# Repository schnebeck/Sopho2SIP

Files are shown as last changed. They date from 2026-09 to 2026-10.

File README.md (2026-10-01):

# ErgoLine D340 – Protokoll der PC-Schnittstelle

Offene Dokumentation des seriellen Protokolls, mit dem ein PC ein Philips-Systemtelefon **ErgoLine D340**
(Anlage **Sopho iS3000**, Telekom-Variante Octophon 340) steuert: Anrufe erkennen – mit Anrufernummer –,
annehmen, wählen und auslösen. Ziel: Jede und jeder soll damit einen eigenen TAPI- oder SIP-Daemon bauen können.

**➜ Spezifikation lesen: [schnebeck.github.io/Sopho2SIP/protokoll.html](https://schnebeck.github.io/Sopho2SIP/protokoll.html)**
(im Repository: [`docs/protokoll.html`](docs/protokoll.html))

Die Spezifikation enthält Rahmenformat, alle Meldungen und Aufträge, Zeitverhalten, Ablauf- und Zustandsdiagramme,
die Zuordnung zu SIP und einen Leitfaden für den Daemon. Jede Angabe ist gekennzeichnet als
**bestätigt** (am Gerät gemessen), **Treiber** (aus dem Philips-Treiber abgeleitet) oder **vermutet**.

## Kurzfassung

| | |
|---|---|
| Anschluss | 9-polige Buchse hinten am Telefon, 1:1-Kabel, Pin 2/3/5 |
| Freischaltung | am Telefon: Merkmale → Optionen → „TAPI: Sprache über Telefon“ = Ein |
| Leitung | 1200 Baud, 8O1 |
| Rahmen | `Klasse · Länge · Nutzdaten` – ohne Prüfsumme, ohne Start-/Endzeichen |
| Klassen | `01` Auftrag PC · `02` Meldung Telefon · `03` REJ · `04` ACK · `05` ERR |
| Meldungen | `30` RINGING (mit Anrufernummer) · `31` CONNECTED · `32` DISCONNECTED · `36` DIALTONE · `39` RELEASED · `3e` PROCEEDING · … |
| Aufträge | Anmelden `01 02 01 00` · Wählen `01 L 19 00 98 70 …` · Annehmen `01 02 14 00` · Auflegen `01 02 13 00` |

## Stand

- Empfangsrichtung vollständig mitgeschnitten und entschlüsselt (Anruf mit Nummer, Wahl, Verbindung, Auslösung).
- Senderichtung aus dem originalen Philips-Treiber abgeleitet; der erste Test am Gerät steht aus
  ([`docs/testplan.md`](docs/testplan.md)).
- Offene Fragen stehen am Ende der Spezifikation.

## Weitere Dokumente

| Datei | Inhalt |
|---|---|
| [`docs/protocol.md`](docs/protocol.md) | Arbeitsnotizen zum Protokoll mit Log-Verweisen |
| [`docs/audio_verkabelung.html`](https://schnebeck.github.io/Sopho2SIP/audio_verkabelung.html) | Schaltplan: Audio-Buchse über 600-Ω-Übertrager an die USB-Soundkarte (vorläufig) |
| [`docs/hardware.md`](docs/hardware.md) | Pinbelegung, Messwerte, Menüpunkte, Wartungsmodus des Telefons |
| [`docs/sackgassen.md`](docs/sackgassen.md) | Irrwege, z. B. der inkompatible Octophon-Treiber mit AT-Befehlen |
| [`docs/testplan.md`](docs/testplan.md) | nächste Tests am Gerät |
| [`logs/INDEX.md`](logs/INDEX.md) | Mitschnitte, die die Angaben belegen (Rufnummern durch Platzhalter ersetzt) |
| [`ref/ergoline_tsp/QUELLE.md`](ref/ergoline_tsp/QUELLE.md) | Herkunft des Philips-Treibers (Wayback Machine) mit Prüfsummen |

## Referenzimplementierung (experimentell)

Python 3 mit `pyserial`, keine weiteren Abhängigkeiten:

- `gateway/ergoline/protocol.py` – Rahmen, Meldungen, Aufträge (ohne Ein-/Ausgabe)
- `gateway/ergoline/link.py` – serielle Verbindung mit Quittung und Sitzungslog
- `gateway/ergoline/zustand.py` – Zustandsautomat nach dem Vorbild des Philips-Treibers
- `gateway/sopho2sipd.py` – Daemon: Verbindung, Anmeldung, Keepalive, Anrufdatensätze als JSON-Datei/Webhook ([`docs/anrufdaten.md`](docs/anrufdaten.md))
- `tools/ergo.py` – Mitschnitte dekodieren, mitlesen, Aufträge senden
- Tests: `python3 -m unittest discover -s gateway/tests -v`

```
tools/ergo.py decode logs/serial_20260930_163534.log
gateway/sopho2sipd.py --wiedergabe logs/serial_20260930_163534.log --anrufe -
```

Die Spezifikation wird mit `tools/build_protokoll_doc.py` aus `docs/protokoll.tpl.html` erzeugt.

## Nicht enthalten: der Philips-Treiber

Der Philips-Treiber (`Ergoline.tsp`), Handbuch-Auszüge und das Benutzerhandbuch sind urheberrechtlich geschützt
und liegen nicht im Repository. Der Treiber ist in der Wayback Machine archiviert:

- Direkt-Download: [ergoline.zip (Wayback Machine, 2010-12-01)](https://web.archive.org/web/20101201193039id_/http://tapicall.de/tapi-treiber/nec_philips/telefone/ergoline-serie/ergoline_d330/ergoline.zip)
- SHA-256 `ergoline.zip`: `d278ae82b84d656354e80f650fbd9ae9816d62526e92ea5dcb5483e05b374daf`
- SHA-256 `Ergoline.tsp` (im ZIP): `2b5b2b3e2e3ff51a2ca666b7bc874e9e9d81551a3f67c5357ea8ea297f50b282`

Weitere Fundstellen: [`ref/ergoline_tsp/QUELLE.md`](ref/ergoline_tsp/QUELLE.md) und Abschnitt Quellen der Spezifikation.

## Lizenz

Der Code (`gateway/`, `tools/`) steht unter der **GNU General Public License v3.0 oder später**
(`GPL-3.0-or-later`, siehe [`LICENSE`](LICENSE)). Für die Dokumentation gilt keine gesonderte Lizenz.

## Vorsicht

Eine Telefonanlage lässt sich nicht beliebig zurücksetzen. Nur dokumentierte Aufträge senden, nichts raten, und am
Telefon weder das Service-Menü noch die Wartungscodes 31–34 benutzen.

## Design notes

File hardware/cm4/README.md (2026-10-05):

# Sopho2SIP-Träger für Compute Module 4 (Entwurf 0.3)

Trägerplatine für das Raspberry Pi **Compute Module 4** als Gerät zum Einstecken: alle Kabel hinten, kurze Wege zur
D340, vorne µSD, Status-LEDs und drei Taster (Annehmen, Konfiguration, Ein/Aus); Lüfter temperaturgesteuert;
Gehäuse aus dem 3D-Drucker.

- **Speicher:** CM4 mit **eMMC** *oder* **CM4 Lite** mit **µSD-Karte**. Der Sockel ist immer bestückt. Beim
  eMMC-Modul sind die SD-Pins im Modul offen, der Sockel bleibt dann ungenutzt.
- **Netz:** **WLAN** über das CM4 mit Funk (Antenne auf dem Modul, zur linken Platinenkante; oder U.FL)
  *oder/und* **Ethernet 10/100** (RJ45 mit Übertrager). Der Betrieb wird per Software gewählt.
- **D340:** isolierte RS-232 (ADuM5211 + MAX3232, **4P4C-Buchse**) und Sprechweg über zwei Übertrager (RJ12).
  Zur D340 führt ein Adapterkabel 4P4C → DE9-Stecker (4P4C 1 → 5 GND, 2 → 2 RxD, 3 → 3 TxD).

| Datei | Inhalt |
|---|---|
| `erzeuge_schaltplan.py` | hierarchischer Schaltplan: `SOLL_*` (Verbindungen je Blatt), `blatt_*()` (Zeichnung), `main()` (Wurzelblatt) |
| `erzeuge_layout.py` | Leiterplatte aus der KiCad-Netzliste: Platzierung, Lagen, Flächen, Sperrzonen, Regeln, Routing, DRC, Fertigungsdaten |
| `erzeuge_bestellliste.py` | `stueckliste_digikey.csv` mit Herstellernummern und Digikey-Bestand |
| `sopho2sip-cm4.kicad_sch`, `*.kicad_sch` | Wurzelblatt und Kindblätter (erzeugt) |
| `sopho2sip-cm4.kicad_pcb`, `.kicad_dru` | Leiterplatte und JLCPCB-Regeln (erzeugt) |
| `sopho2sip.kicad_sym`, `sym-lib-table`, `fp-lib-table` | Projektbibliotheken; eigene Footprints in `hardware/bibliothek/` |
| `sopho2sip-cm4.pdf` | alle 9 Schaltplanblätter |
| `netzliste.txt`, `stueckliste.csv` | Soll-Netzliste, KiCad-Stückliste |
| `handlage/`, `.generiert.json` | von Hand nachgebesserte Blätter; Fingerabdrücke der zuletzt erzeugten Zeichnung |

Neu erzeugen und prüfen:
```
hardware/bibliothek/erzeuge_footprints.py         # eigene Footprints (Übertrager, RJ12, DF40 mit Pins 101–200)
hardware/cm4/erzeuge_schaltplan.py --pruefen      # ERC + Abgleich der Netzliste mit SOLL
hardware/cm4/erzeuge_layout.py --routen --pruefen # Platine, FreeRouting, DRC
hardware/cm4/erzeuge_layout.py --nur-fertigung    # Gerber/Bohrdaten/Bestückung/STEP/Bild nach fertigung/
hardware/cm4/erzeuge_bestellliste.py
```
Die UUIDs sind reproduzierbar: Schaltplan und Platine bleiben beim Neuerzeugen verknüpft („Platine aus Schaltplan
aktualisieren“ in KiCad funktioniert weiter).

**Zeichnung von Hand nachbessern:** Blätter in KiCad schöner setzen (Bauteile, Beschriftungen, Leitungen, Labels
verschieben) und speichern, dann den Generator laufen lassen. Er erkennt die geänderten Blätter am Fingerabdruck der
Zeichnung, prüft die Netzliste gegen SOLL und übernimmt sie nach `handlage/`. Ab dann kommt die Zeichnung dieser
Blätter von dort; Werte, Footprints und Symbole weiter aus SOLL (in KiCad geänderte Werte werden mit Hinweis
zurückgesetzt). Ändert die Handarbeit eine Verbindung, schreibt der Generator nichts und nennt die Abweichung.
```
hardware/cm4/erzeuge_schaltplan.py --pruefen                          # Änderungen im Projektordner übernehmen
hardware/cm4/erzeuge_schaltplan.py --handlage-aus ~/kopie --pruefen    # … aus einer Kopie des Projekts
hardware/cm4/erzeuge_schaltplan.py --handlage-verwerfen Bedienung      # Blatt wieder vom Generator zeichnen lassen
```
Kommt in SOLL ein Bauteil auf einem Blatt mit Handlage hinzu (oder fällt weg), bricht der Generator ab: das Blatt in
KiCad nachziehen oder die Handlage verwerfen.

**Texte** (Hinweiskästen, Texte, Blocktitel) gehören dem Generator. In KiCad geänderte Texte schreibt der Generator
an die Stelle im Quelltext zurück, an der sie entstehen (`p.notiz(…)`, `p.text(…)`, `rahmen_(…)`); ein neuer Absatz
im Kasten wird ein weiteres Argument von `notiz`. Ersetzt wird nur, wenn dort feste Literale genau den bisherigen
Text ergeben; sonst bleibt der Text als Handtext in `.generiert.json` und wird gemeldet. Ändert sich nur Text, nicht
die Lage, entsteht keine Handlage. In KiCad neu angelegte oder gelöschte Texte meldet der Generator nur.
Hinweise stehen in Textkästen (`notiz`): KiCad bricht innerhalb der Kastenbreite um, die Höhe schätzt der Generator.

## Blätter und Bauteile

| Blatt | Bauteile | Warum |
|---|---|---|
| CM4 | J11/J12 **Hirose DF40C-100DS-0.4V(51)** (1,5 mm Stapelhöhe), C40/C41, H5–H8 | Pinbelegung und Lage aus Datenblatt und CM4IO-Referenzlayout; **GPIO_VREF = 3,3 V** |
| | JP10 **nRPIBOOT** | gesteckt: das CM4 startet als USB-Gerät → `rpiboot` über USB-C, eMMC erscheint als Laufwerk |
| | D10 (ACT), Q10 **BSS84** + D11 (PWR) | Aktivitäts-Pin senkt bis 20 mA; PI_LED_nPWR muss laut Datenblatt gepuffert werden |
| Versorgung | J10 **USB-C** GCT USB4105, F1 Polyfuse 2 A, D12 **SMAJ5.0CA**, R10/R11 5,1 kΩ, U10 **USBLC6-2SC6** | eine Buchse für 5 V und USB 2.0 (rpiboot) |
| µSD | J13 Hirose DM3AT, U11 **AP22804AW5**, R14 12 kΩ | Lastschalter für die Kartenspannung wie Datenblatt (dort RT9742) |
| Ethernet | J14 **Würth 7499010211A** (RJ45 mit Übertrager, LEDs), U12 **TPD4E05U06**, C45, R15/R16 | Mittelanzapfungen über 100 nF an GND, ESD an den Paaren, LEDs low-aktiv |
| Audio-Codec | U2 **TI TLV320AIC3204** (VQFN-32), U6 Oszillator 12 MHz, U4 AP2112K-3.3 | **WM8731 ist abgekündigt**, SGTL5000/WM8960 ebenso bzw. nicht lieferbar. Der AIC3204 hat einen Linux-Treiber (`tlv320aic32x4`); Vorlage für das Overlay ist `audiosense-pi` (I²C 0x18, MCLK 12 MHz, Reset an GPIO26). **I²C an GPIO0/1 (I2C0)**, weil GPIO3 der Ein/Aus-Taster ist. LOL treibt den 600-Ω-Übertrager (Last ≥ 600 Ω laut Datenblatt) |
| Sprechweg | T1/T2 **Bourns SM-LP-5001** (600:600, 2 kV), J2 **Würth 615006138421** (RJ12/6P6C) | Amphenol 54601 ist abgekündigt |
| RS-232 | U3 **ADuM5211**, U5 **MAX3232E**, J3 **Würth 615004143821** (4P4C liegend) | statt DE9 (31 mm Kante, 13 mm hoch): verriegelnd, klein, nicht mit RJ12/RJ45 verwechselbar |
| CM4 selbst | M1 Platzhalter | steht in der Stückliste, wird gesteckt (nicht in den Bestückungsdaten); 3D-Modell 1,5 mm über J11/J12 |
| Bedienung | SW1 Annehmen/Auflegen (GPIO25), **SW2 Konfiguration (GPIO27)**, **SW3 Ein/Aus (GPIO3)**, D1–D3 (GPIO23/24/22) | D3 + SW2 für Einstellungen am Gerät; alle LEDs vorne für Lichtleiter |
| | SW3, R9 (unbestückt) | **Ein/Aus mit einem Taster:** im Betrieb fährt `gpio-shutdown` sauber herunter; im Halt weckt der Bootloader das CM4 über GPIO3 (`WAKE_ON_GPIO=1`, Werkseinstellung). GLOBAL_EN bleibt unbenutzt (Datenblatt: nur nach dem Herunterfahren auf Low ziehen) |
| Lüfter | Q11 **AO3400A**, D13 **MBR140SFT1G**, R17/R18, C46, J15 **JST PH 2-polig** | 5-V-Lüfter, Low-Side-Schalter an GPIO12 (PWM-fähig); die SoC-Temperatur des CM4 steuert über `gpio-fan` |

Die vollständige Bestellliste mit Digikey-Nummern und dem am 2026-10-03 geprüften Bestand steht in
`stueckliste_digikey.csv`. Keramikkondensatoren und Widerstände sind Standardteile; deren Bestand schwankt, der
Digikey-BOM-Manager schlägt gleichwertige Teile vor.

## Leiterplatte

- **Maße:** 110 × 85 mm, 4 Lagen, 1,6 mm, JLCPCB-Aufbau **JLC04161H-7628** (bei der Bestellung „Impedance Control“
  mit diesem Aufbau wählen).
- **Lagen:** F.Cu Signale · **In1 GND** · **In2 +3V3** · B.Cu Signale. Außenlagen nach dem Routing mit Masse gefüllt.
- **Impedanz** (berechnet, mit dem JLC-Rechner gegenprüfen): Ethernet 100 Ω differenziell = 0,20 mm / 0,17 mm,
  USB 90 Ω = 0,22 mm / 0,13 mm (Mikrostreifen über 0,21 mm Prepreg).
- **Anordnung:** hinten USB-C, RJ45, DE9, RJ12; CM4 links mit der Antenne zur linken Kante (kupferfreie Zone
  9,5 × 15 mm auf allen Lagen, Datenblatt: mind. 8 × 15 mm); vorne µSD, LEDs, Taster.
- **Isolation:** GND_ISO (RS-232) und GNDA (Sprechweg) sind eigene Bereiche mit eigenen Flächen auf allen Lagen.
  1 mm breite kupferfreie Trennstreifen auf allen Lagen; nur der ADuM5211 und die Übertrager überbrücken sie.
- **Regeln:** JLCPCB-Standard (Bahn/Abstand ≥ 0,09 mm, Bohrung ≥ 0,15 mm, Kupfer zur Kante ≥ 0,3 mm), in
  `sopho2sip-cm4.kicad_dru`; Standardbahn 0,15 mm, Durchkontaktierung 0,3/0,55 mm.
- **Routing:** Der Generator setzt zuerst selbst eine Durchkontaktierung an jedes SMD-Pad der Ebenennetze (GND,
  +3V3, GND_ISO, +3V3_ISO, GNDA; 144 Stück, mit Kollisionsprüfung), dann routet **FreeRouting 1.9.0** die übrigen
  Netze (Specctra DSN/SES, 30 Durchgänge, rund eine Stunde). FreeRouting 1.9 braucht eine Oberfläche und läuft
  unsichtbar über `xvfb-run` (Paket `xvfb`); das Werkzeug wird nach `hardware/.werkzeug/` geladen und per SHA-256
  geprüft. FreeRouting 2.x wurde verworfen: Telemetrie ab Werk an, hielt die Durchgangszahl nicht ein.
- **Stand:** vollständig geroutet, **DRC ohne Verstöße**, keine offenen Verbindungen, Schaltplan und Platine stimmen
  überein. Ethernet und USB sind vom Router als Einzelleitungen mit der Paarbreite verlegt, nicht als gekoppelte
  Differenzpaare (für 10/100 und USB 2.0 auf diesen Längen unkritisch; vor der Bestellung ansehen).
- **3D-Modelle:** CM4 offiziell von Raspberry Pi, die übrigen Herstellermodelle (Würth, Hirose, Bourns, ECS) liegen
  nur lokal in `hardware/bibliothek/3d/` (nicht weitergebbar, Quellen und Prüfsummen in `QUELLEN.md`).
  `hardware/bibliothek/richte_3d_aus.py` richtet sie auf die Footprints aus; die Steckerlagen sind im Rendering von
  unten geprüft (alle Pins, Zapfen und Schirmlaschen mittig in ihren Bohrungen).
- `--nur-nacharbeit` erneuert Beschriftung, Bestückungsattribute und Flächen ohne neues Routing. Konstruiert wird
  bei (100, 100); zum Schluss rückt die Platine auf dem A4-Blatt nach (93, 45), frei vom Schriftfeld. Alle
  Bauteiltexte stehen waagerecht.
- **Beschriftung:** Platinentexte stehen in `beschriftung.json` (Inhalt, Lage, Drehung, Größe, Strichstärke, Lage
  der Ebene, Sichtbarkeit, Ausrichtung, gespiegelt, fett, kursiv, aufrecht, ausgespart), dazu Abweichungen der
  Bauteiltexte (Referenz, Wert, eigene Footprint-Texte; Lage relativ zum Bauteil). In KiCad geänderte, neue oder
  gelöschte Beschriftungen übernimmt jeder Lauf von `erzeuge_layout.py` (außer `--nur-pruefen`/`--nur-fertigung`)
  vorab nach `beschriftung.json`; Vergleichsgrundlage ist `.beschriftung_stand.json` (Stand des letzten Laufs).
  Überlappungen meldet der DRC (`silk_overlap`). Bauteillagen und Leiterbahnen werden nicht zurückgeführt.

## Konfiguration (`/boot/firmware/config.txt`)
```
dtparam=i2s=on
dtparam=i2c_vc=on          # I2C0 an GPIO0/1 für den Codec
dtoverlay=sopho2sip-codec  # noch zu schreiben (nach audiosense-pi, aber i2c0): TLV320AIC3204, 0x18, 12 MHz, Reset GPIO26
dtoverlay=gpio-shutdown,gpio_pin=3   # Ein/Aus-Taster: Druck = sauber herunterfahren
dtoverlay=gpio-fan,gpiopin=12,temp=60000   # Lüfter ab 60 °C SoC-Temperatur
dtoverlay=uart3            # GPIO4/5 → /dev/ttyAMA3 (Name nach dem Booten prüfen)
dtparam=ant2               # nur bei externer WLAN-Antenne (U.FL)
```
Bootloader-EEPROM: `WAKE_ON_GPIO=1` (Werkseinstellung) und `POWER_OFF_ON_HALT=0` lassen, sonst weckt der Taster
nicht. Taster, langer Druck zum Ausschalten und STATUS-LED beim Herunterfahren richtet `tools/ein_aus_einrichten.sh`
ein (Ablauf in `docs/betrieb.md`). eMMC beschreiben: JP10 stecken, USB-C mit dem Rechner verbinden, `rpiboot` ausführen, Image schreiben, JP10 ziehen.

## Vor der Fertigung prüfen (offen)
- **Codec:** Overlay für I2C0 schreiben; Mixer-Einstellungen (IN1_L → ADC, DAC → LOL) mit `amixer` festlegen.
- **Ein/Aus:** Wecken über GPIO3 am CM4 erproben (bei Bedarf R9 als Pull-up bestücken).
- **Lüfter:** Lüftertyp festlegen (5 V, ≤ 200 mA, 2-polig mit JST-PH-Stecker oder umcrimpen) und im Deckel über dem
  CM4 vorsehen.
- **Ethernet:** Das CM4 hat einen Gigabit-PHY. Die 2-Paar-Buchse trägt nur 10/100. Prüfen, ob der PHY bei nur zwei
  Paaren sicher auf 100 Mbit herunterschaltet, sonst per `ethtool` festlegen.
- **3,3 V vom CM4:** höchstens 600 mA. Verbraucher: Codec (Digital, Oszillator), ADuM5211 (Logikseite), µSD-Karte
  (bis ~100 mA), LEDs. Summe aus den Datenblättern bilden.
- **AP22804 statt RT9742:** Pinbelegung, EN-Polarität und Strombegrenzung gegen das Datenblatt prüfen.
- **USB_OTG_ID** (Pin 101) ist offen. Normalbetrieb mit `dtoverlay=dwc2,dr_mode=…` festlegen.
- **RJ12-Footprint:** aus der Würth-Zeichnung abgeleitet; Lage der Steckseite zur Platinenkante am Muster prüfen.
- **Mechanik:** Gehäuse für den FDM-Druck in `hardware/gehaeuse/` (Lichtleiter über D1–D3, D10, D11; Biegezungen mit
  Stößel über SW1–SW3; Lüfter 30 mm). Erstdruck steht aus.
- Die Prüfpunkte des HAT gelten weiter (ADuM5211, Übertrager, RJ12-Kabel, MAX3232E): `hardware/hat/README.md`.

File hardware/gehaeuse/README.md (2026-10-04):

# Gehäuse für den CM4-Träger (FDM-Druck)

Zweiteiliges Gehäuse für `hardware/cm4` (Leiterplatte 110 × 85 mm), druckbar ohne Stützmaterial.
Außenmaß **115,6 × 90,6 × 25,1 mm**. Die Buchsen liegen hinten, Tasten und Anzeigen oben an der Vorderkante.

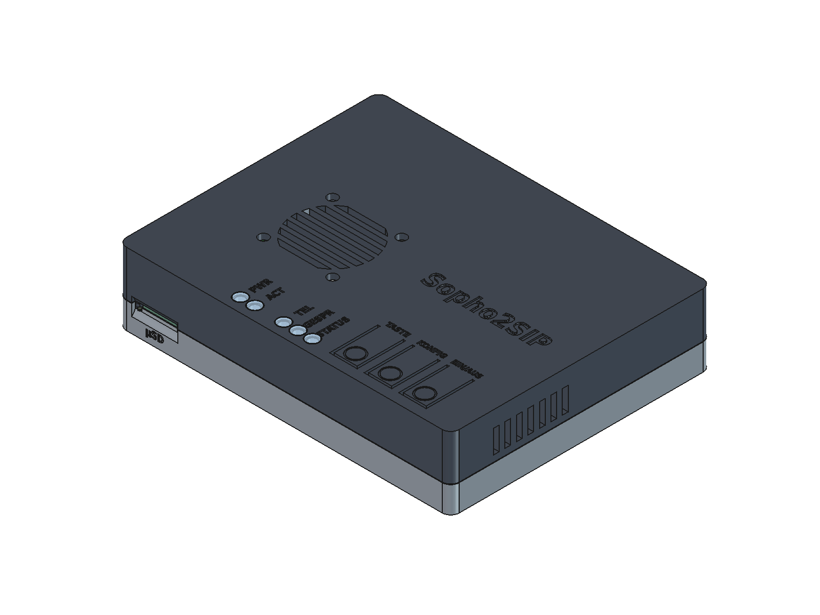
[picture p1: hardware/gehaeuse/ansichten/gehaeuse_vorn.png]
Gehäuse


| Teil | Datei | Drucklage |
|---|---|---|
| Unterschale | `druck/unterschale.stl` | Boden auf dem Druckbett |
| Deckel | `druck/deckel.stl` | Oberseite auf dem Druckbett (kopfüber) |
| 5 Lichtleiter | `druck/lichtleiter_5x.stl` | Kopf auf dem Druckbett |

`gehaeuse.step` und `gehaeuse.FCStd` enthalten die Teile in Einbaulage.

## Aufbau

- **Trennebene** auf Höhe der Platinenoberseite. Die äußere Wandhälfte der Unterschale steht 2 mm hoch und greift
  in eine Stufe des Deckels; das zentriert den Deckel.
- **Verschraubung:** 4 × M2.5 von unten durch die Unterschale und die Bohrungen H1–H4 der Platine in
  Gewindeeinsätze der Deckelsäulen. Die Platine liegt auf Stützen und wird zwischen Stütze und Säule geklemmt.
  Unter jedem Taster stützt ein Zapfen die Platine gegen den Tastendruck.
- **Tasten** (SW1 Taste, SW2 Konfig, SW3 Ein/Aus): Biegezungen im Deckel (16 × 8 mm, von innen auf 1,2 mm gedünnt,
  Gelenk hinten). Der Stößel Ø 4 mm steht 0,35 mm über der Tasterkappe. Ein Ring markiert die Druckstelle.
- **Anzeigen** (D11 PWR, D10 ACT, D1 TEL, D2 GESPR, D3 STATUS): Lichtleiter Ø 3 mm in Röhren, die bis 0,6 mm über
  die LED reichen und Übersprechen zwischen den LEDs verhindern. Die Köpfe liegen bündig in Senkungen.
- **Buchsen hinten:** USB-C (Ausschnitt 12,4 × 6,6 mm für Steckertüllen), RJ45 LAN, 4P4C D340 PC, RJ12 D340 Audio;
  Beschriftung unter den Ausschnitten.
- **µSD vorn:** Schlitz mit Griffmulde. Die Karte (Push-Push) wird mit dem Fingernagel betätigt. Bei einem CM4 mit
  eMMC bleibt der Schlitz unbenutzt.
- **Kühlung:** Lüfter 30 × 30 × 7 mm unter dem Deckel über dem SoC des CM4 (3,9 mm Luft). Er saugt durch das Gitter
  im Deckel an und bläst auf das CM4; die Luft tritt durch die Schlitze in den Seitenwänden aus.
  Lüfter mit der Aufkleberseite zur Platine einbauen (Blasrichtung meist zum Aufkleber).
  Anschluss an J15 (JST PH, 2-polig).

## Zukaufteile

| Menge | Teil | Hinweis |
|---|---|---|
| 4 | Gewindeeinsatz M2.5, L 5,7 mm, Ø 4 mm (z. B. Ruthex RX-M2.5x5.7) | Loch Ø 3,6 × 6,5 mm |
| 4 | Zylinderschraube ISO 4762 M2.5 × 10 | Kopf versenkt (Ø 5,2 × 2,6 mm) |
| 1 | Lüfter 30 × 30 × 7 mm, 5 V, Stecker JST PH 2-polig | Lochabstand 24 mm |
| 4 | Blechschraube M3 × 8 … 10 (meist beim Lüfter) | von außen durch den Deckel |
| 4 | Klebefuß Ø ≤ 10 mm | Mulden 0,6 mm tief |

## Druck

- **Material:** PETG oder ASA (das CM4 erwärmt das Innere; PLA wird ab ~55 °C weich). Lichtleiter aus klarem PETG.
- Düse 0,4 mm, Schicht 0,2 mm, 3 Wandlinien, 20 % Füllung. Lichtleiter: 100 % Füllung, langsam.
- Kein Stützmaterial nötig. Beim Deckel liegen die Beschriftungen auf dem Druckbett; die vertieften Buchstaben
  werden in der ersten Schicht überbrückt.
- Die Biegezungen brauchen ein zähes Material (PETG/ASA). Ist die Taste zu schwer, `ZUNGE_D` verkleinern.

## Montage

1. Gewindeeinsätze mit dem Lötkolben in die vier Deckelsäulen setzen (PETG ~230 °C).
2. Lichtleiter von außen in den Deckel stecken (straff; notfalls ein Tropfen Klebstoff unter den Kopf).
3. Lüfter von innen an den Deckel schrauben.
4. CM4 auf den Träger stecken. Platine mit den Buchsen nach hinten in die Unterschale legen.
5. Lüfterkabel an J15 stecken, Deckel aufsetzen, von unten verschrauben. Klebefüße aufkleben.

## Erzeugen und prüfen

```
python3 hardware/gehaeuse/erzeuge_masse.py          # masse.json und platine_bestueckt.step (≈ 5 min) aus KiCad
flatpak run --command=freecadcmd org.freecad.FreeCAD $PWD/hardware/gehaeuse/freecad_gehaeuse.py
python3 hardware/gehaeuse/vorschau.py               # Querschnitte → vorschau_schnitte.png
xvfb-run -a -s "-screen 0 1600x1200x24" flatpak run org.freecad.FreeCAD $PWD/hardware/gehaeuse/freecad_ansichten.py
```

Alle Maße stehen als Konstanten am Anfang von `freecad_gehaeuse.py`. Die Bauteillagen kommen aus der Platine
(`masse.json`), die Bauteilhöhen aus dem bestückten STEP.

Das Skript prüft das Gehäuse gegen die bestückte Platine (`pruefung.txt`): keine Überschneidung, Stößel 0,35 mm
über den Tastern, Lüfter 3,87 mm über dem CM4. Die Querschnitte durch Taster, LED und Schraubsäule zeigt
`vorschau_schnitte.png`.

## Offen (nach dem ersten Druck prüfen)

- Passung der Gewindeeinsätze, der Lichtleiter (Bohrung 3,4 / Stab 3,0) und des Deckels auf dem Zentrierrand.
- Tastengefühl und Leerweg (`TASTE_SPIEL`, `ZUNGE_D`).
- Ob die Steckertüllen der eigenen USB-C- und RJ-Kabel in die Ausschnitte passen.
- Ob die Lüfterleistung reicht (Temperatur des CM4 unter Last mit `vcgencmd measure_temp`).

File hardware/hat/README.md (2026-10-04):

# Sopho2SIP-HAT (Entwurf 0.2)

HAT für den Raspberry Pi 4, der die Verbindung zur ErgoLine D340 auf eine Platine bringt: **isolierte RS-232** zur
PC-Schnittstelle (statt FTDI-Adapter) und **Audio-Codec mit Übertragern** zur Audio-Buchse (statt UCA222).

| Datei | Inhalt |
|---|---|
| `erzeuge_schaltplan.py` | erzeugt den Schaltplan aus den KiCad-Standardbibliotheken: `SOLL` (Verbindungen) und je Block eine Zeichenfunktion (`pi_leiste`, `hat_eeprom`, `codec`, `sprechweg`, `rs232`, `bedienung`); Generator-Grundlage `hardware/kicadgen.py` |
| `sopho2sip-hat.kicad_sch/.kicad_pro` | KiCad-10-Projekt (erzeugt) |
| `sopho2sip-hat.pdf` | Schaltplan zum Ansehen |
| `netzliste.txt` | Soll-Netzliste (Netz → Pins) aus `SOLL` |
| `stueckliste.csv` | Stückliste (KiCad-Export) |

Neu erzeugen und prüfen:
```
hardware/hat/erzeuge_schaltplan.py --pruefen     # ERC + Abgleich der KiCad-Netzliste mit SOLL (Stand: 0 / 0)
kicad-cli sch export pdf -o hardware/hat/sopho2sip-hat.pdf hardware/hat/sopho2sip-hat.kicad_sch
```
Der Plan ist gezeichnet wie von Hand: Funktionsblöcke mit Rahmen, Signalfluss von links nach rechts, Leitungen
innerhalb der Blöcke, Abblockkondensatoren an den Versorgungsschienen, Labels nur zwischen den Blöcken, galvanische
Trennung als Strichpunktlinie. Die Prüfung vergleicht die Pin-Gruppen der KiCad-Netzliste mit `SOLL`; so kann die
Zeichnung umgestaltet werden, ohne unbemerkt Verbindungen zu ändern. Änderungen am besten im Skript; wer in KiCad
weiterzeichnet, verlässt den Generator (dann ERC und Netzliste dort prüfen).

Versorgungsnetze: `GND`, `+3V3`, `+5V` (Pi), `+3.3VA` (Codec analog), `GNDA` (Telefonseite Audio),
`GND_ISO`, `+3V3_ISO` (isolierte RS-232-Seite) – jeweils als Power-Symbol mit sichtbarem Netznamen.

## Blöcke und Begründungen

| Block | Bauteile | Warum |
|---|---|---|
| Pi-Anschluss | J1 Buchsenleiste 2×20 | HAT-Standard |
| Seriell | **UART3** an GPIO4 (TXD3) / GPIO5 (RXD3) | PL011 – der Mini-UART (GPIO14/15) kann **keine Parität**, die D340 braucht **1200 Bd 8O1**; GPIO14/15 bleiben für Bluetooth, GPIO0/1 für das HAT-EEPROM |
| Trennung | U3 **ADuM5211** | Digitaltrenner (je ein Kanal hin/zurück) **mit eingebauter isolierter Versorgung** (VSEL = GND_ISO → 3,3 V) – ein Chip statt Trenner + DC-DC |
| RS-232 | U5 **MAX3232** (isolierte Seite), J3 **DE9-Stecker** | Pegel ±5 V wie gemessen; Stecker wie am PC (DTE): Pin 2 RxD, Pin 3 TxD, Pin 5 GND → vorhandenes 1:1-Kabel |
| Audio | U2 **WM8731SEDS** (SSOP-28, handlötbar), Y1 12,288 MHz | Linux-Treiber, Overlay `rpi-proto` (genau dieser Codec); 8 kHz direkt; ADC-Hochpass macht `dcsperre` überflüssig |
| Sprechweg | T1/T2 **Bourns SM-LP-5001** (600:600), C21/C24 1 µF, J2 **RJ12** Würth 615006138421 | wie die erprobte Verkabelung (`docs/audio_verkabelung.html`): beide Richtungen galvanisch getrennt; **LHPOUT** (Kopfhörerverstärker) treibt T2 – LOUT ist nur für ≥ 10 kΩ |
| Teiler-Option | R4 = 0 Ω, R5 unbestückt | im Test war kein Teiler nötig (Pegel per Software); Option bleibt |
| Analogversorgung | U4 **AP2112K-3.3** aus 5 V | eigene, ruhige 3,3 V für AVDD/HPVDD |
| HAT-ID | U1 **24LC32**, R1/R2 3,9 kΩ, R3 + JP1 | HAT-Spezifikation: EEPROM an ID_SD/ID_SC, Adresse 0x50, WP hoch (JP1 schließen zum Schreiben) |
| Bedienung | D1/D2 an GPIO23/24, SW1 an GPIO25 | Telefon-Status / Gespräch / Annehmen-Auflegen (interner Pull-up) |

Galvanische Verhältnisse: Telefonseite (TEL_GNDA, ISO_GND) ist vom Pi (GND) **vollständig getrennt** – Audio über die
Übertrager, Seriell über den ADuM5211. Im bisherigen Aufbau war die serielle Masse die einzige leitende Verbindung.

## Konfiguration auf dem Pi (`/boot/firmware/config.txt`)
```
dtparam=i2s=on
dtoverlay=rpi-proto        # WM8731 (I²C 0x1A), Codec erzeugt die Takte aus 12,288 MHz
dtoverlay=uart3            # GPIO4/5 → /dev/ttyAMA3 (Name nach dem Booten prüfen)
```
Danach: Daemon mit `--port /dev/ttyAMA3`, baresip `audio_player/audio_source alsa,plughw:<Karte>,0`. Mit
HAT-EEPROM kann der Pi die Overlays auch selbst laden (EEPROM mit `eepromutils` beschreiben).

## Vor der Fertigung prüfen (offen)
- **ADuM5211:** VDD1 = 3,3 V (Logikpegel zum Pi) bei VDDP = 5 V zulässig? Polarität von VSEL; Ausgangsleistung für
  MAX3232 + ADuM-Seite 2 (einige mA). Datenblatt.
- **WM8731:** Quarzbeschaltung (Lastkapazität des gewählten Quarzes → C10/C11), unbenutzte Eingänge (RLINEIN, MICIN)
  laut Datenblatt beschalten oder offen lassen.
- **WM8731 ist abgekündigt** (Digikey, 2026-10). Der CM4-Träger (`hardware/cm4/`) nutzt deshalb den TI
  TLV320AIC3204; vor einem Bau des HAT den Codec-Block ebenso umstellen.
- **RJ12-Kabel:** Viele flache Telefonkabel sind gedreht (1↔6). Die Pinbelegung von J2 setzt ein 1:1 belegtes 6P6C
  voraus – mit dem Durchgangsprüfer gegen die D340-Buchse prüfen, sonst Belegung auf der Platine spiegeln.
- **Mechanik:** HAT-Maß 65 × 56,5 mm, Befestigungslöcher 58 × 49 mm; ein liegender DE9 ist hoch – evtl. auf die
  Kante setzen oder Pfostenstecker + Kabel.
- **ESD:** MAX3232**E** (±15 kV) wählen; TVS-Dioden an X_IN/X_OUT erwägen.
- Trägerplatine für das Compute Module 4 mit denselben Blöcken: `hardware/cm4/`.

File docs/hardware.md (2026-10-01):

# Hardware, Verkabelung, Messwerte

Stand 2026-09-30. Widerlegte Verdachte: siehe [`sackgassen.md`](sackgassen.md).

## Telefon
- ERGOLINE 340-2/LG INT (UPN), leitungsgespeist, kein Netzteil angeschlossen, nur 9-polige PC-Buchse (keine V.24-Option).
- Terminal-Software **V4.03.40.01** (Wartungscode 1, abgelesen 2026-09-30).
- Menüsprache Deutsch. Zuordnung (vermutet): Features = Merkmale, Toggle List = Optionen, Set Phone = Einstellungen.
- Merkmale → Optionen enthält „TAPI: Sprache über Zusatzgerät“ und „TAPI: Sprache über Telefon“.
  Stand: **Sprache über Telefon = Ein** (seit 2026-09-30 16:28, damit ist die PC-Schnittstelle aktiv),
  Sprache über Zusatzgerät = Aus.

## PC-Schnittstelle (DB9-Buchse am Telefon)
| Pin | Funktion | Ruhepegel (gemessen 2026-09-30) |
|---|---|---|
| 2 | TxD Telefon → PC | −5 V (am Telefon, Kabel ab) |
| 3 | RxD Telefon ← PC | 0 V am Telefon ohne Kabel; −5 V vom Adapter am Kabelende |
| 5 | GND | – |

Kabel: FTDI-Adapter (Stecker) → 1:1-Verlängerung → Telefon (Buchse). Loopback am Kabelende und Pegelmessung
bestätigen: Kabel 1:1, nicht gekreuzt. Rate/Format: **1200 Baud**, laut Treiber **8O1 + Xon/Xoff** (siehe `protocol.md`).

## Audio-Schnittstelle (RJ11 Unterseite)
| Pin | Funktion | Messwert |
|---|---|---|
| 1 | X_OUT | Gegenseite: Sprache −31 … −43 dBFS RMS, Spitzen −13 dBFS an der UCA222 (Eingang ohne Verstärkung) |
| 2 | X_IN | braucht „X-Eingang statt Mikrofon“; dann passt UCA222-Wiedergabe mit PCM −6 dB (Sprache bis −1 dBFS war leicht übersteuert) |
| 3 | GNDA | – |
Angeschlossen 2026-10-01 (Nutzer): 2 × Übertrager 600:600, C1/C2 1 µF, **ohne** Teiler R1/R2, Cinch `INPUT L`/`OUTPUT L`.
Pinlage wie in [`audio_verkabelung.html`](audio_verkabelung.html) (Pin 1 links) funktioniert in beiden Richtungen.
Messungen mit `tools/audio_test.sh` (Aufnahmen `logs/audio_*.wav`, nur lokal):
- Ruhe: −80 dBFS, kein Brummen; rechter (unbenutzter) Kanal −87 dBFS.
- **Kein Echo:** Testton auf X_IN erscheint auf X_OUT mit < −91 dBFS (Echodämpfung ≈ 75 dB) → X_OUT führt nur die
  Gegenseite, AEC unnötig.
- **X_IN ohne Merkmal 4f sehr leise** (1 kHz bei −16 dBFS kaum hörbar). Mit „X-Eingang statt Mikrofon“ (Merkmal `4f`,
  per FN-Taste oder Auftrag `01 03 26 00 4f`) passt der Pegel; der Daemon schaltet es bei PC-Gesprächen ein.
- PCM-Regler der UCA222 dauerhaft −6 dB (`alsactl store`). Der Drehregler der UCA222 wirkt nur auf den Kopfhörer.
- Vorzeitige Auslösung vom Pi gewählter Gespräche: kein Audioproblem, sondern der 30-s-Watchdog der D340
  (`docs/protocol.md`, Abschnitt 6).

## Messungen
| Datum | Messpunkt | Wert | Deutung |
|---|---|---|---|
| 2026-09-30 | Kabelende telefonseitig (Telefon ab), Pin 2–5 | 0 V | nur Empfänger des Adapters |
| 2026-09-30 | Kabelende, Pin 3–5 | −5 V | Sender des Adapters in Ruhe → Kabel 1:1 |
| 2026-09-30 | Telefonbuchse (Kabel ab), Pin 2–5 | −5 V | Sender des Telefons aktiv |
| 2026-09-30 | Telefonbuchse (Kabel ab), Pin 3–5 | 0 V | Eingang des Telefons |
| offen | Pin 3–5 bei angestecktem Telefon (Last) | – | nicht mehr nötig (Telefon reagiert) |

## Aus den Handbüchern
Quellen: Customer Engineer Manual https://www.manualslib.com/manual/846588/Philips-Ergoline-D330.html (CEM),
User Manual D340 https://www.manualslib.com/manual/715348/Sopho-Ergoline-D340.html (UM),
User Guide D325/D330 `ref/ergoline_tsp/guide_ergoline_d325_d330_english.pdf`. Seiten = PDF-Seiten.

**PC-Schnittstelle**
- Standard bei D330/D340, 1:1-Kabel, TAPI-Treiber auf Diskette (CEM S. 59). Keine Freischaltung beschrieben.
- Keine Baudrate dokumentiert oder einstellbar. Einzige Angabe: Wartungscode 63 „sends a signal from the PC
  interface at 1200 baud“ (CEM S. 72).
- Baudrate, Format, Flusssteuerung, AT-Befehle, S-Register gibt es nur für die **V.24-Option** (CEM S. 51–58;
  Einstellung per Download aus der Anlage, S. 32). Für uns nicht relevant.

**Menü und Merkmale**
- Menübaum: `docs/img/d340_menuebaum.png` (CEM S. 66). `*` = Special Mode (Passwort 2468), `**` = Service Mode (12687).
- Toggle List: „TAPI: speech via accessory“ = Sprachweg auf die Audio-Schnittstelle; „TAPI: speech via phone“ =
  Freisprechen/Hörer/Headset am Telefon (UM S. 45, Glossar S. 97/98). Einträge erscheinen nur, wenn die Anlage
  TAPI für die Nebenstelle unterstützt.
- „X-input instead of mic.“ nur über programmierte Funktionstaste (UM S. 98).
- Voice out „Headset“ oder „Handset without hook“ schaltet den Gabelumschalter ab; dann ist eine Taste
  „On/off hook key for voice“ nötig (UM S. 54).
- ASCII-Tastatur: Infrarot, Kanal 1–3 (CEM S. 62/63). Nichts mit der DB9 zu tun.
- Stromversorgung: leitungsgespeist; Netzteil (8 V~) nur für V.24-Option oder DSS-Module (CEM S. 10, 18, 19).
- **Service-Menü nicht anfassen** (`set TEI`, `reset data`, `download request`, `clean`).

**Wartungsmodus** (CEM S. 69–72)
- Aufruf: Features → SetPhone → SetMode → 12687, dann im Ruhezustand Shift, Hold, nach rechts scrollen, MAINTAIN.
  Testcode + OK, Ende mit CANCEL. Anrufe bleiben annehmbar.
- 1–6 Softwareversionen, 11–14 Display/Tasten/LED (13 ist Umschalter), 61 „Y signal 0 on PC interface“,
  **63 Signal an der PC-Schnittstelle mit 1200 Baud**, 64 X-Interface gespiegelt, 67 V.24.
- Nach Schnittstellentests Hardware-Reset empfohlen (Leitungskabel ziehen).
- **Nie verwenden:** Codes 31–34 (EEPROM löschen) und Tasten `*`, `3`, `5` beim Einstecken des Leitungskabels.

## Gateway
- Konsole: Laptop (KDE neon), Zugriff per `ssh sopho-gw`, Schlüssel `~/.ssh/id_ed25519_sopho-gw`.
- Pi: Raspberry Pi 4, Raspberry Pi OS Lite 64 bit (Debian 13 Trixie), Hostname `sopho-gw`, Nutzer `pi`.
  In Betrieb seit 2026-10-01. Netz: DHCP an eth0 in einem anderen Netz als der Laptop, erreichbar über VPN;
  `.local` geht dort nicht, die IP steht deshalb nur in `~/.ssh/config` des Laptops (nicht im öffentlichen Repo).
  - Image 2026-09-15-raspios-trixie-arm64-lite, per `dd` geschrieben; Erststart per cloud-init
    (`user-data`/`network-config` auf bootfs): Hostname, Nutzer `pi` nur SSH-Schlüssel + NOPASSWD-sudo,
    Europe/Berlin, de, DHCP eth0, avahi, kein WLAN.
  - Der erste Pi 4 (Bootloader 2023-01-11) brach mit `FAT read failed` / `Block device timeout` ab, obwohl
    Netzteil (5,09 V) und Karte (vollständig gelesen, rootfs bytegleich mit dem Image) in Ordnung waren.
    Ein anderer Pi 4 bootet mit derselben Karte; Ursache vermutlich SD-Slot des ersten Geräts.
  - Grundeinrichtung: `ssh sopho-gw 'bash -s' < tools/pi_bootstrap.sh` (2026-10-01 ausgeführt: Pakete, Gruppen
    `dialout`/`audio`, NTP synchron). Repo: `~/Sopho2SIP` (Klon von GitHub, Tests laufen mit Python 3.13).
  - Dienst `sopho2sipd` (`gateway/betrieb/sopho2sipd.service`), seit 2026-10-01 aktiv und nach Neustart geprüft.
    Aktualisieren: `ssh sopho-gw 'cd ~/Sopho2SIP && git pull && sudo systemctl restart sopho2sipd'`.
    Ereignisse: `journalctl -u sopho2sipd -f`; Anrufe: `~/.local/share/sopho2sip/anrufe.jsonl`.
- USB-RS232: FTDI FT232R, `/dev/serial/by-id/usb-FTDI_FT232R_USB_UART_A97WEQGD-if00-port0` (am Pi).
  Auch als Logikanalysator nutzbar (`tools/bitbang_scope.py`, synchroner Bitbang, Zugriff über Gruppe `plugdev`).
- UCA222: ALSA-Karte `hw:?` (noch nicht angeschlossen).

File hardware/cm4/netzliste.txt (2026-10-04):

# Netz: Pins (SOLL aus erzeuge_schaltplan.py; Blatt/Netz = lokal)
+3.3VA: C14.1 C15.1 C16.1 C20.1 U2.26 U4.5
+3V3: C12.1 C27.1 C30.1 C44.1 J11.78 J11.84 J11.86 J14.12 J14.9 Q10.2 R12.1 R14.1 R20.1 R9.1 U11.5 U2.30 U2.6 U3.1 U6.1 U6.4
+3V3_ISO: C33.1 C34.1 C39.1 U3.12 U3.20 U5.16
+5V: C19.1 C31.1 C32.1 C40.1 C41.1 C42.1 C46.1 D12.1 D13.1 F1.2 J11.77 J11.79 J11.81 J11.83 J11.85 J11.87 J15.1 U10.5 U3.9 U4.1 U4.3
Audio-Codec/AIC_AVDD: C17.1 U2.24
Audio-Codec/AIC_DVDD: C18.1 U2.29
Audio-Codec/AIC_IN_FREI: C26.1 U2.14 U2.15 U2.16 U2.20 U2.21
Audio-Codec/AIC_MCLK: U2.1 U6.3
Audio-Codec/AIC_REF: C25.1 U2.18
Bedienung/LED1_A: D1.2 R6.2
Bedienung/LED2_A: D2.2 R7.2
Bedienung/LED3_A: D3.2 R8.2
CM4/LED_ACT_A: D10.2 R12.2
CM4/LED_ACT_K: D10.1 J11.21
CM4/LED_PWR_A: D11.2 R13.2
CM4/LED_PWR_D: Q10.3 R13.1
CM4/LED_PWR_G: J11.95 Q10.1
CM4/nRPIBOOT: J11.93 JP10.1
CODEC_nRESET: J11.24 R20.2 U2.31
ETH_P0_N: J11.10 J14.2 U12.2
ETH_P0_P: J11.12 J14.1 U12.1
ETH_P1_N: J11.6 J14.6 U12.5
ETH_P1_P: J11.4 J14.3 U12.4
ETH_nLED2: J11.17 R15.2
ETH_nLED3: J11.15 R16.2
Ethernet/ETH_CT: C45.1 J14.4 J14.5
Ethernet/LED_G_K: J14.11 R16.1
Ethernet/LED_Y_K: J14.10 R15.1
GND: C12.2 C14.2 C15.2 C16.2 C17.2 C18.2 C19.2 C20.2 C25.2 C26.2 C27.2 C30.2 C31.2 C32.2 C40.2 C41.2 C42.2 C43.2 C44.2 C45.2 C46.2 D1.1 D11.1 D12.2 D2.1 D3.1 J10.A1 J10.A12 J10.B1 J10.B12 J10.SH J11.1 J11.13 J11.14 J11.2 J11.22 J11.23 J11.32 J11.33 J11.42 J11.43 J11.52 J11.53 J11.59 J11.60 J11.65 J11.66 J11.7 J11.71 J11.74 J11.8 J11.98 J12.107 J12.108 J12.113 J12.114 J12.119 J12.120 J12.125 J12.126 J12.131 J12.132 J12.137 J12.138 J12.144 J12.150 J12.155 J12.156 J12.161 J12.162 J12.167 J12.168 J12.173 J12.174 J12.179 J12.180 J12.185 J12.186 J12.191 J12.192 J12.197 J12.198 J13.6 J13.SH J14.8 J14.SH JP10.2 Q11.2 R10.2 R11.2 R18.2 SW1.2 SW2.2 SW3.2 T1.3 T2.2 U10.2 U11.2 U12.3 U12.8 U2.12 U2.17 U2.28 U2.33 U2.7 U3.10 U3.2 U3.5 U3.6 U3.8 U4.2 U6.2
GNDA: J2.3 R5.2 T1.2 T2.3
GND_ISO: C33.2 C34.2 C37.2 C38.2 C39.2 J3.1 U3.11 U3.13 U3.15 U3.16 U3.19 U5.10 U5.15
HP_L: C23.1 U2.22
I2C_SCL: J11.35 U2.9
I2C_SDA: J11.36 U2.10
I2S_BCLK: J11.49 U2.2
I2S_DIN: J11.27 U2.5
I2S_DOUT: J11.25 U2.4
I2S_LRCLK: J11.26 U2.3
LED_GESPRAECH: J11.45 R7.1
LED_STATUS: J11.46 R8.1
LED_TELEFON: J11.47 R6.1
LINE_IN: C22.2 U2.13
LUEFTER: J11.31 R17.1
Lüfter/LUEFTER_G: Q11.1 R17.2 R18.1
Lüfter/LUEFTER_N: D13.2 J15.2 Q11.3
RS-232/C1N: C35.2 U5.3
RS-232/C1P: C35.1 U5.1
RS-232/C2N: C36.2 U5.5
RS-232/C2P: C36.1 U5.4
RS-232/ISO_RXD: U3.18 U5.12
RS-232/ISO_TXD: U3.17 U5.11
RS-232/ISO_VN: C38.1 U5.6
RS-232/ISO_VP: C37.1 U5.2
RS-232/RS232_RXD: J3.2 U5.13
RS-232/RS232_TXD: J3.3 U5.14
SD_CLK: J11.57 J13.5
SD_CMD: J11.62 J13.3
SD_DAT0: J11.63 J13.7
SD_DAT1: J11.67 J13.8
SD_DAT2: J11.69 J13.1
SD_DAT3: J11.61 J13.2
SD_PWR_ON: J11.75 R14.2 U11.4
Sprechweg/T1_PRI: C21.2 T1.1
Sprechweg/T1_SEK: C22.1 T1.4
Sprechweg/T2_PRI: C23.2 T2.1
Sprechweg/T2_SEK: R4.1 T2.4
Sprechweg/X_IN: C24.2 J2.2
Sprechweg/X_IN_TEILER: C24.1 R4.2 R5.1
Sprechweg/X_OUT: C21.1 J2.1
TASTE: J11.41 SW1.1
TASTE_EIN_AUS: J11.56 R9.2 SW3.1
TASTE_KONFIG: J11.48 SW2.1
UART3_RXD: J11.34 U3.3
UART3_TXD: J11.54 U3.4
USB_N: J10.A7 J10.B7 J12.103 U10.3 U10.4
USB_P: J10.A6 J10.B6 J12.105 U10.1 U10.6
VBUS: F1.1 J10.A4 J10.A9 J10.B4 J10.B9
Versorgung/CC1: J10.A5 R10.1
Versorgung/CC2: J10.B5 R11.1
µSD/SD_VDD: C43.1 J13.4 U11.1

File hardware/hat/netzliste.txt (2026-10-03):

# Netz: Pins (SOLL aus erzeuge_schaltplan.py)
+3.3VA: C14.1 C15.1 C16.1 C20.1 U2.14 U2.8 U4.5
+3V3: C1.1 C12.1 C13.1 C30.1 J1.1 J1.17 R1.1 R2.1 R3.1 U1.8 U2.1 U2.27 U3.1
+3V3_ISO: C33.1 C34.1 C39.1 U3.12 U3.20 U5.16
+5V: C19.1 C31.1 C32.1 J1.2 J1.4 U3.9 U4.1 U4.3
GND: C1.2 C10.2 C11.2 C12.2 C13.2 C14.2 C15.2 C16.2 C17.2 C18.2 C19.2 C20.2 C30.2 C31.2 C32.2 D1.1 D2.1 J1.14 J1.20 J1.25 J1.30 J1.34 J1.39 J1.6 J1.9 JP1.2 SW1.2 T1.3 T2.2 U1.1 U1.2 U1.3 U1.4 U2.11 U2.15 U2.21 U2.22 U2.28 U3.10 U3.2 U3.5 U3.6 U3.8 U4.2
GNDA: J2.3 R5.2 T1.2 T2.3
GND_ISO: C33.2 C34.2 C37.2 C38.2 C39.2 J3.5 J3.SH U3.11 U3.13 U3.15 U3.16 U3.19 U5.10 U5.15
HAT/C1N: C35.2 U5.3
HAT/C1P: C35.1 U5.1
HAT/C2N: C36.2 U5.5
HAT/C2P: C36.1 U5.4
HAT/EEPROM_WP: JP1.1 R3.2 U1.7
HAT/HP_L: C23.1 U2.9
HAT/I2C_SCL: J1.5 U2.24
HAT/I2C_SDA: J1.3 U2.23
HAT/I2S_BCLK: J1.12 U2.3
HAT/I2S_DIN: J1.38 U2.6
HAT/I2S_DOUT: J1.40 U2.4
HAT/I2S_LRCLK: J1.35 U2.5 U2.7
HAT/ID_SC: J1.28 R2.2 U1.6
HAT/ID_SD: J1.27 R1.2 U1.5
HAT/ISO_RXD: U3.18 U5.12
HAT/ISO_TXD: U3.17 U5.11
HAT/ISO_VN: C38.1 U5.6
HAT/ISO_VP: C37.1 U5.2
HAT/LED1_A: D1.2 R6.2
HAT/LED2_A: D2.2 R7.2
HAT/LED_GESPRAECH: J1.18 R7.1
HAT/LED_TELEFON: J1.16 R6.1
HAT/LINE_IN: C22.2 U2.20
HAT/RS232_RXD: J3.2 U5.13
HAT/RS232_TXD: J3.3 U5.14
HAT/T1_PRI: C21.2 T1.1
HAT/T1_SEK: C22.1 T1.4
HAT/T2_PRI: C23.2 T2.1
HAT/T2_SEK: R4.1 T2.4
HAT/TASTE: J1.22 SW1.1
HAT/UART3_RXD: J1.29 U3.3
HAT/UART3_TXD: J1.7 U3.4
HAT/VMID: C17.1 C18.1 U2.16
HAT/XTI: C10.1 U2.25 Y1.1
HAT/XTO: C11.1 U2.26 Y1.2
HAT/X_IN: C24.2 J2.2
HAT/X_IN_TEILER: C24.1 R4.2 R5.1
HAT/X_OUT: C21.1 J2.1

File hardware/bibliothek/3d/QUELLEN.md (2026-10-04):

# 3D-Modelle (nicht im Repo)

Herstellermodelle dürfen meist nicht weitergegeben werden. Sie liegen nur lokal in diesem Ordner; `richte_3d_aus.py`
schreibt daraus die ausgerichteten Modelle nach `ausgerichtet/`, auf die die Footprints verweisen.

| Datei | Bauteil | Quelle | SHA-256 (Stand 2026-10-04) |
|---|---|---|---|
| `7499010211A.stp` | Würth RJ45 mit Übertrager (J14) | Würth Elektronik / SnapEDA | `2a6b6ec668fbc4a9c21a563d8db33cb856da3924e848cb36465a19cd7ed7a514` |
| `615006138421.stp` | Würth RJ12 6P6C (J2) | Würth Elektronik / SnapEDA | `efb0b04f23887a7a559d470d5be7c99286ea27d10c0ea032a4bb6ecd59463bb4` |
| `615004143821.stp` | Würth RJ10 4P4C (J3) | Würth Elektronik / SnapEDA | noch nicht vorhanden |
| `DF40C-100DS.stp` | Hirose DF40C-100DS-0.4V(51) (J11, J12) | Hirose | `dba37971e28389011f22bbda0a6b57ba5f8678b0b643a95ed294114efd44ff06` |
| `ECS-2520MV-120-BN-TR.step` | ECS Oszillator 12 MHz (U6) | ECS | `a44a5ab4269b68825e93a2435582f8c686c255dffdc670d1b2f04502b08554f2` |
| `SM-LP-5001.STEP` | Bourns Übertrager (T1, T2) | Bourns | `332b73098eab5d670e74056b19e481cb792afa2106a96331f6526169f70b6313` |
| `CM4-step.zip` | Raspberry Pi CM4 (M1) | https://datasheets.raspberrypi.com/cm4/CM4-step.zip (lädt das Skript selbst) | `667649c0728b260ea7ce6b595eb0458f53bd5eef5a3249d3a8b5415de81e23a5` |

Fehlt eine Datei, zeigt KiCad das Bauteil ohne Körper; elektrisch ändert sich nichts.

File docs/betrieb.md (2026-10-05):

# Betrieb auf dem Gateway-Pi

Stand 2026-10-01. Alle Dienste laufen auf `sopho-gw` (Raspberry Pi 4, Debian 13 Trixie).

```
D340 ─seriell─ sopho2sipd ─ctrl_tcp 127.0.0.1:4444─ baresip ─SIP 127.0.0.1:5070⇄5060─ Asterisk ─SIP 5060─ Softphones (tel1, tel2)
                   └─ Webportal :8080 (Anrufliste, Rückruf, Wähltastatur)
```

| Dienst | Unit | Konfiguration | Zweck |
|---|---|---|---|
| `sopho2sipd` | `gateway/betrieb/sopho2sipd.service` | Aufrufoptionen in der Unit | Telefon, Zustandsautomat, Anrufdatensätze, Portal, SIP-Brücke, Rückwärtssuche |
| `baresip` 4.12 | `gateway/betrieb/baresip.service` | `gateway/baresip/config` → `~/.baresip/` | SIP-Seite, Audio über UCA222 (`plughw:CODEC,0`), nur lokal |
| `asterisk` | Unit aus dem Quellbaum + Drop-in | `gateway/asterisk/*.conf` → `/etc/asterisk/` | Registrar für Softphones, Wählplan |
| `nftables` | Debian | `gateway/betrieb/sopho2sip.nft` | Firewall |

## Einrichten (vom Laptop, Reihenfolge)
```
ssh sopho-gw 'bash -s' < tools/pi_bootstrap.sh
ssh sopho-gw 'git clone https://github.com/schnebeck/Sopho2SIP.git'
tools/firewall.sh                                           # mit Rücknahme nach 120 s, falls SSH abreißt
scp tools/asterisk_build.sh sopho-gw:/tmp/ && ssh sopho-gw 'bash /tmp/asterisk_build.sh'   # ~15 min
scp tools/baresip_build.sh sopho-gw:/tmp/ && ssh sopho-gw 'bash /tmp/baresip_build.sh v4.12.0'   # ~5 min, /usr/local
ssh sopho-gw 'cd ~/Sopho2SIP && tools/asterisk_config.sh'   # Passwörter → ~/.config/sopho2sip/sip-zugaenge.txt
ssh sopho-gw 'cd ~/Sopho2SIP && sudo install -m 644 gateway/betrieb/sopho2sipd.service /etc/systemd/system/ \
  && sudo install -m 644 gateway/betrieb/sopho2sip.logrotate /etc/logrotate.d/sopho2sip \
  && sudo systemctl daemon-reload && sudo systemctl enable --now sopho2sipd'
ssh -t sopho-gw 'python3 ~/Sopho2SIP/gateway/portal.py passwort'
ssh sopho-gw 'python3 ~/Sopho2SIP/gateway/portal.py zertifikat && sudo systemctl restart sopho2sipd'
ssh sopho-gw 'cd ~/Sopho2SIP && tools/ein_aus_einrichten.sh'   # Ein/Aus-Taster, STATUS-LED (CM4-Träger), dann reboot
```

## Ein/Aus-Taster (CM4-Träger)
`tools/ein_aus_einrichten.sh` richtet ein (idempotent; auf dem Pi 4 ohne Träger nur Schritt 1):
1. logind (`gateway/betrieb/logind-ein-aus.conf` → `/etc/systemd/logind.conf.d/`): kurzer Druck wird ignoriert,
   **langer Druck (5 s) fährt sauber herunter** – Schutz gegen versehentliches Ausschalten.
2. `config.txt`: `dtoverlay=gpio-shutdown,gpio_pin=3` (Taster SW3 → Taste KEY_POWER) und
   `dtoverlay=gpio-led,gpio=22,label=status,trigger=none` (D3 als LED `status`).
3. Dienst `sopho2sip-herunterfahren` (`gateway/betrieb/`): STATUS leuchtet vom Beginn des Herunterfahrens bis zum
   Halt; der Dienst ist nach den Gateway-Diensten geordnet und wird darum als erster gestoppt.
4. Prüft den Bootloader: `WAKE_ON_GPIO=1` und `POWER_OFF_ON_HALT=0` nötig, sonst startet der Taster nicht.

Bedienung: im Betrieb Taster 5 s halten → STATUS an, Dienste enden (eine laufende D340-Verbindung legt spätestens
der 30-s-Watchdog der D340 auf), Halt. Im Halt kurz drücken → Neustart. Ohne Netzteil hilft der Taster nicht;
eingesteckt startet das CM4 sofort. Hängt das System, bleibt nur der Stecker. Noch nicht am Muster erprobt
(Wecken über GPIO3, ggf. R9 bestücken; Verhalten von D11 PWR im Halt).

## Aktualisieren
`ssh sopho-gw 'cd ~/Sopho2SIP && git pull && sudo systemctl restart sopho2sipd'`
(Asterisk-/baresip-Dateien geändert: zusätzlich `tools/asterisk_config.sh`.)

## baresip 4.x: Besonderheiten
- Debian/Trixie liefert nur 1.1.0 (2021); `tools/baresip_build.sh` baut `re` + `baresip` aus dem Quelltext nach `/usr/local`.
- `module_tmp` gibt es nicht mehr: `account.so` als `module_app` laden, sonst kein Konto.
- Loopback wird aus den lokalen Adressen gefiltert; `net_interface 127.0.0.1` erzwingt sie (sonst „SIP register failed:
  Protocol not supported“ bei `sip_listen 127.0.0.1:…`).
- Jitterbuffer heißt `audio_jitter_buffer_type`/`audio_jitter_buffer_ms`.
- Eingehende Anrufe nur an den Benutzer des Kontos (`sip:gateway@…`), andere bekommen 404.
- `ctrl_tcp`: Ereignisfelder wie in 1.1.0; der Befehl `sndcode` existiert nicht mehr (DTMF senden brauchen wir nicht).

## Sicherheit
- Firewall: eingehend nur SSH (Schlüssel) von überall; Portal 8080, SIP 5060, RTP 10000–20000, mDNS nur aus
  `130.75.63.128/25` und dem VPN `10.8.6.0/24`. Zusätzlich PJSIP-ACL mit denselben Netzen.
- Portal: `https://130.75.63.159:8080/` mit selbstsigniertem Zertifikat (`python3 gateway/portal.py zertifikat`,
  Ausnahme einmal im Browser bestätigen, SHA-256-Fingerabdruck vergleichen). HTTPS ist Voraussetzung für
  Browser-Benachrichtigungen. HTTP-Basic-Auth (PBKDF2); ohne Passwortdatei nur auf 127.0.0.1
  (`ssh -L 8080:localhost:8080 sopho-gw`). POST-Aufträge brauchen den Kopf `X-Sopho2SIP: 1`.
- Anrufhinweis im Portal: Browser-Benachrichtigung (Klick holt den Tab nach vorn; selbst nach vorn holen darf
  sich ein Tab nicht), blinkender Tab-Titel, optional Klingelton. Einstellungen je Browser (localStorage).
- **Steuerung:** Ohne `--steuerung` sendet der Daemon nur Anmelden/Keepalive. Portal-Wahl, Rückruf und
  SIP-Anrufe zur Sopho werden abgewiesen; eingehende Anrufe lassen die Softphones nur klingeln (Anzeige).
  `--steuerung` erst nach dem Wähltest einschalten (`sudo systemctl edit sopho2sipd`).
- SIP-Zugänge `tel1`/`tel2`: Zufallspasswörter, nur auf dem Pi. Die externe Wahl über `01` macht die Konten
  zum Ziel für Gebührenbetrug; Passwörter nicht weitergeben.

## Rufweg und Nummern
- Sopho → SIP: baresip ruft `sip:<Anrufernummer>@127.0.0.1`; Asterisk (`von-sopho`) setzt daraus die Caller-ID
  (extern ohne Amtsholung, z. B. `0171…`; ohne Nummer `anonymous`) und ruft `tel1` und `tel2` 60 s lang.
  Nimmt ein Softphone ab, sendet der Daemon „Annehmen“ an die D340 und schaltet X-Eingang ein.
  **Vorrang der D340:** Hebt jemand vorher am Hörer ab, beendet die Brücke nur den SIP-Ruf (Softphones verstummen) und
  lässt das Gespräch an der D340 unberührt. Grenzfall: Hörer abheben *während* eines SIP-Gesprächs übernimmt es nicht
  (X-Eingang bleibt an, das Hörermikrofon ist dann stumm).
- SIP → Sopho: Asterisk (`von-intern`) ruft baresip mit der gewählten Nummer als Absender; der Daemon wählt sie
  an der D340 (`0…` bekommt die Amtsholung `01`, `010…` gilt als schon mit Amtsholung, `+` → `00`,
  ohne führende 0 = Nebenstelle). Meldet sich die Gegenseite, nimmt baresip an.
- DTMF vom Softphone (RFC 4733) → Ziffer als Nachwahl (Rahmen `19`, Treiber `TSPI_lineDial`). Ob die Gegenseite
  dabei Töne hört: **vermutet**, beim ersten Wähltest prüfen.
- Sprache: nur mit „TAPI: Sprache über Zusatzgerät“ am Telefon und angeschlossener UCA222 (`docs/audio_verkabelung.html`).

## Rückwärtssuche
Mit `--rueckwaertssuche` (in der Unit gesetzt) schlägt der Daemon beim Klingeln bzw. bei eigener Wahl den Namen
externer Nummern nach (`gateway/rueckwaerts.py`): zuerst 11880.com (JSON-LD, Telefonnummer muss passen), dann
Das Örtliche (nur bei Weiterleitung auf einen Eintrag). Name/Ort erscheinen im Portal und im Anrufdatensatz.
**Datenschutz:** Jede externe Anrufernummer geht an diese Dienste. Zwischenspeicher
`~/.local/share/sopho2sip/rueckwaerts.json` (Treffer 30 Tage, ohne Treffer 7 Tage). Nebenstellen werden nie gesucht.
Mobilnummern stehen selten in Verzeichnissen. Abschalten: Option aus der Unit entfernen.

## Erste SIP-Gespräche (2026-10-02/03)
- Handy → Nebenstelle → Softphone `tel1` (Laptop, baresip 1.0.0 über VPN) angenommen: Brücke nimmt an der D340 an,
  schaltet X-Eingang ein, Gespräch 118 s ohne Abbruch, Auflegen vom Softphone löst an der D340 aus.
- Messung mit automatisch annehmendem Testprofil (spielt eine Sprachnachricht, Asterisk-Mitschnitt `MITSCHNITT=1`):
  RTP in beiden Richtungen 0 Pakete verloren, Jitter ≤ 3,5 ms; Aufnahme „vom Pi“ (Anrufer) 54 s ohne Aussetzer;
  Nachricht kam beim Anrufer gut an. Zerhackter Ton im ersten Versuch: Laptop-Seite (Bluetooth-Headset an zwei
  Geräten, ALSA→PipeWire in baresip 1.0.0), nicht die Strecke über den Pi.
- Die Sprache vom Pi hatte einen Gleichanteil von etwa −49 dBFS (Nullpunktfehler des UCA222-Wandlers, nicht der
  Leitung – Übertrager und C1 sperren Gleichspannung). Entfernt vom eigenen baresip-Modul `dcsperre`
  (`gateway/baresip/dcsperre/`, DC-Blocker 10 Hz; Test: 0,02 → 0,000034).
- Betriebsart: Standard ist „nur Anrufliste/Portal“ (Drop-in `/etc/systemd/system/sopho2sipd.service.d/steuerung.conf`);
  für SIP-Betrieb dort `--baresip 127.0.0.1:4444 --steuerung` ergänzen (Freigabe Nutzer).

## Beobachten
```
ssh sopho-gw journalctl -u sopho2sipd -f            # Telefon, Brücke, Aufträge
ssh sopho-gw journalctl -u baresip -f
ssh sopho-gw sudo asterisk -rvvv                     # Asterisk-Konsole
ssh sopho-gw tail ~/.local/share/sopho2sip/anrufe.jsonl
```
Rohprotokolle `~/Sopho2SIP/logs/ergo_*.log` rotieren täglich (14 Stück, höchstens 30 Tage); Anrufdatensätze nicht.

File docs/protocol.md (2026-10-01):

# Protokoll der PC-Schnittstelle (ErgoLine D340, 9-polige Buchse)

Stand 2026-09-30. Nur der aktuelle Wissensstand. Irrwege: [`sackgassen.md`](sackgassen.md),
Mitschnitte: [`../logs/INDEX.md`](../logs/INDEX.md). Treiberadressen beziehen sich auf `ref/ergoline_tsp/Ergoline.tsp`
(Imagebase 0x10000000).

Kennzeichnung: **bestätigt** = am Gerät gemessen/mitgeschnitten, **Treiber** = aus `Ergoline.tsp` abgeleitet,
am Gerät noch nicht geprüft, **vermutet** = Deutung.

## 1. Voraussetzungen am Telefon
| Punkt | Wert | Status |
|---|---|---|
| Gerät | ERGOLINE 340-2/LG INT, Terminal-Software **V4.03.40.01** | bestätigt |
| Freischaltung | Merkmale → Optionen: **„TAPI: Sprache über Telefon“ = Ein** (seit 2026-09-30 16:28). Solange beide TAPI-Schalter aus sind, reagiert die Schnittstelle auf nichts. | bestätigt |
| Sprachweg | „TAPI: Sprache über Zusatzgerät“ legt die Sprache auf die Audio-Buchse (für das Gateway nötig, noch nicht getestet) | vermutet (Handbuch) |

## 2. Physikalische Ebene
| Punkt | Wert | Status |
|---|---|---|
| Stecker | DB9-Buchse, Telefon = DCE, 1:1-Kabel, Pin 2 (Telefon sendet), 3 (Telefon empfängt), 5 (GND) | bestätigt |
| Pegel | Ruhepegel −5 V auf beiden Datenleitungen | bestätigt |
| Rate | **1200 Baud** | bestätigt (Testcode 63, `bitbang_20260930_163321`) |
| Format | **8O1 (ungerade Parität)**; der Treiber schaltet zusätzlich Xon/Xoff ein (Port-Methode 0x100132c2) | bestätigt: Senden/Empfangen mit 8O1 ohne Xon/Xoff (2026-10-01) |
| Servicemodus | 9600 8N1 bzw. 8O1 („ASFD-Modus“, nur für Escape/Versionsabfrage, Abschnitt 7) | Treiber |

## 3. Rahmenformat (beide Richtungen)
`<Klasse> <Länge> <Länge Byte Nutzdaten>` — **bestätigt** (Mitschnitte) und **Treiber** (Rahmen-Assembler 0x1000dbe9:
Ringpuffer 1 KB, Länge als vorzeichenbehaftetes Byte, max. 127; keine Prüfsumme, kein Escaping, kein XOR).

| Klasse | Richtung | Bedeutung (Treibername) |
|---|---|---|
| `01` | PC → Telefon | Auftrag (Treiber) |
| `02` | Telefon → PC | Meldung, `L2_REQ_PHONE` |
| `03` | Telefon → PC | Ablehnung, `L2_REJ_PHONE` |
| `04` | Telefon → PC | Quittung, `L2_ACK_PHONE` |
| `05` | Telefon → PC | Fehler, `L2_ERR_PHONE` (unser `05 00` nach unverstandener Eingabe, ~1,5 s) |

Nutzdaten: Byte 2 = Typ, Byte 3 = `01` (Meldung) bzw. `00` (Auftrag), danach typabhängig.
Quittung: Nur Aufträge des PCs werden quittiert (`04`). Meldungen des Telefons quittiert der PC nicht (Treiber:
keine Sendestelle in Empfang/Parser).

## 4. Beobachtete Meldungen (Log `serial_20260930_163534.log`, 1200 passiv)
| Zeit | Aktion des Nutzers | Nutzdaten (hex) | Bedeutung |
|---|---|---|---|
| 16:35:47.2 | Anruf kommt an | `30 01 98 6c 0d` + `0101700000000` | RINGING, Anrufer (IE `6c`) = Amtsholung `01` + Nummer |
| 16:35:53.1 | Hörer abgenommen | `3b 01 0a` · `31 01` · `3b 01 30` | OFF HOOK · CONNECTED · DTMF ein |
| 16:36:15.3 | aufgelegt | `3a 01 30` · `32 01 98 08 00` · `39 01 98 08 00` · `3a 01 0a` | DTMF aus · DISCONNECTED · RELEASED · ON HOOK |
| 16:37:26.7 | Hörer daneben, ohne Wahl | `36 01` · `3b 01 0a` | DIALTONE · OFF HOOK |
| 16:37:36.9 | (10,2 s später) | `36 01` | DIALTONE (Wiederholung, Grund offen) |
| 16:37:42.5 | aufgelegt | `39 01 98 08 00` · `3a 01 0a` | RELEASED · ON HOOK |
| 16:38:37.8 | abgehoben, Nummer getippt (Meldung erst bei Wahlende) | `36 01` · `3b 01 0a` | DIALTONE · OFF HOOK |
| 16:38:38.1 | | `19 01 98 70 0d` + `0101700000000` | MORE_INFO, gewählte Nummer (IE `70`) inkl. Amtsholung |
| 16:38:43.9 | | `3e 01` | PROCEEDING |
| 16:38:49.5 | Gegenseite nimmt an | `31 01` · `3b 01 30` | CONNECTED · DTMF ein |
| 16:39:11.5 | Gegenseite legt auf | `32 01 98 08 01 8f` · `3a 01 30` | DISCONNECTED, Ursache 0x8f · DTMF aus |
| 16:39:19.9 | Hörer aufgelegt | `39 01 98 08 00` · `3a 01 0a` | RELEASED · ON HOOK |

Verpasster Anruf (bestätigt, `test_20261001_130201_pi_angenommen_verpasst.log`, Daemon auf dem Pi):

| Zeit | Aktion des Nutzers | Nutzdaten (hex) | Bedeutung |
|---|---|---|---|
| 13:02:33.8 | Anruf kommt an | `30 01 98 6c 0d` + `0101700000000` | RINGING |
| 13:02:45.0 | Anrufer legt auf, niemand hat abgenommen | `39 01 98 08 01 8f` | RELEASED, Ursache 0x8f; **kein** DISCONNECTED, keine Hörermeldung |

Im Ruhezustand sendet das Telefon nichts. Abheben/Einzelziffern kamen erst bei Wahlende (Blockwahl).

## 5. Meldungstypen (Treiber, Parser 0x100172b9)
| Typ | Name | | Typ | Name |
|---|---|---|---|---|
| `19` | `L3_MORE_INFO` (Nummer, UUI) | | `38` | `L3_STATUSCAMPONBUSY` |
| `30` | `L3_STATUSRINGING` | | `39` | `L3_STATUSRELEASED` |
| `31` | `L3_STATUSCONNECTED` | | `3a` | `L3_STATUSFACILITYDEACTIVATED` |
| `32` | `L3_STATUSDISCONNECTED` | | `3b` | `L3_STATUSFACILITYACTIVATED` |
| `33` | `L3_STATUSIDLE` | | `3c` | `L3_STATUSFACILITYREJECTED` |
| `34` | `L3_STATUSHOLD` | | `3d` | `L3_STATUSERROR` |
| `35` | `L3_STATUSUNHOLD` | | `3e` | `L3_STATUSPROCEEDING` |
| `36` | `L3_STATUSDIALTONE` | | `3f`/`40` | `L3_STATUSCALLWAITINGACT`/`…DEACT` |
| `37` | `L3_STATUSBUSY` | | `41` | `L3_STATUSUSERTOUSER` |
| | | | `44` | `L3_STATUSNOHOLD` |

Merkmalskennung (Byte 4) bei `3b`/`3a`: `0a` OFF/ON HOOK, `30` DTMF-Töne ein/aus, `01` Umleitung, `16` wartenden
Anruf anzeigen, `17` wartenden Anruf annehmen, `1a` Rückruf (ARB), `1d` Aufschalten, `1f` Konferenz vorbereiten,
weitere über 0x30 (DND, Pickup, Reconnect).
Informationselemente wie Q.931: `6c` Anrufer, `70` Ziel, `08` Ursache (`08 00` = keine), `7e` User-to-User.
Rufnummern vom Telefon: reine ASCII-Ziffern; externe Nummern mit **Amtsholung `01`** davor (Angabe Nutzer,
passt zu beiden Mitschnitten). Im Wahlauftrag des PCs steht laut Treiber das Typ-Oktett `0x81` vor den Ziffern.
`98` (Byte 4 in Nummern-/Auslösemeldungen): Bedeutung offen.

## 6. Aufträge PC → Telefon (Treiber; Anmelden, Keepalive, Annehmen, Auflegen, Belegen, Wählen am Gerät bestätigt 2026-10-01)
Der Treiber wartet nach jedem Auftrag bis 5 s auf `04` (`AckEvent`); ohne Quittung gilt der Auftrag als gescheitert.
**Bestätigt:** Quittung ist immer `04 00`, nach 100–150 ms (Logs `test_20261001_*`). Nach „Anmelden“ folgt 50 ms später
die Meldung `02 04 01 01 02 00` (Typ `01`). Der Treiber wertet sie **nicht** aus: einziger Rahmenweg Empfang 0x10014219 →
Parser 0x100172b9 → `default` (0x1001934a, nur Trace) → CompareOldStateNewState `default` (0x10019d4e). Für einen Daemon ignorierbar. Deutung (vermutet, Nutzer 2026-10-01): **READY**, Bereitmeldung nach der Anmeldung. „Annehmen“ lässt das Telefon abheben (Freisprechen bei
„TAPI: Sprache über Telefon“), danach `3b…0a` + `31`. „Auflegen“ beendet das Gespräch: `32` (Ursache leer), `39`, `3a…0a`.
Im Freisprechbetrieb beendet auch die Lautsprecher-Taste am Telefon das Gespräch (Ursache leer).
**Bestätigt (`test_20261001_150042_waehlen_extern.log`, extern auf Handy):** „Belegen“ → ACK nach 100 ms, Telefon hebt
ab (`3b 01 0a`), meldet aber **keinen** Wählton `36`. „Wählen“ (3 s später) → ACK nach 360 ms, dann MORE_INFO `19` mit
der Zielnummer, `3e` nach 6 s, `31` + DTMF ein beim Abnehmen der Gegenseite. „Auflegen“ wie oben.
Sprache lief dabei (Schalter „TAPI: Sprache über Telefon“) über die Freisprecheinrichtung der D340 (Nutzer).
Für SIP muss der Sprechweg auf die Audio-Buchse: „TAPI: Sprache über Zusatzgerät“ (noch zu testen).
**Bestätigt 2026-10-01 (`test_20261001_171607_x_eingang_per_pc.log`):** Merkmal `4f` = „X-Eingang statt Mikrofon“.
Per Funktionstaste im Ruhezustand → `3c 01 4f` (abgelehnt); im Gespräch → `3b 01 4f`, nach Gesprächsende von selbst
`3a 01 4f`. Der PC schaltet es mit dem Merkmalsauftrag `01 03 26 00 4f` ein (ACK nach 100 ms, `3b 01 4f` nach 300 ms).
Der Treiber sendet `26` nur mit `16`, `1e`, `52`, `c3`, `ee` – `4f` ist aus der gemeinsamen Kennungsliste von
Meldung und Auftrag erschlossen und am Gerät bestätigt. Ohne `4f` ist X_IN kaum hörbar (`docs/hardware.md`).
**Vermutet:** `3a 01 4b`+`3b 01 4e` beim Wechsel in den Special mode (Passwort 2468), umgekehrt beim Zurückwechseln.
**Watchdog (bestätigt 2026-10-01; Idee Nutzer):** Vom PC geführte Gespräche endeten viermal genau
30,4–30,7 s nach dem **letzten Rahmen des PCs** mit `3a 01 30`, `32 … 08 00`, `39` (wie Auflegen am Telefon) – mit und
ohne X-Eingang, mit und ohne Wiedergabe (Logs `ergo_20261001_171035/171607/190634/190905`). Die Testwerkzeuge sendeten
im Gespräch keine Keepalives. Gegenprobe mit Keepalive alle 10 s: Gespräch hielt 60 s (`test_20261001_191319_watchdog_mit_keepalive.log`; ohne:
`test_20261001_190905_watchdog_ohne_keepalive.log`). Folgerung: Der PC muss spätestens alle 30 s etwas senden. Der Treiber sendet Keepalive
nach 15 s ohne *Empfang*; Daemon und Werkzeuge senden jetzt nach 15 s (Werkzeuge 10 s) ohne *Senden*.

| Auftrag | Rahmen | Treiberstelle |
|---|---|---|
| Keepalive | `01 02 00 00` | Thread 0x1001a1a7, nach 15 s ohne Empfang |
| Anmelden (Betriebsmodus) | `01 02 01 00` | Init 0x100147b0 |
| Leitung belegen (nur im Ruhezustand, vor der Wahl) | `01 02 11 00` | lineMakeCall → 0x10014b0c |
| **Wählen** | `01 <n+6> 19 00 98 70 <n+1> 81 <n ASCII-Ziffern>` | lineMakeCall 0x10014b0c, lineDial 0x10014eb9 |
| **Annehmen** (klingelnder Anruf) | `01 02 14 00` | lineAnswer → 0x10015d57 |
| **Auflegen** (ein Anruf) | `01 02 13 00` | lineDrop → 0x100168ce |
| Merkmalsauftrag | `01 03 26 00 <Kennung>`: `16`/`17` Anklopfen anzeigen/annehmen, `C3`/`EE` Reconnect (je nach Version), `52`, `1e` | Answer/Drop/Konferenz |
| weitere | `15`, `18`, `1b`, `1c`, `1d`, `21`–`24`, `27`, `25` (UUI) | Hold/Unhold/Transfer/Conference/CompleteCall |

Beispiel „Wählen 123“: `01 09 19 00 98 70 04 81 31 32 33`.
Im Treiber nicht unterstützt (`LINEERR_OPERATIONUNAVAIL`): Redirect, BlindTransfer, Accept.

## 6a. Zustandsautomat des Treibers (Treiber, statisch analysiert 2026-10-01)
Der Treiber führt für das Telefon eine **Anruftabelle** (Telefonobjekt `+0x14d4`, 31 Plätze; der Platzindex ist die
interne Anrufkennung) und je Anruf einen Zustand im **TAPI-Format `LINECALLSTATE_*`** samt Modus.
Die Rahmen tragen **keine Anrufkennung** (Byte „Leitung“ ist immer `01`): Der Treiber ordnet jede Meldung dem Anruf zu,
der sich gerade in einem passenden Zustand befindet (`SUCHE_ZUSTAND` 0x100075a3). Ein Daemon muss das genauso machen.

Ablauf je empfangenem Rahmen (Empfang 0x10014219): Ereignisobjekt anlegen → Parser 0x100172b9 setzt Ereigniscode(s)
→ Behandler 0x1000ab4f (legt bei Wählton-Codes `0f`–`14` bzw. Angebot `3c` einen neuen Anruf an) → Übergang
0x100069eb (alter Zustand × Code → neuer Zustand) → Modus 0x1000b70b → TAPI-Meldung `LINE_CALLSTATE` (0x1000a515).

**Ereigniscodes** (CompareOldStateNewState 0x10019bbb): `02` unbekannt · `0a` Freigabe · `0b`–`0e` besetzt
(Modus STATION/TRUNK/UNKNOWN/UNAVAIL) · `0f`–`14` Wählton (NORMAL/SPECIAL/INTERNAL/EXTERNAL/UNKNOWN/UNAVAIL) ·
`15`–`19` Sonderinfo · `1a`–`25` Auslösung (LINEDISCONNECTMODE NORMAL, UNKNOWN, REJECT, PICKUP, FORWARDED, BUSY,
NOANSWER, …) · `29` Wahl · `2a` Proceeding · `2b` Ringback · `2c` Halten · `2d` Halten für Übergabe ·
`2e` Halten für Konferenz · `2f` Accept · `30` Konferenz · `32` Verbunden · `3c` Angebot.
Bei RESP_PROCEEDING folgen `2a` und `2b` direkt nacheinander; bei RESP_CONNECT auf einen Anruf in OFFERING/ACCEPTED
erst `2f`, dann `32`.

**Übergänge** (0x100069eb; in jedem Zustand gilt zusätzlich: `02` → UNKNOWN, `1a`–`25` → DISCONNECTED):

| alter Zustand | Code → neuer Zustand |
|---|---|
| UNKNOWN (neu) | `3c`→OFFERING · `0f`–`14`→DIALTONE · `29`→DIALING · `2a`→PROCEEDING · `2b`→RINGBACK · `0b`–`0e`→BUSY · `2f`→ACCEPTED · `32`→CONNECTED · `2c`→ONHOLD · `2d`→ONHOLDPENDTRANSFER · `2e`→ONHOLDPENDCONF · `30`→CONFERENCED · `0a`→IDLE |
| OFFERING | `2f`→ACCEPTED |
| ACCEPTED | `32`→CONNECTED |
| DIALTONE | `29`→DIALING |
| DIALING | `2a`→PROCEEDING · `0b`–`0e`→BUSY |
| PROCEEDING | `2b`→RINGBACK · `0b`–`0e`→BUSY · `30`→CONFERENCED |
| RINGBACK, BUSY | `32`→CONNECTED · `30`→CONFERENCED (nur RINGBACK) · `2b`→RINGBACK (nur BUSY) |
| CONNECTED | `2c`→ONHOLD · `2d`→ONHOLDPENDTRANSFER · `2e`→ONHOLDPENDCONF · `30`→CONFERENCED |
| ONHOLD, CONFERENCED | `32`→CONNECTED |
| ONHOLDPENDTRANSFER | `32`→CONNECTED · `30`→CONFERENCED |
| ONHOLDPENDCONF | `30`→CONFERENCED |
| DISCONNECTED | `0a`→IDLE (Platz wird frei) |

**Meldung → Zustand** (über Treibernamen, passt zu den Mitschnitten): `30` RINGING → OFFERING (neuer Anruf) ·
`36` DIALTONE → DIALTONE (neuer Anruf) · `19` MORE_INFO → DIALING · `3e` PROCEEDING → PROCEEDING, RINGBACK ·
`31` CONNECTED → (ACCEPTED,) CONNECTED · `37` BUSY → BUSY · `34`/`35` HOLD/UNHOLD → ONHOLD/CONNECTED ·
`32` DISCONNECTED → DISCONNECTED, Modus aus IE `08` · `39` RELEASED → IDLE, Platz frei.

**Vorbedingungen der Aufträge** (Sendefunktionen, siehe Abschnitt 6):
- Wählen: abgelehnt, solange ein Anruf DISCONNECTED ist. Kein Anruf → erst `11` belegen (ACK), dann `19` wählen.
  Ein Anruf in ONHOLD oder ONHOLDPENDTRANSFER → `19` direkt (Rückfragewahl, ohne Belegen). Sonst abgelehnt.
- Annehmen: genau ein Anruf in OFFERING → `14`. Zwei Anrufe, einer OFFERING (anklopfend) → `26 16`, dann `26 17`.
- Auflegen: ein Anruf → `13`. Zwei Anrufe → je nach Zuständen `15` und/oder `26 c3`/`26 ee` (Reconnect zum gehaltenen).
- Jeder Auftrag: genau einer offen, bis 5 s auf `04`.

**Folgerung für den Daemon:** Anruftabelle mit eigenen Kennungen; Zustand je Anruf als LINECALLSTATE (oder gleichwertig);
Zuordnung jeder Meldung über den Zustand; Aufträge nur senden, wenn die Vorbedingung erfüllt ist; Modus/Ursache
mitführen (für SIP-Statuscodes und die Anrufstatistik).

## 7. Initialisierung durch den Treiber (lineOpen 0x10007afc)
1. Port öffnen (9600).
2. „XSSEscape“: `02 02 0A 00`, 500 ms Pause.
3. Port 9600 8N1 („ChangeToASFDModus(0)“).
4. `05 88 00 89`, 2 s auf ACK. Ohne ACK: 9600 8O1, Escape wiederholen, zurück auf 8N1, erneut versuchen.
5. QueryVersion: `05 B0 00 B0` → ACK („ATS-Mode“) → ASCII `RQV:0\r` → ACK → `RQQ:1\r` → Einzelbyte `02`.
   Antwort als Textzeile (`ExamineVersionMessage`, Vergleich mit „1.07“).
6. Port 1200 8O1 Xon/Xoff („TAPI modus“).
7. `01 02 01 00`, 5 s auf ACK.

Schritte 2–5 sind ein Service-/Versionsmodus bei 9600; für den Betrieb vermutlich verzichtbar (vermutet).

Empfangsmodi im Treiber (OnData 0x10014219, Flags relativ zum Telefonobjekt):
- **Textmodus („ATS“)**: Flag `+0x14a6`, gesetzt nur in QueryVersion nach dem ACK auf `05 B0 00 B0`.
  Zeilen bis CR/LF, ausgewertet als Versionsantwort. Befehle dort: `RQV:0\r`, `RQQ:1\r` (kein Hayes-AT).
- **Rahmenmodus**: Flag `+0x14a5`, gesetzt nur in Init 0x100147b0 (`01 02 01 00`). Hat Vorrang vor dem Textmodus.
- Beide Flags werden nur im Konstruktor und beim Schließen (0x10014a17) zurückgesetzt.
- Einen Befehl, der die Baudrate des Telefons setzt, gibt es nicht. Die Rate hängt am Modus: 9600 im
  Service-/Textmodus, 1200 im Rahmenmodus. Umschaltung Telefon → Service vermutlich durch das Escape `02 02 0A 00`,
  zurück vermutlich durch `RQQ:1\r` + `02` (vermutet, Wirkung am Gerät nicht belegt).
- Ein Hayes-AT-Protokoll (`AT$…`) kommt in `Ergoline.tsp` nicht vor.

## 8. Offene Fragen
1. ~~Nimmt das Telefon `01 02 01 00` bei 1200 8O1 direkt an?~~ Ja, ACK `04 00` (2026-10-01). Meldung Typ `01`: im Treiber ungenutzt; Bedeutung nur noch per Versuch (Anmelden bei abgehobenem Hörer/im Gespräch) zu klären.
2. Xon/Xoff: Die Auftragstypen `11` und `13` sind zugleich die Xon/Xoff-Zeichen. Wie verhält sich das in der Praxis?
3. Bedeutung von `98` und der Aufträge `15`, `18`, `1b`–`24`, `27`.
4. Kommen Ereignisse ohne jede vorherige Eingabe (Neustart-Test)?
5. Warum wiederholt sich `36` nach 10 s?

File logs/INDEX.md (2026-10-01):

# Verzeichnis der Mitschnitte

Nur Mitschnitte, die etwas belegen, das wir weiter brauchen. Alles andere wurde gelöscht (Ergebnisse stehen in
`docs/sackgassen.md`). Rufnummern sind durch `0101700000000` ersetzt; Originale liegen nur lokal in `privat/`.
Neue Sitzungslogs `logs/ergo_*.log` sind per `.gitignore` ausgeschlossen; veröffentlicht werden bereinigte Kopien `test_*.log`. Alle Mitschnitte bei eingeschaltetem „TAPI: Sprache über Telefon“.
Werkzeuge: `serial` = `tools/serial_probe.py`, `bitbang` = `tools/bitbang_scope.py` (`.bin` = Rohabtastwerte, Bit 1 = RXD).

| Datei | Werkzeug | gesendet | Nutzeraktion | Beleg für |
|---|---|---|---|---|
| `serial_20260930_163534.log` | serial 1200 passiv, 10 min | – | Anruf ein/Annahme/Auflegen, Abheben ohne Wahl, externe Wahl, Auflegen beider Seiten | alle Ereignisrahmen (`protocol.md` Abschn. 4) |
| `bitbang_20260930_163321.*` | bitbang 19,2 kHz | `ATI0` @9600 | – | 1200 Baud 8N1; Antwort `05 00` 1,52 s später |
| `bitbang_20260930_163416.*` | bitbang | `ATI0` @1200 | – | gleiche Antwort `05 00` auch bei 1200 |
| `bitbang_20260930_163457.*` | bitbang, 10 s ohne Befehl | – | – | kein periodischer Takt (nur Reaktion auf Schaltimpuls) |
| `bitbang_20260930_163507.*` | bitbang, 3 s Ruhe + Befehl | `ATI0` @9600 | – | `05 00` genau 1,51 s nach der Eingabe |
| `test_20261001_084855_anmelden.log` | ergo 1200 8O1 | `01 02 01 00` | – | ACK `04 00`, danach Meldung Typ `01` |
| `test_20261001_084917_keepalive.log` | ergo 1200 8O1 | `01 02 00 00` | – | ACK `04 00` |
| `test_20261001_084929_empfang_8O1.log` | ergo 1200 8O1 | Anmelden | Anruf, am Telefon angenommen und aufgelegt | Empfang mit 8O1 fehlerfrei |
| `test_20261001_085405_annehmen.log` | ergo annahmetest | Anmelden, Annehmen, Auflegen | Lautsprecher-Taste nach 8 s | Annehmen bestätigt; Gespräch durch Taste beendet |
| `test_20261001_085744_annehmen_auflegen.log` | ergo annahmetest | Anmelden, Annehmen, Auflegen (4 s) | keine | **Annehmen und Auflegen bestätigt** |
| `test_20261001_130201_pi_angenommen_verpasst.log` | Daemon `sopho2sipd.py` auf dem Pi | Anmelden, Keepalive | Anruf am Telefon angenommen; zweiter Anruf nicht angenommen | Betrieb am Pi; verpasster Anruf = RINGING → RELEASED `08 01 8f` |
| `test_20261001_150042_waehlen_extern.log` | ergo waehltest am Pi | Anmelden, Belegen, Wählen (extern), Auflegen | Handy angenommen | **Belegen und Wählen bestätigt**; kein DIALTONE nach Belegen |
| `test_20261001_171607_x_eingang_per_pc.log` | audio_test.sh (waehltest --nach-verbindung) | Belegen, Wählen, `01 03 26 00 4f`, Auflegen | Handy angenommen, keine Taste | **Merkmal 4f per PC** (`3b 01 4f`); Selbstauslösung nach 31 s (Watchdog) |
| `test_20261001_190905_watchdog_ohne_keepalive.log` | audio_test.sh (waehltest ohne Keepalive) | Belegen, Wählen | Handy angenommen | **Watchdog**: D340 legt 30,5 s nach dem letzten PC-Rahmen auf |
| `test_20261001_191319_watchdog_mit_keepalive.log` | audio_test.sh (waehltest, Keepalive 10 s) | Belegen, Wählen, 6 × Keepalive, Auflegen | Handy angenommen | Gegenprobe: Gespräch hält 60 s |

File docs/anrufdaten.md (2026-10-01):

# Anrufdatensätze (Schnittstelle zur Nextcloud-App)

Der Daemon `gateway/sopho2sipd.py` erzeugt für jeden beendeten Vorgang an der D340 einen Datensatz – als JSON-Zeile
in eine Datei (Standard `~/.local/share/sopho2sip/anrufe.jsonl`) und optional per **HTTP-POST** an `--webhook URL`
(`Content-Type: application/json`, ein Datensatz je Anfrage, Antwort wird nicht ausgewertet).

Stand: Ausbaustufe 1 (nur Telefonseite, noch ohne SIP). Felder können ergänzt, aber nicht umbenannt werden.

## Felder

| Feld | Typ | Bedeutung |
|---|---|---|
| `kennung` | int | laufende Nummer seit Start des Daemons |
| `ergebnis` | str | `angenommen`, `verpasst` (eingehend) · `verbunden`, `nicht_erreicht`, `ohne_wahl` (abgehend) |
| `richtung` | str | `ein` oder `aus` |
| `nummer` | str | Rufnummer ohne Amtsholung (`""` wenn keine) |
| `extern` | bool | `true`, wenn die Nummer mit der Amtsholung (`01`) kam/gewählt wurde |
| `nummer_roh` | str | Ziffern wie vom Telefon gemeldet, inkl. Amtsholung |
| `name` | str/null | Name aus der Rückwärtssuche (nur externe Nummern, nur mit `--rueckwaertssuche`) |
| `ort` | str/null | Ort aus der Rückwärtssuche |
| `beginn` | str | ISO 8601 mit Zeitzone: Klingelbeginn bzw. Wählton |
| `verbunden` | str/null | Zeitpunkt der Verbindung |
| `ende` | str | Zeitpunkt der Freigabe (RELEASED) |
| `angenommen` | bool | ob eine Verbindung zustande kam |
| `dauer_s` | float | Gesprächsdauer von Verbindung bis Trennung |
| `ursache` | str/null | Auslöseursache hex (`""` = keine, z. B. `"8f"`) |
| `ausloeser` | str/null | `eigene_seite` (Ursache leer) oder `gegenseite` (vermutet aus Beobachtung) |
| `verlauf` | list | Zustände nach TAPI (`OFFERING`, `CONNECTED`, …) |

## Beispiel (aus einem Mitschnitt, Nummer ersetzt)

```json
{"kennung": 3, "ergebnis": "verbunden", "richtung": "aus", "nummer": "01700000000", "extern": true,
 "nummer_roh": "0101700000000", "name": null, "ort": null, "beginn": "2026-09-30T16:38:37.791+02:00", "verbunden": "2026-09-30T16:38:49.832+02:00",
 "ende": "2026-09-30T16:39:20.128+02:00", "angenommen": true, "dauer_s": 21.9, "ursache": "8f",
 "ausloeser": "gegenseite", "verlauf": ["DIALTONE", "DIALING", "PROCEEDING", "RINGBACK", "CONNECTED", "DISCONNECTED", "IDLE"]}
```

## Ohne Telefon ausprobieren

```
gateway/sopho2sipd.py --wiedergabe logs/serial_20260930_163534.log --anrufe - --webhook http://localhost:8080/…
```

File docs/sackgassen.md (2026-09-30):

# Sackgassen

Kurzvermerke, damit nichts doppelt versucht wird. Belege wurden gelöscht, soweit sie nichts mehr beitragen.

## Falscher Treiber
- **`Octophon340.tsp` (+ `OctophonGer.hlp`/`OctophonEng.hlp`)**, TAPICall-Download „Octopus 180i/M/M26“:
  **falscher Treiber, inkompatibel** mit unserer D340. Er spricht ASCII/AT (`AT$CAL`, `CAL`, `CPN` …) mit 9600 Baud,
  Zeilenende CRLF, bricht an Nullbytes ab, keine Rahmen, kein ACK. Unsere D340 spricht binär mit 1200 Baud.
  Statisch analysiert und am 2026-09-30 aus `ref/` gelöscht. Vermutlich für Telekom-Firmware der Octophon 340i
  oder den V.24-Terminal-Adapter geschrieben.
- Richtiger Treiber: `ref/ergoline_tsp/Ergoline.tsp`.

## Widerlegte Annahmen
| Annahme | Stand |
|---|---|
| 9600 Baud 8N1 (aus dem falschen Treiber) | falsch: **1200** (Wartungscode 63, Messung), laut `Ergoline.tsp` **8O1** + Xon/Xoff |
| AT-Befehle (`ATI0`, `AT`, `ATI`, `ATI1`, `AT$STA1`), CR/CRLF, alle Raten 1200–38400 | nie verstanden; Antwort bestenfalls `05 00` |
| Stille bei allen Raten ⇒ Telefon sendet nicht | Fehlschluss: Schnittstelle war aus (TAPI-Schalter) |
| Adapter, Kabel, Pinbelegung, Stecker defekt | alles in Ordnung (Loopback, Pegelmessung) |
| DB9 dient der ASCII-Tastatur | nein, die ist Infrarot |
| PC-Schnittstelle braucht Netzteil | nein, nur V.24/DSS |
| Baudrate im Telefon einstellbar | nur für V.24-Option, nicht für die DB9 |
| `05 00` ist ein Herzschlag | nein, Antwort ~1,5 s nach jeder Eingabe |
| Hex-Strings `3B`/`0A`/`3E`/`0F` im falschen Treiber = Meldungstypen | nein, ASCII-Ursachencodes |
| `98` = Anrufkennung | nein, fester Wert |
| `36 01` = abgehoben | `L3_STATUSDIALTONE` (Treiber) |
| `3b`/`3a` = unbekanntes Ein/Aus-Paar | FACILITY ACTIVATED/DEACTIVATED, `0a` = Hörer, `30` = DTMF (Treiber) |
| Telefon erwartet Quittung für seine Meldungen | nein, nur PC-Aufträge (`01`) werden mit `04` quittiert (Treiber) |

**Eigentliche Ursache der Stille bis 2026-09-30 16:28:** Merkmale → Optionen, beide TAPI-Schalter aus.

## Werkzeug
- Umschalt-Abtaster (mit 9600 senden, dann auf hohe Rate umschalten) zu langsam → gelöscht; Ersatz `tools/bitbang_scope.py`.
- Bitbang braucht Vorausschreiben (2 Blöcke à 64), sonst Lücken; pyftdi-Parameter heißt `baudrate`, nicht `frequency`.
- `pkill -f <muster>` trifft auch die eigene Shell → PID gezielt per `pgrep` bestimmen.

## Quellen
- Scribd blockiert automatischen Abruf → Handbücher über ManualsLib.
- Aktuelle TAPICall-Seiten für ErgoLine D330/Octophon 340i ohne Download; archivierter Download `…/download/treiber/481100869/`
  war ein falsches (FRITZ!Box-)Paket. Gefunden hat es erst der Wayback-Index (`ergoline.zip`, 2010).

## Infrastruktur
- rpi-imager 1.8.5 kann kein cloud-init → Image per `dd`, cloud-init-Dateien selbst auf bootfs.

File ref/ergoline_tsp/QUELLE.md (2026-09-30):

# Herkunft (gesichert 2026-09-30, nicht verändern)

| Datei | Quelle (Wayback Machine) | SHA-256 |
|---|---|---|
| `ergoline.zip` | https://web.archive.org/web/20101201193039id_/http://tapicall.de/tapi-treiber/nec_philips/telefone/ergoline-serie/ergoline_d330/ergoline.zip | siehe unten |
| `Ergoline.tsp` (aus dem ZIP, 29.07.2002) | dto. | siehe unten |
| `ErgoLineTSP_relnotes.doc` (aus dem ZIP) | dto. | siehe unten |
| `guide_ergoline_d325_d330_english.pdf` (User Guide D325/D330) | https://web.archive.org/web/20130903072524id_/http://tapicall.de:80/einrichten/tapi-treiber/tc_tapidriver/manual/guide_ergoline_d325_d330_english.pdf | siehe unten |

Philips ErgoLine D330/D340 TSP for TAPI 2.x, Version 2.1.2 (Philips Communication Systems B.V., 2002).
Früher von TAPICall für ErgoLine D330 und Octophon 340i verlinkt (`treiber/ergoline.tsp`), heute dort nicht mehr verfügbar.

```
d278ae82b84d656354e80f650fbd9ae9816d62526e92ea5dcb5483e05b374daf  ergoline.zip
2b5b2b3e2e3ff51a2ca666b7bc874e9e9d81551a3f67c5357ea8ea297f50b282  Ergoline.tsp
67b9be938474b64eef8c63e565f6fbb979fba9975483173244be4828eb2d0009  ErgoLineTSP_relnotes.doc
43c5700ffad4e2452b1e79c589faf2d822d2e2d73502832901a0f4df0af3011f  guide_ergoline_d325_d330_english.pdf
```

## Nicht im öffentlichen Repository
Die oben genannten Dateien (Treiber, Versionshinweise, ZIP, Benutzerhandbuch) sind urheberrechtlich geschützt
(Philips Communication Systems) und werden **nicht** mitveröffentlicht. Wer den Treiber prüfen oder nachanalysieren
will, lädt ihn über die Wayback-URL oben selbst und vergleicht die SHA-256-Summe.
Direkt-Download (Rohdatei ohne Wayback-Rahmen): https://web.archive.org/web/20101201193039id_/http://tapicall.de/tapi-treiber/nec_philips/telefone/ergoline-serie/ergoline_d330/ergoline.zip

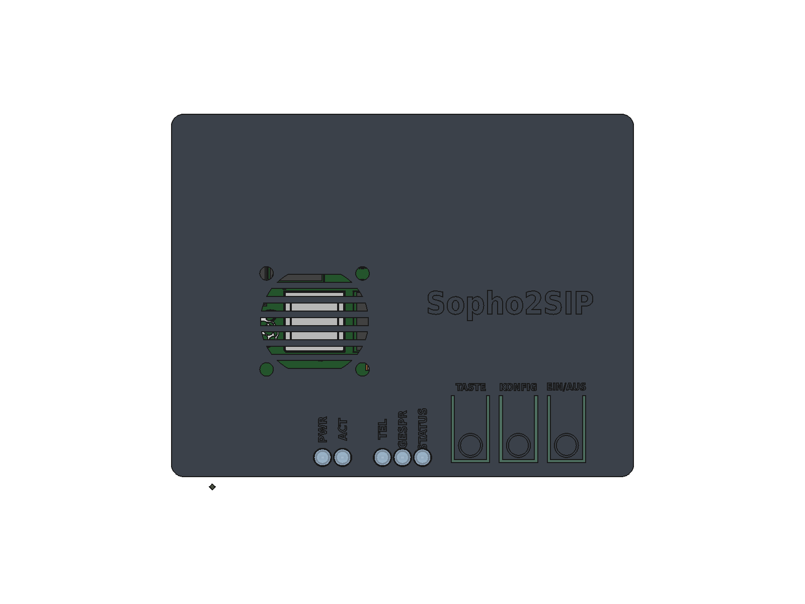
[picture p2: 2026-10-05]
hardware/gehaeuse/ansichten/gehaeuse_oben.png

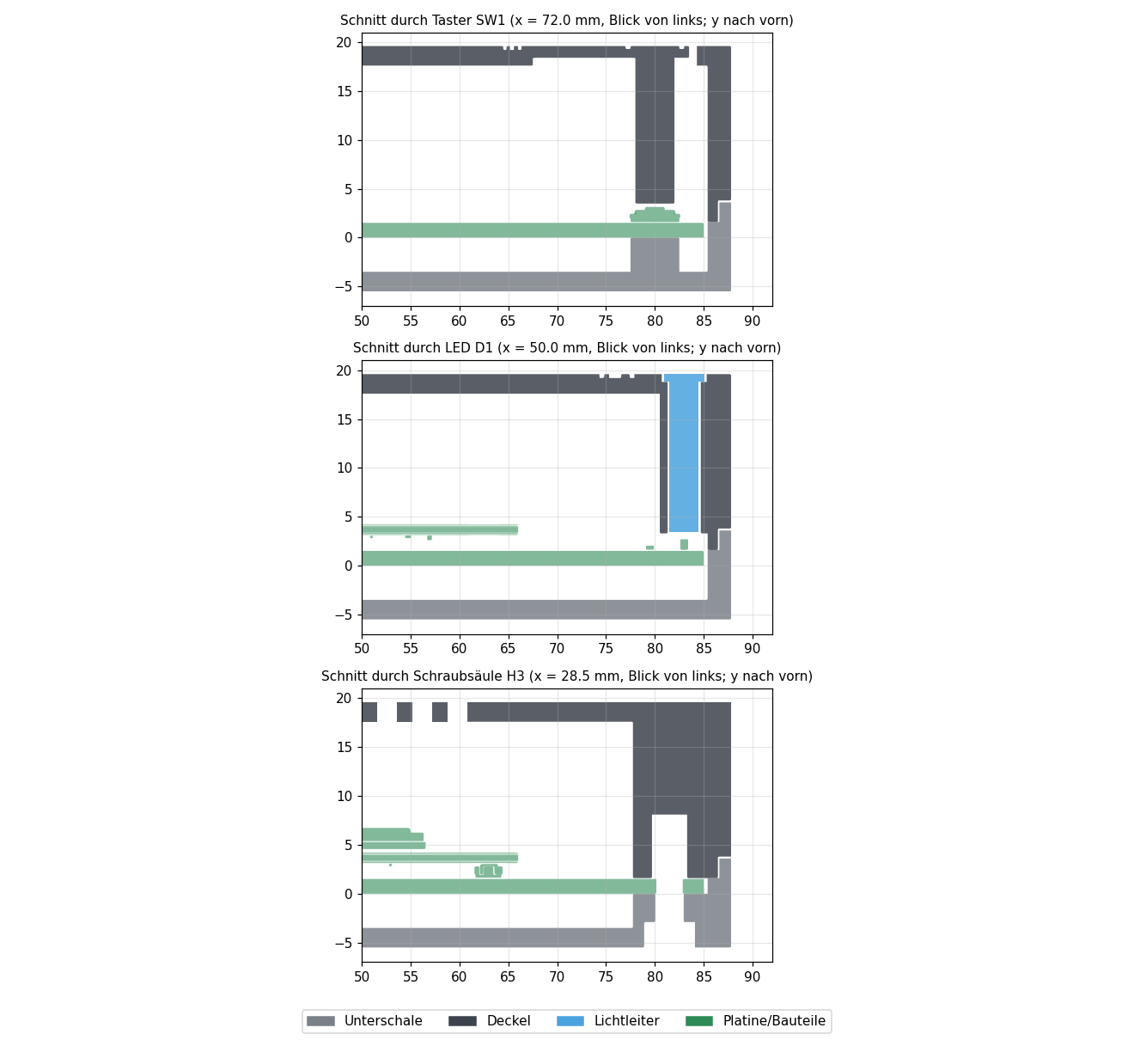
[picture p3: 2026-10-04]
hardware/gehaeuse/vorschau_schnitte.png

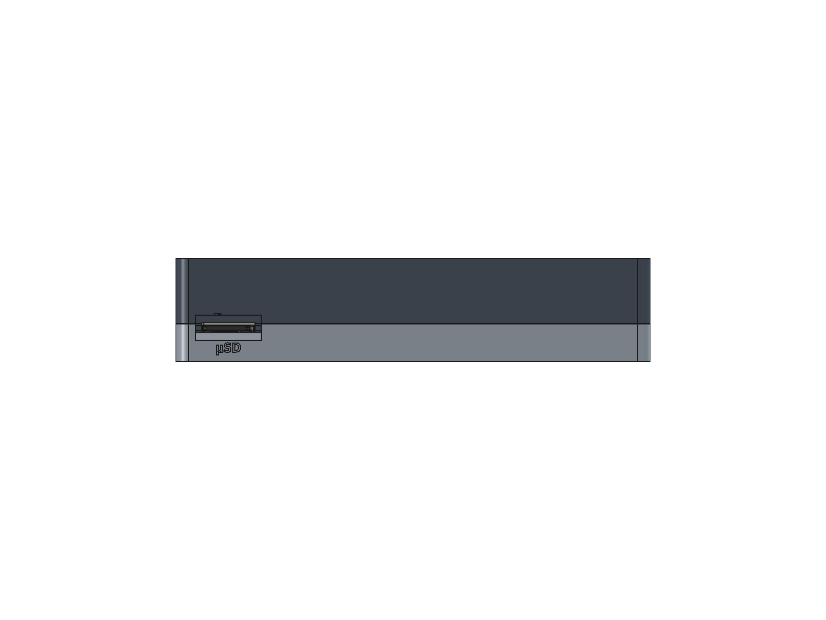
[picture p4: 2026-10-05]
hardware/gehaeuse/ansichten/gehaeuse_vorderseite.png

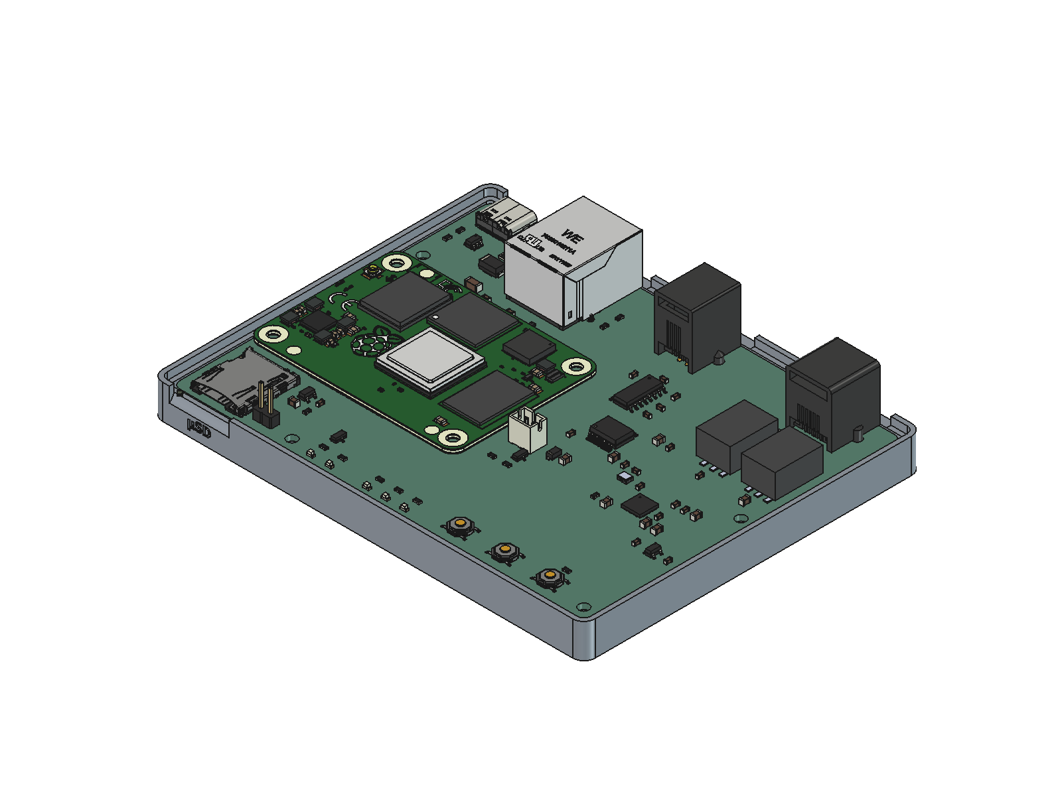
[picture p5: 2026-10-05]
hardware/gehaeuse/ansichten/unterschale_mit_platine.png

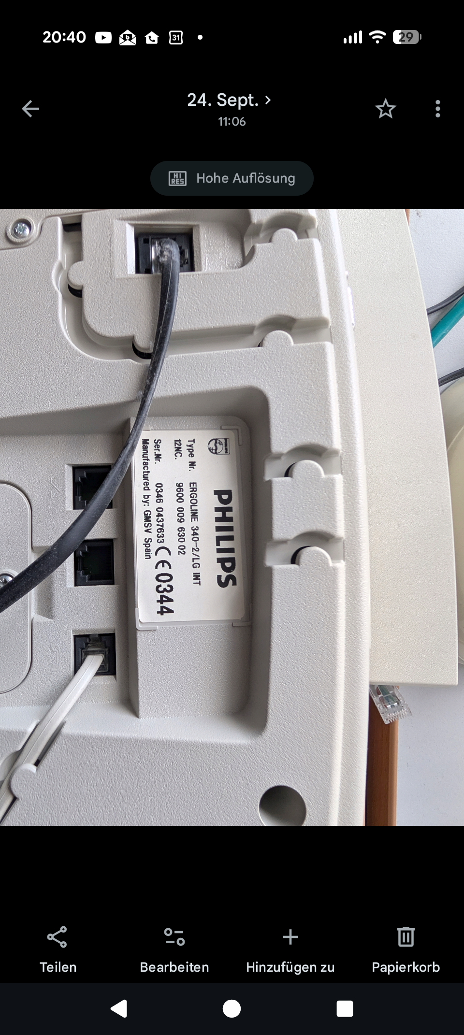
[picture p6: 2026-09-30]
ref/foto_typenschild.png

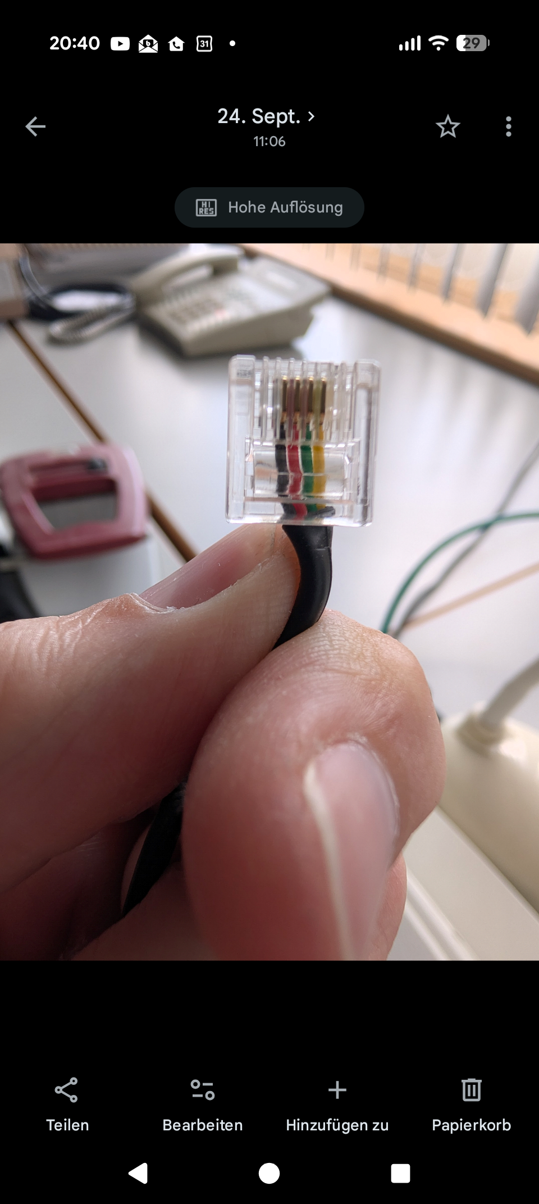
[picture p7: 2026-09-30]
ref/foto_leitungsstecker.png

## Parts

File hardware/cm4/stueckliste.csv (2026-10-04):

Referenz | Wert | Footprint | Anzahl | DNP
C12,C14,C26,C27,C30,C32,C34,C35,C36,C37,C38,C39,C41,C44,C45 | 100n | Capacitor_SMD:C_0603_1608Metric | 15
C15,C19,C20,C22 | 1u | Capacitor_SMD:C_0603_1608Metric | 4
C16,C17,C18,C23,C25,C31,C33,C43,C46 | 10u | Capacitor_SMD:C_0805_2012Metric | 9
C21,C24 | 1u | Capacitor_SMD:C_0805_2012Metric | 2
C40,C42 | 47u | Capacitor_SMD:C_1206_3216Metric | 2
D1 | grün | LED_SMD:LED_0603_1608Metric | 1
D2 | gelb | LED_SMD:LED_0603_1608Metric | 1
D3 | blau | LED_SMD:LED_0603_1608Metric | 1
D10 | grün ACT | LED_SMD:LED_0603_1608Metric | 1
D11 | rot PWR | LED_SMD:LED_0603_1608Metric | 1
D12 | SMAJ5.0CA | Diode_SMD:D_SMA | 1
D13 | MBR140SFT1G | Diode_SMD:D_SOD-123F | 1
F1 | 2A | Fuse:Fuse_1812_4532Metric | 1
J2 | D340 Audio | Sopho2SIP:RJ12_Wuerth_615006138421_Horizontal | 1
J3 | D340 PC (4P4C) | Sopho2SIP:RJ10_Wuerth_615004143821_Horizontal | 1
J10 | USB-C 5V/USB | Connector_USB:USB_C_Receptacle_GCT_USB4105-xx-A_16P_TopMnt_Horizontal | 1
J11 | CM4 Stecker 1 | Connector_Hirose_DF40:Hirose_DF40C-100DS-0.4V_2x50_P0.4mm | 1
J12 | CM4 Stecker 2 | Sopho2SIP:Hirose_DF40C-100DS-0.4V_2x50_P0.4mm_Pins101-200 | 1
J13 | microSD | Connector_Card:microSD_HC_Hirose_DM3AT-SF-PEJM5 | 1
J14 | 7499010211A | Connector_RJ:RJ45_Wuerth_7499010211A_Horizontal | 1
J15 | Lüfter 5 V | Connector_JST:JST_PH_B2B-PH-K_1x02_P2.00mm_Vertical | 1
JP10 | nRPIBOOT | Connector_PinHeader_2.54mm:PinHeader_1x02_P2.54mm_Vertical | 1
M1 | Raspberry Pi CM4 (z. B. CM4104032) | Sopho2SIP:CM4_Modul_Platzhalter | 1
Q10 | BSS84 | Package_TO_SOT_SMD:SOT-23 | 1
Q11 | AO3400A | Package_TO_SOT_SMD:SOT-23 | 1
R4 | 0R | Resistor_SMD:R_0603_1608Metric | 1
R5,R9 | DNP | Resistor_SMD:R_0603_1608Metric | 2 | Nicht bestücken
R6,R7,R8,R12,R13 | 330 | Resistor_SMD:R_0603_1608Metric | 5
R10,R11 | 5k1 | Resistor_SMD:R_0603_1608Metric | 2
R14 | 12k | Resistor_SMD:R_0603_1608Metric | 1
R15,R16 | 470 | Resistor_SMD:R_0603_1608Metric | 2
R17 | 100 | Resistor_SMD:R_0603_1608Metric | 1
R18 | 100k | Resistor_SMD:R_0603_1608Metric | 1
R20 | 10k | Resistor_SMD:R_0603_1608Metric | 1
SW1 | Taste | Button_Switch_SMD:SW_SPST_TL3342 | 1
SW2 | Konfig | Button_Switch_SMD:SW_SPST_TL3342 | 1
SW3 | Ein/Aus | Button_Switch_SMD:SW_SPST_TL3342 | 1
T1,T2 | SM-LP-5001 | Sopho2SIP:Bourns_SM-LP-5001 | 2
U2 | TLV320AIC3204IRHBR | Package_DFN_QFN:Texas_RHB0032E_VQFN-32-1EP_5x5mm_P0.5mm_EP3.45x3.45mm_ThermalVias | 1
U3 | ADuM5211 | Package_SO:SSOP-20_5.3x7.2mm_P0.65mm | 1
U4 | AP2112K-3.3 | Package_TO_SOT_SMD:SOT-23-5 | 1
U5 | MAX3232E | Package_SO:SOIC-16_3.9x9.9mm_P1.27mm | 1
U6 | 12MHz | Oscillator:Oscillator_SMD_ECS_2520MV-xxx-xx-4Pin_2.5x2.0mm | 1
U10 | USBLC6-2SC6 | Package_TO_SOT_SMD:SOT-23-6 | 1
U11 | AP22804AW5 | Package_TO_SOT_SMD:SOT-23-5 | 1
U12 | TPD4E05U06DQAR | Package_SON:USON-10_2.5x1.0mm_P0.5mm | 1

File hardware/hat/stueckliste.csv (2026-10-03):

Referenz | Wert | Footprint | Anzahl | DNP
C1,C12,C13,C14,C16,C18,C30,C32,C34,C35,C36,C37,C38,C39 | 100n | Capacitor_SMD:C_0603_1608Metric | 14
C10,C11 | 22p | Capacitor_SMD:C_0603_1608Metric | 2
C15,C17,C23,C31,C33 | 10u | Capacitor_SMD:C_0805_2012Metric | 5
C19,C20,C22 | 1u | Capacitor_SMD:C_0603_1608Metric | 3
C21,C24 | 1u | Capacitor_SMD:C_0805_2012Metric | 2
D1 | grün | LED_SMD:LED_0603_1608Metric | 1
D2 | gelb | LED_SMD:LED_0603_1608Metric | 1
H1,H2,H3,H4 | M2.5 | MountingHole:MountingHole_2.7mm_M2.5 | 4
J1 | Raspberry Pi GPIO | Connector_PinSocket_2.54mm:PinSocket_2x20_P2.54mm_Vertical | 1
J2 | D340 Audio | Connector_RJ:RJ12_Amphenol_54601-x06_Horizontal | 1
J3 | D340 PC-Schnittstelle | Connector_Dsub:DSUB-9_Pins_Horizontal_P2.77x2.84mm_EdgePinOffset7.70mm_Housed_MountingHolesOffset9.12mm | 1
JP1 | WP | Jumper:SolderJumper-2_P1.3mm_Open_RoundedPad1.0x1.5mm | 1
R1,R2 | 3k9 | Resistor_SMD:R_0603_1608Metric | 2
R3 | 10k | Resistor_SMD:R_0603_1608Metric | 1
R4 | 0R | Resistor_SMD:R_0603_1608Metric | 1
R5 | DNP | Resistor_SMD:R_0603_1608Metric | 1 | Nicht bestücken
R6,R7 | 330 | Resistor_SMD:R_0603_1608Metric | 2
SW1 | Taste | Button_Switch_SMD:SW_SPST_TL3342 | 1
T1,T2 | 600:600 |  | 2
U1 | 24LC32 | Package_SO:SOIC-8_3.9x4.9mm_P1.27mm | 1
U2 | WM8731SEDS | Package_SO:SSOP-28_5.3x10.2mm_P0.65mm | 1
U3 | ADuM5211 | Package_SO:SSOP-20_5.3x7.2mm_P0.65mm | 1
U4 | AP2112K-3.3 | Package_TO_SOT_SMD:SOT-23-5 | 1
U5 | MAX3232E | Package_SO:SOIC-16_3.9x9.9mm_P1.27mm | 1
Y1 | 12.288MHz | Crystal:Crystal_SMD_HC49-SD | 1

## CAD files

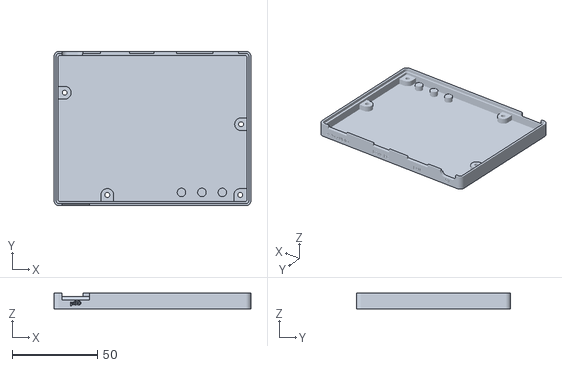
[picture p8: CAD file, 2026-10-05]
hardware/gehaeuse/druck/unterschale.stl
115.6 x 90.6 x 9.10

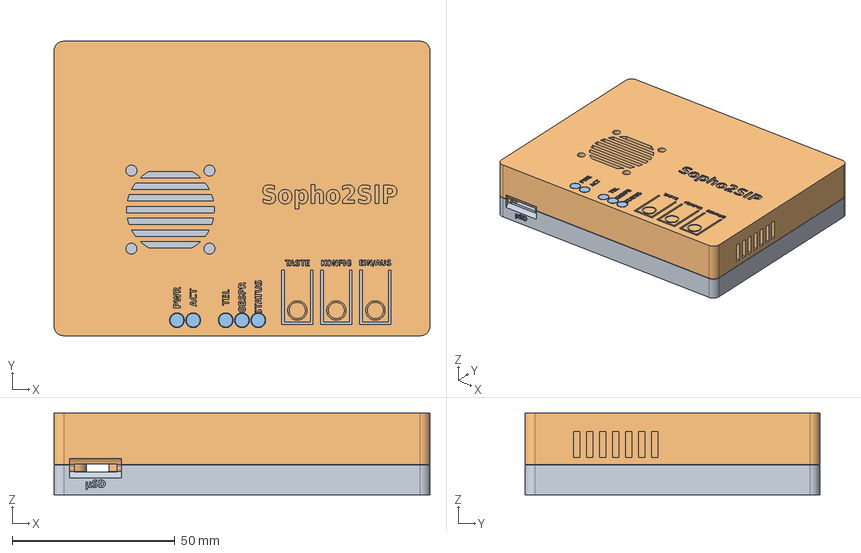
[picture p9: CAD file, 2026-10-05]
hardware/gehaeuse/gehaeuse.step
115.6 x 90.6 x 25.1 mm
Unterschale
Deckel
Lichtleiter_D11
Lichtleiter_D10
Lichtleiter_D1
Lichtleiter_D2
Lichtleiter_D3

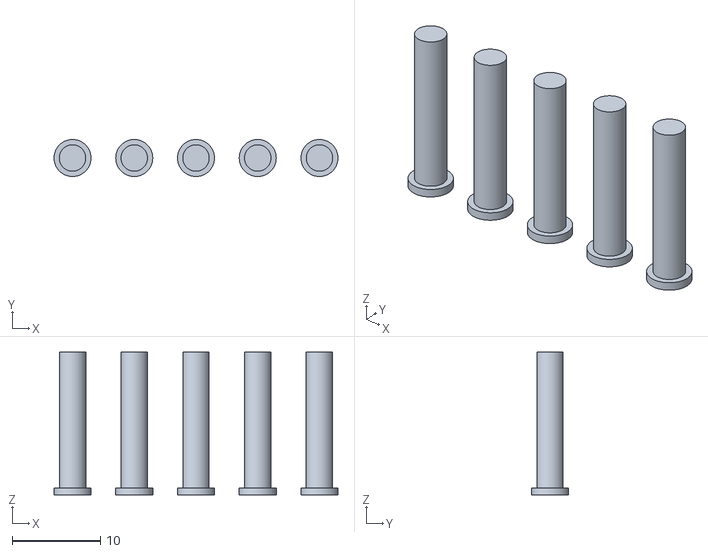
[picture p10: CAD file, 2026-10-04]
hardware/gehaeuse/druck/lichtleiter_5x.stl
32.2 x 4.20 x 16.2

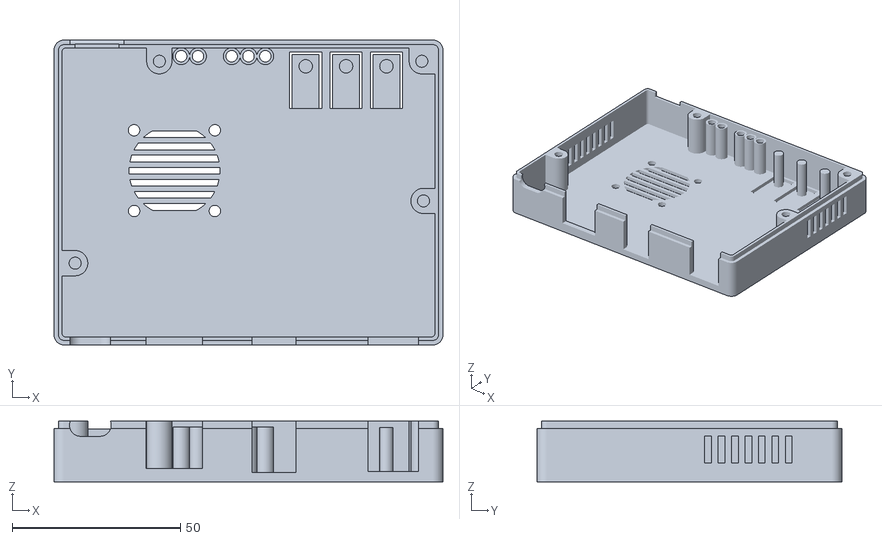
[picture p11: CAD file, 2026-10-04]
hardware/gehaeuse/druck/deckel.stl
115.6 x 90.6 x 18.0

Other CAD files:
hardware/gehaeuse/gehaeuse.FCStd

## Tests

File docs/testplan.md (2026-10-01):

# Testplan: Aufträge an die D340 (erster Sendetest)

Werkzeug: `tools/ergo.py` (Rahmen, Quittung, Log nach `logs/ergo_*.log`). Offline-Selbsttest vorher:
`python3 -m unittest discover -s gateway/tests -v`.

## Vorbedingungen (Nutzer)
- FTDI-Adapter am Laptop, 1:1-Kabel an der D340; `ls /dev/serial/by-id/` zeigt `usb-FTDI_FT232R_USB_UART_A97WEQGD…`.
- Merkmale → Optionen: „TAPI: Sprache über Telefon“ = Ein. Telefon in Ruhe (Hörer aufgelegt).

## Schritt 1 – Empfang mit 8O1 (frei) — erledigt 2026-10-01, fehlerfrei
`tools/ergo.py listen --dauer 60`, währenddessen anrufen, abheben, auflegen.
Erwartet: dieselben Meldungen wie `serial_20260930_163534.log`, jetzt mit Klartext.
Falls nur Salat: `--paritaet N` gegenprüfen.

## Schritt 2 – Anmelden (frei) — erledigt 2026-10-01: ACK `04 00`
`tools/ergo.py anmelden --dauer 20`
| Ergebnis | Bedeutung | nächster Versuch |
|---|---|---|
| `ACK …` binnen 5 s | Senderichtung bestätigt, ACK-Format notieren | Schritt 3 |
| `REJ …` | Rahmen verstanden, abgelehnt | Inhalt notieren, `keepalive` testen |
| `ERR` (`05 00`) nach ~1,5 s | nicht verstanden | `--paritaet N`, dann `--xonxoff` |
| nichts | – | Pegel/Stecker, `--paritaet N` |

## Schritt 3 – Keepalive (frei) — erledigt 2026-10-01: ACK `04 00`
`tools/ergo.py keepalive` → erwartet `ACK`.

## Schritt 4 – Gesprächsaufträge (nur nach Freigabe durch den Nutzer)
Reihenfolge, je einzeln und mit Rückfrage:
1. **Erledigt 2026-10-01** (`tools/ergo.py annahmetest --freigabe`). Eingehend annehmen: Nutzer ruft an → `tools/ergo.py annehmen --freigabe` während es klingelt.
   Erwartet: `ACK`, dann `CONNECTED`; Sprache über Hörer/Freisprechen (Schalter „über Telefon“).
2. **Erledigt 2026-10-01.** Auflegen: `tools/ergo.py auflegen --freigabe` → `ACK`, `DISCONNECTED`, `RELEASED`.
3. **Erledigt 2026-10-01 (extern, `tools/ergo.py waehltest 01… --freigabe`).** Wählen intern: `tools/ergo.py waehltest <Nebenstelle> --freigabe`.
   Hinweis: Der Treiber sendet vorher `belegen` (`01 02 11 00`) im Ruhezustand; bei `ERR`/`REJ` erst
   `tools/ergo.py belegen --freigabe`, dann `waehlen`.
4. **Erledigt 2026-10-01.** Wählen extern: Nummer mit Amtsholung `01`, nur mit Freigabe.
5. Nachwahl/DTMF im Gespräch (`roh`-Rahmen `19` mit einer Ziffer): hört die Gegenseite den Ton? Nur mit Freigabe.

## Danach
Ergebnisse in `docs/protocol.md` (Status „bestätigt“ mit Log), nützliche Logs in `logs/INDEX.md`, nutzlose löschen.

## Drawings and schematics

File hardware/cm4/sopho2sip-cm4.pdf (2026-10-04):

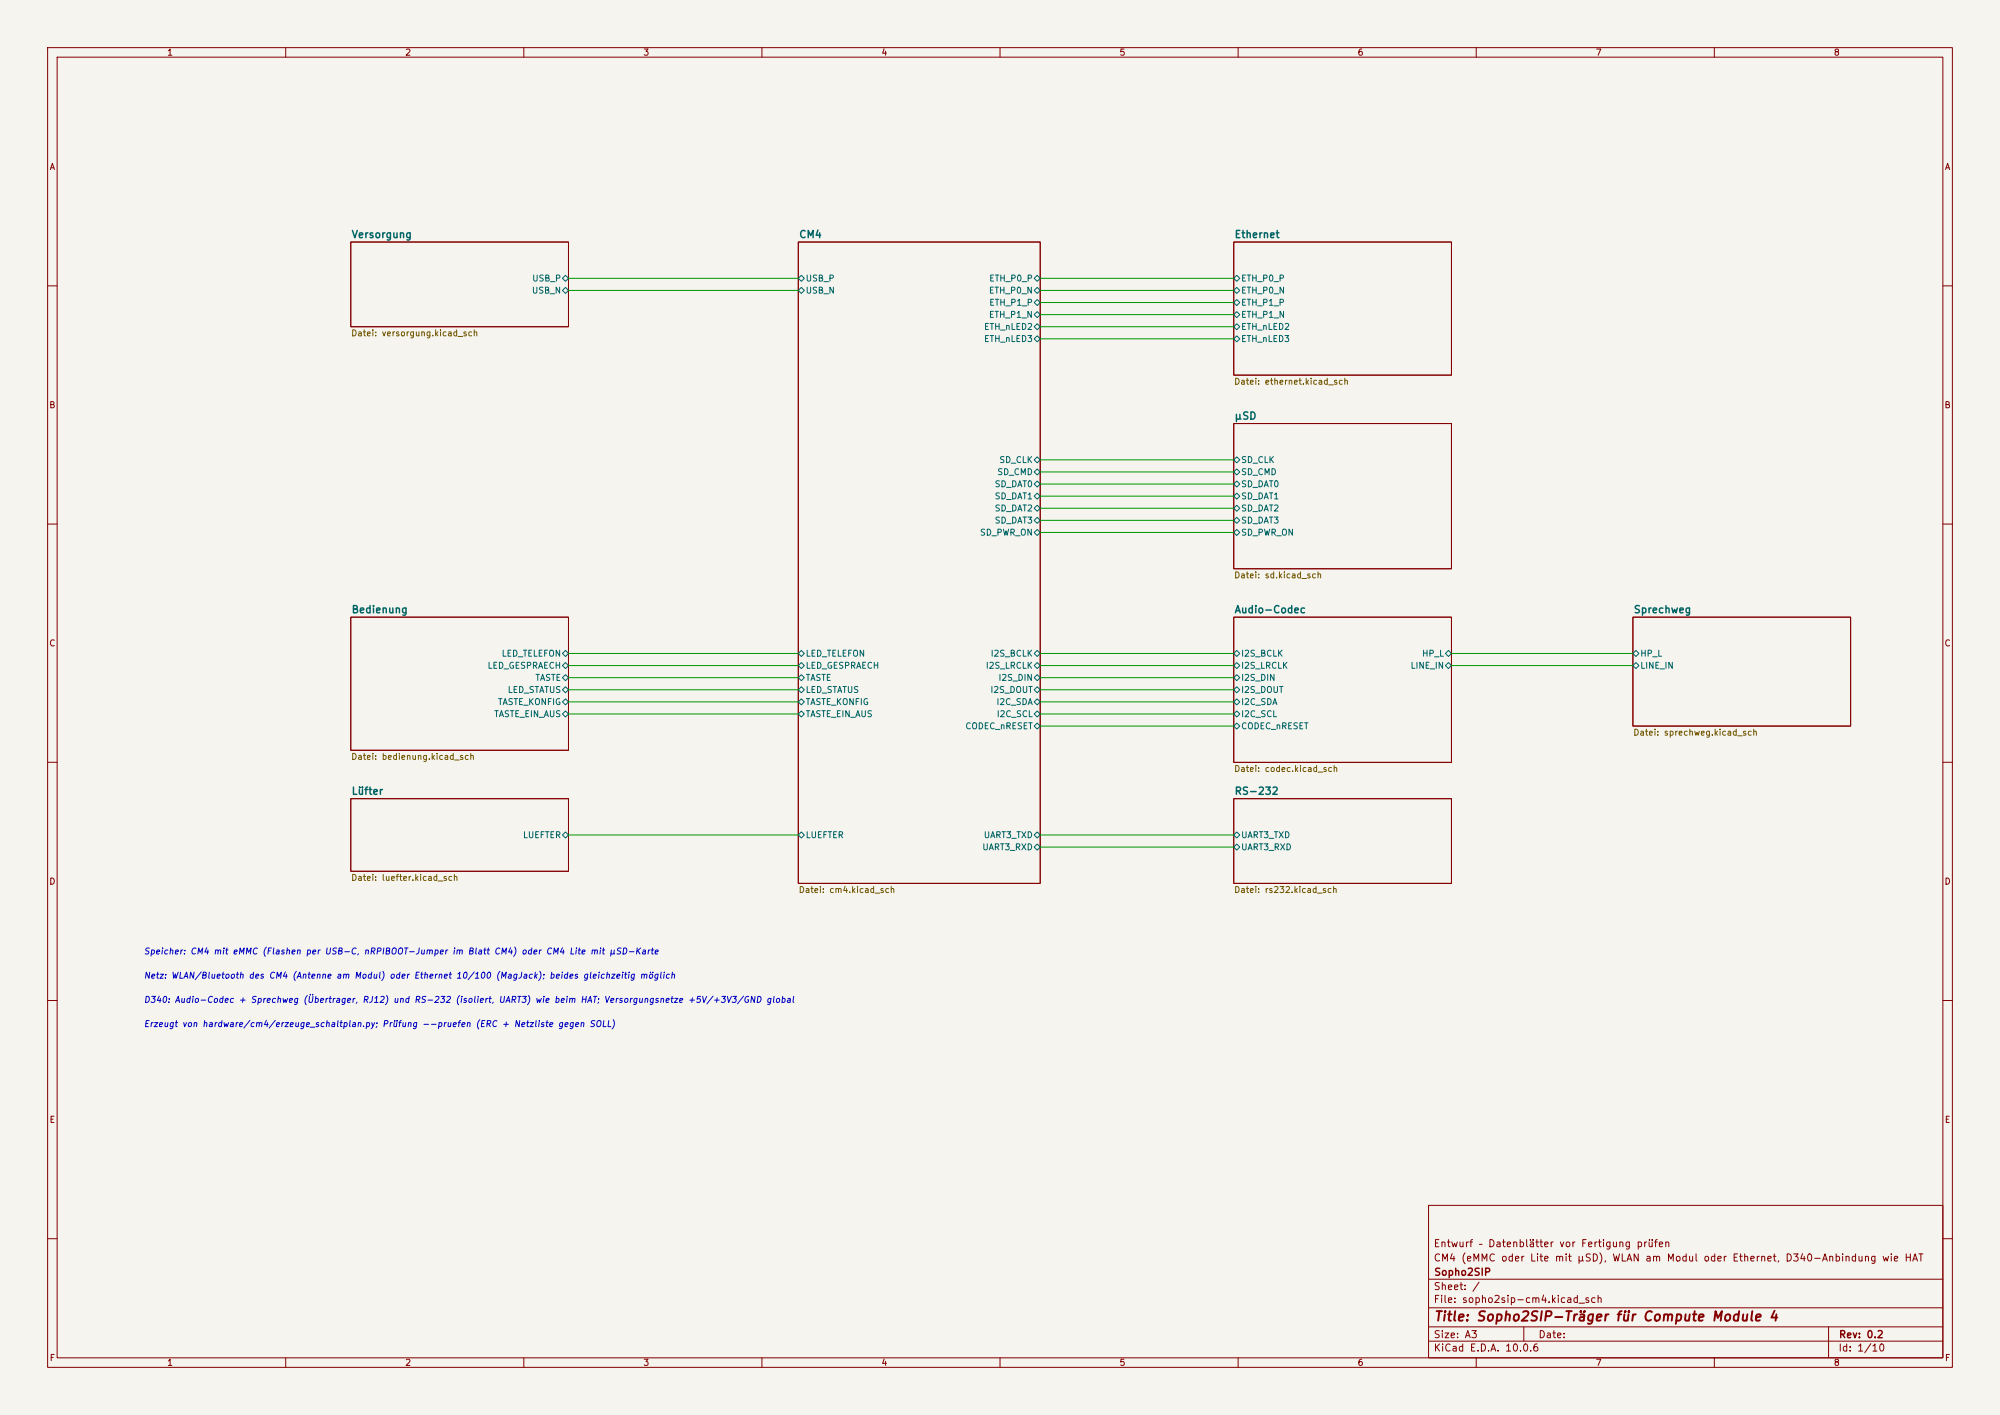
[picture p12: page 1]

Datei: codec.kicad_sch Speicher: CM4 mit eMMC (Flashen per USB-C, nRPIBOOT-Jumper im Blatt CM4) oder CM4 Lite mit µSD-Karte Netz: WLAN/Bluetooth des CM4 (Antenne am Modul) oder Ethernet 10/100 (MagJack); beides gleichzeitig möglich D340: Audio-Codec + Sprechweg (Übertrager, RJ12) und RS-232 (isoliert, UART3) wie beim HAT; Versorgungsnetze +5V/+3V3/GND global

Erzeugt von hardware/cm4/erzeuge_schaltplan.py; Prüfung --pruefen (ERC + Netzliste gegen SOLL)

Entwurf – Datenblätter vor Fertigung prüfen
CM4 (eMMC oder Lite mit µSD), WLAN am Modul oder Ethernet, D340-Anbindung wie HAT
Sopho2SIP
Sheet: /
File: sopho2sip-cm4.kicad_sch
Title: Sopho2SIP-Träger für Compute Module 4

Size: A3 | Rev: 0.2 | F Date:
KiCad E.D.A. 10.0.6 | Id: 1/10

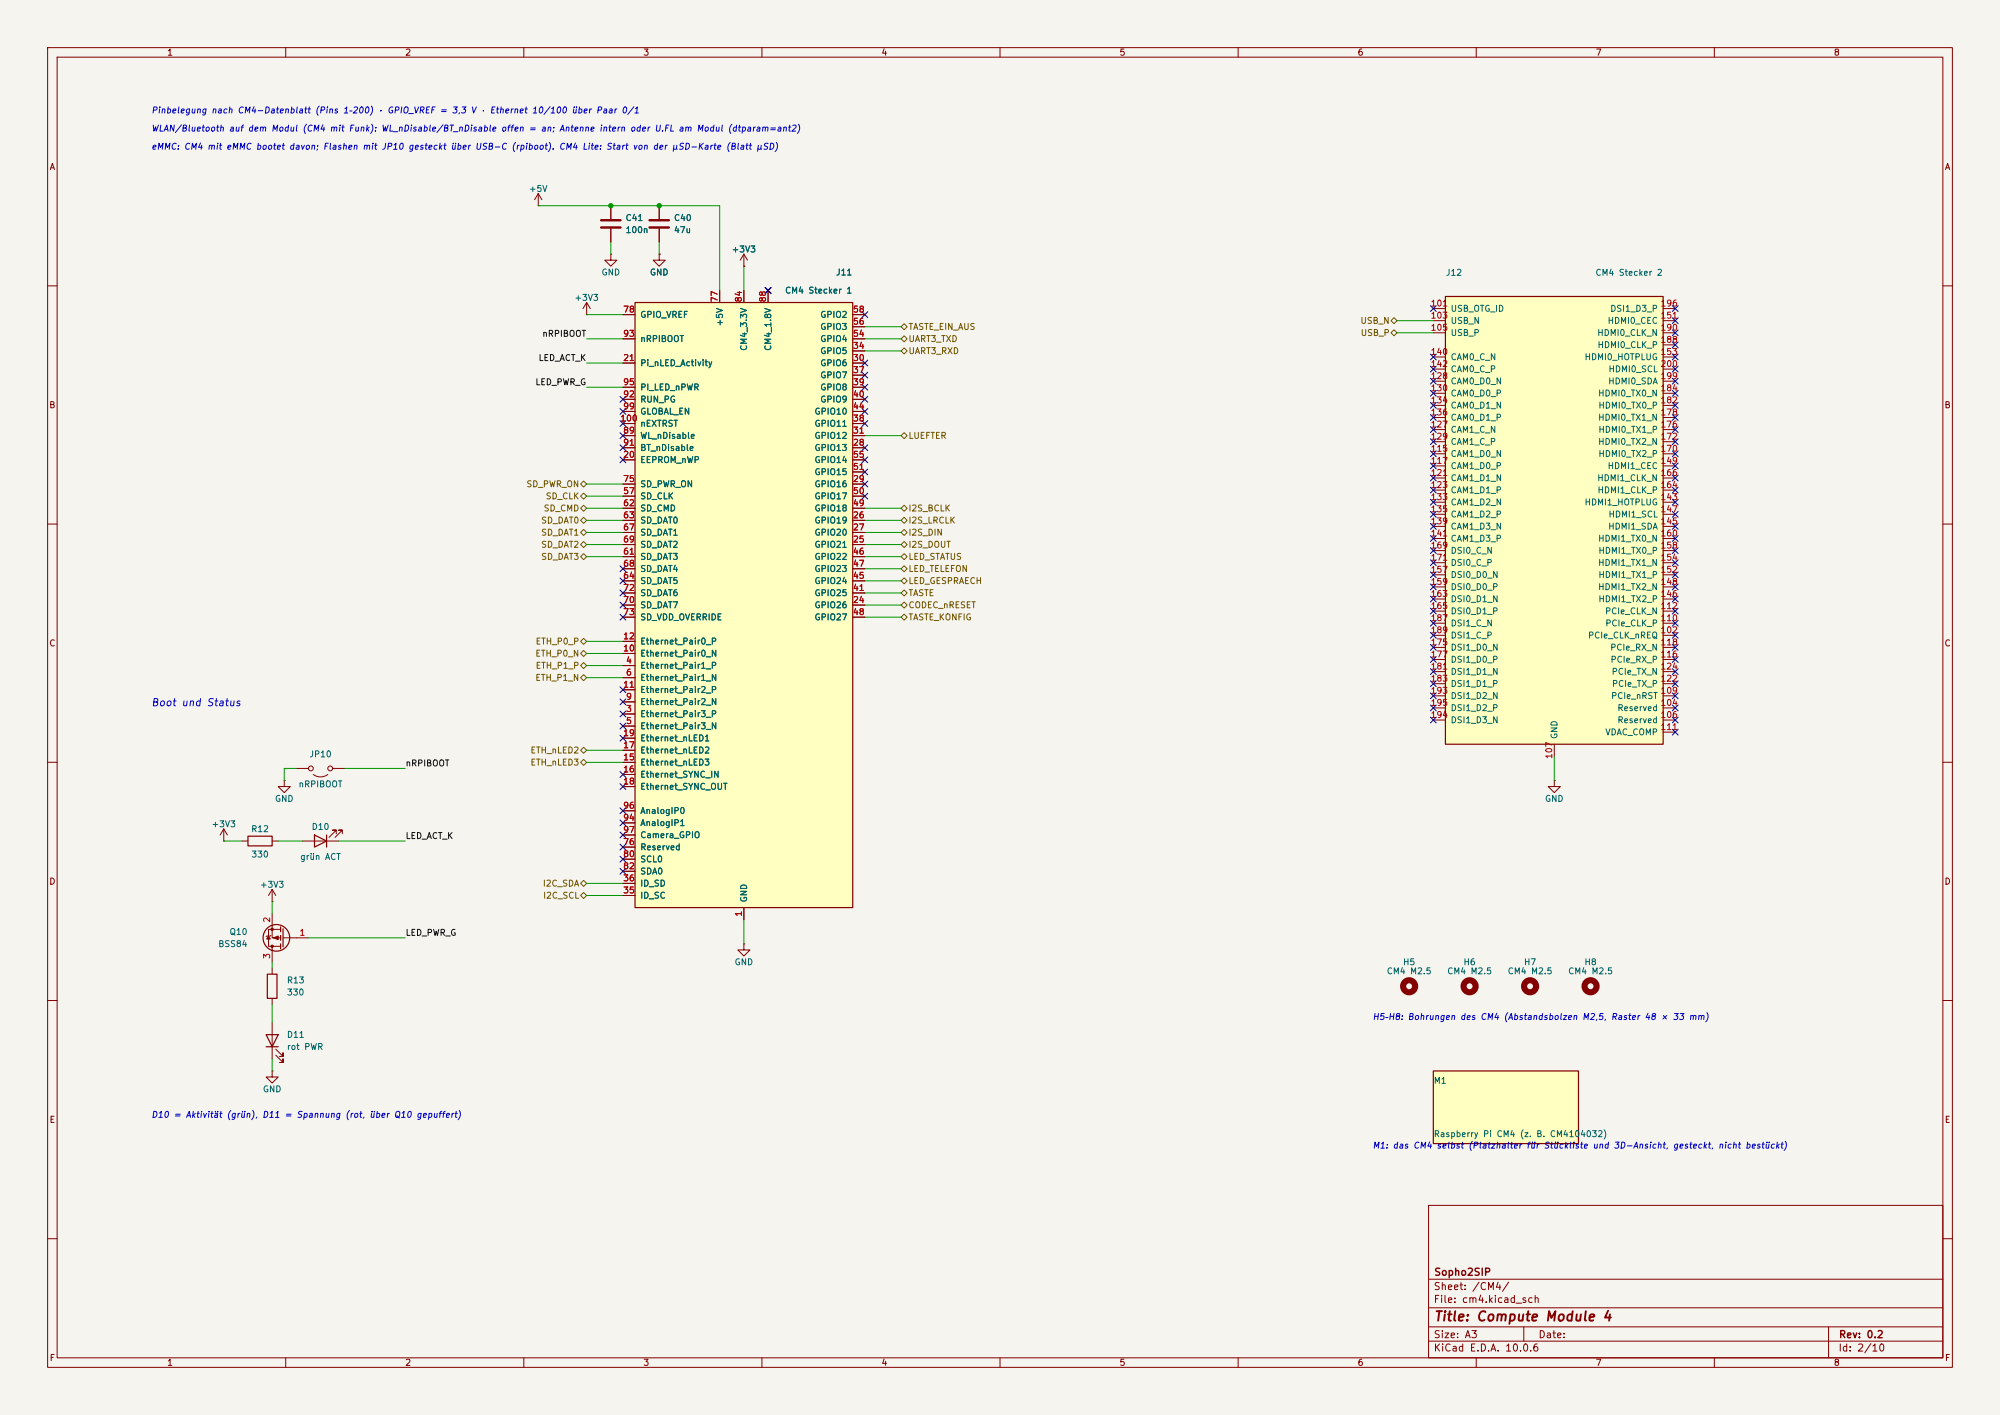
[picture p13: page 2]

Pinbelegung nach CM4-Datenblatt (Pins 1–200) · GPIO_VREF = 3,3 V · Ethernet 10/100 über Paar 0/1

WLAN/Bluetooth auf dem Modul (CM4 mit Funk): WL_nDisable/BT_nDisable offen = an; Antenne intern oder U.FL am Modul (dtparam=ant2)

eMMC: CM4 mit eMMC bootet davon; Flashen mit JP10 gesteckt über USB-C (rpiboot). CM4 Lite: Start von der µSD-Karte (Blatt µSD)

H5–H8: Bohrungen des CM4 (Abstandsbolzen M2,5, Raster 48 × 33 mm)

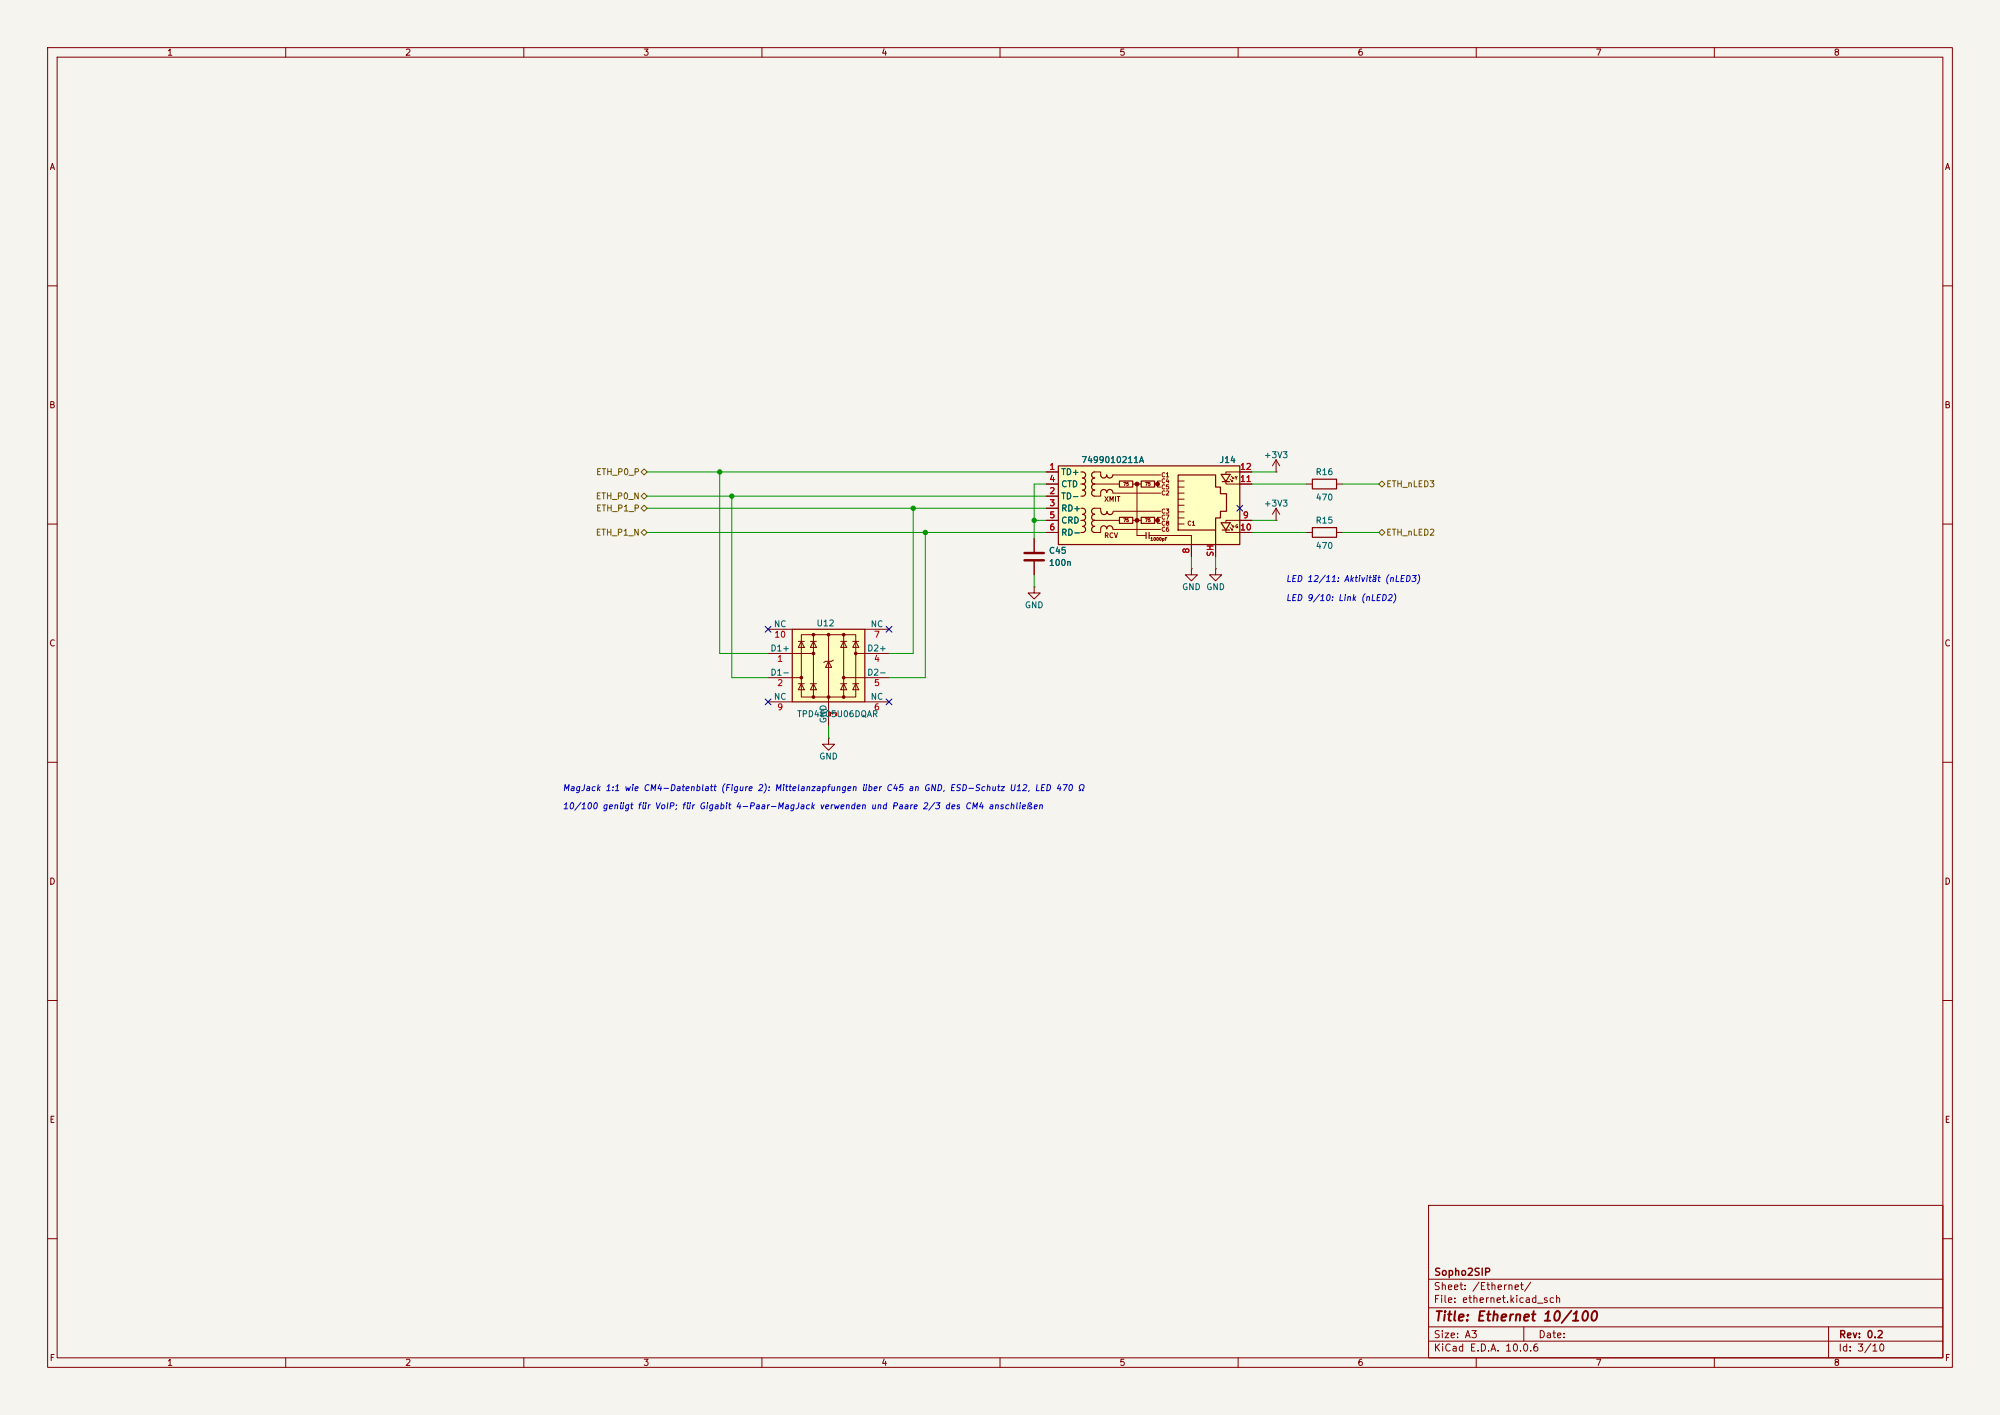
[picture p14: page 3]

10/100 genügt für VoIP; für Gigabit 4-Paar-MagJack verwenden und Paare 2/3 des CM4 anschließen C45

LED 12/11: Aktivität (nLED3) LED 9/10: Link (nLED2)

MagJack 1:1 wie CM4-Datenblatt (Figure 2): Mittelanzapfungen über C45 an GND, ESD-Schutz U12, LED 470 Ω

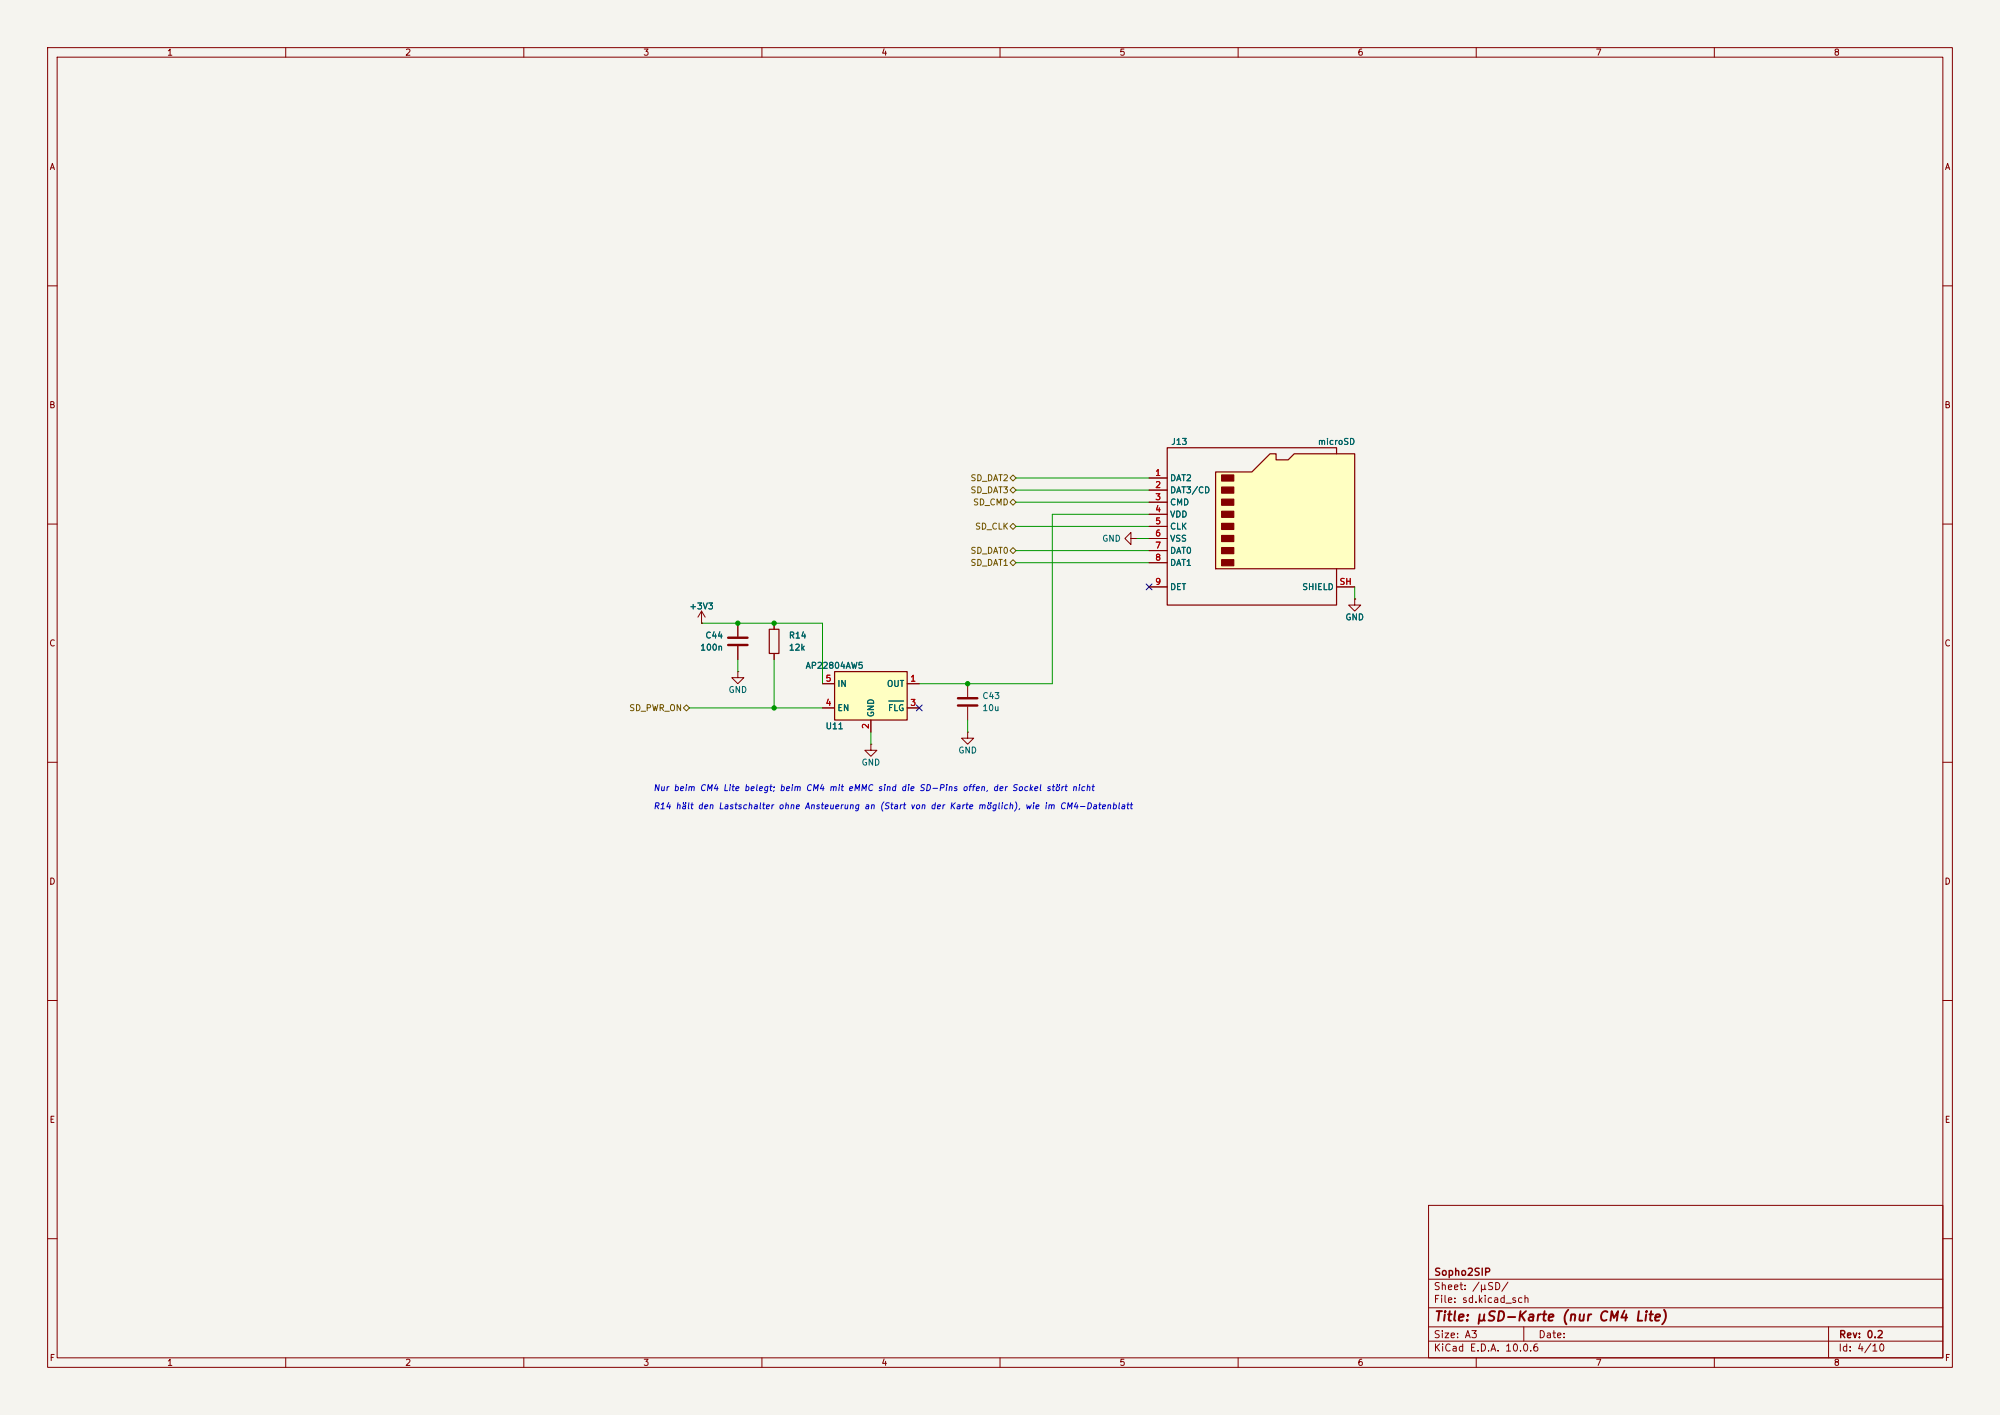
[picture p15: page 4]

R14 hält den Lastschalter ohne Ansteuerung an (Start von der Karte möglich), wie im CM4-Datenblatt Nur beim CM4 Lite belegt; beim CM4 mit eMMC sind die SD-Pins offen, der Sockel stört nicht

Sopho2SIP
Sheet: /µSD/
File: sd.kicad_sch
Title: µSD-Karte (nur CM4 Lite)

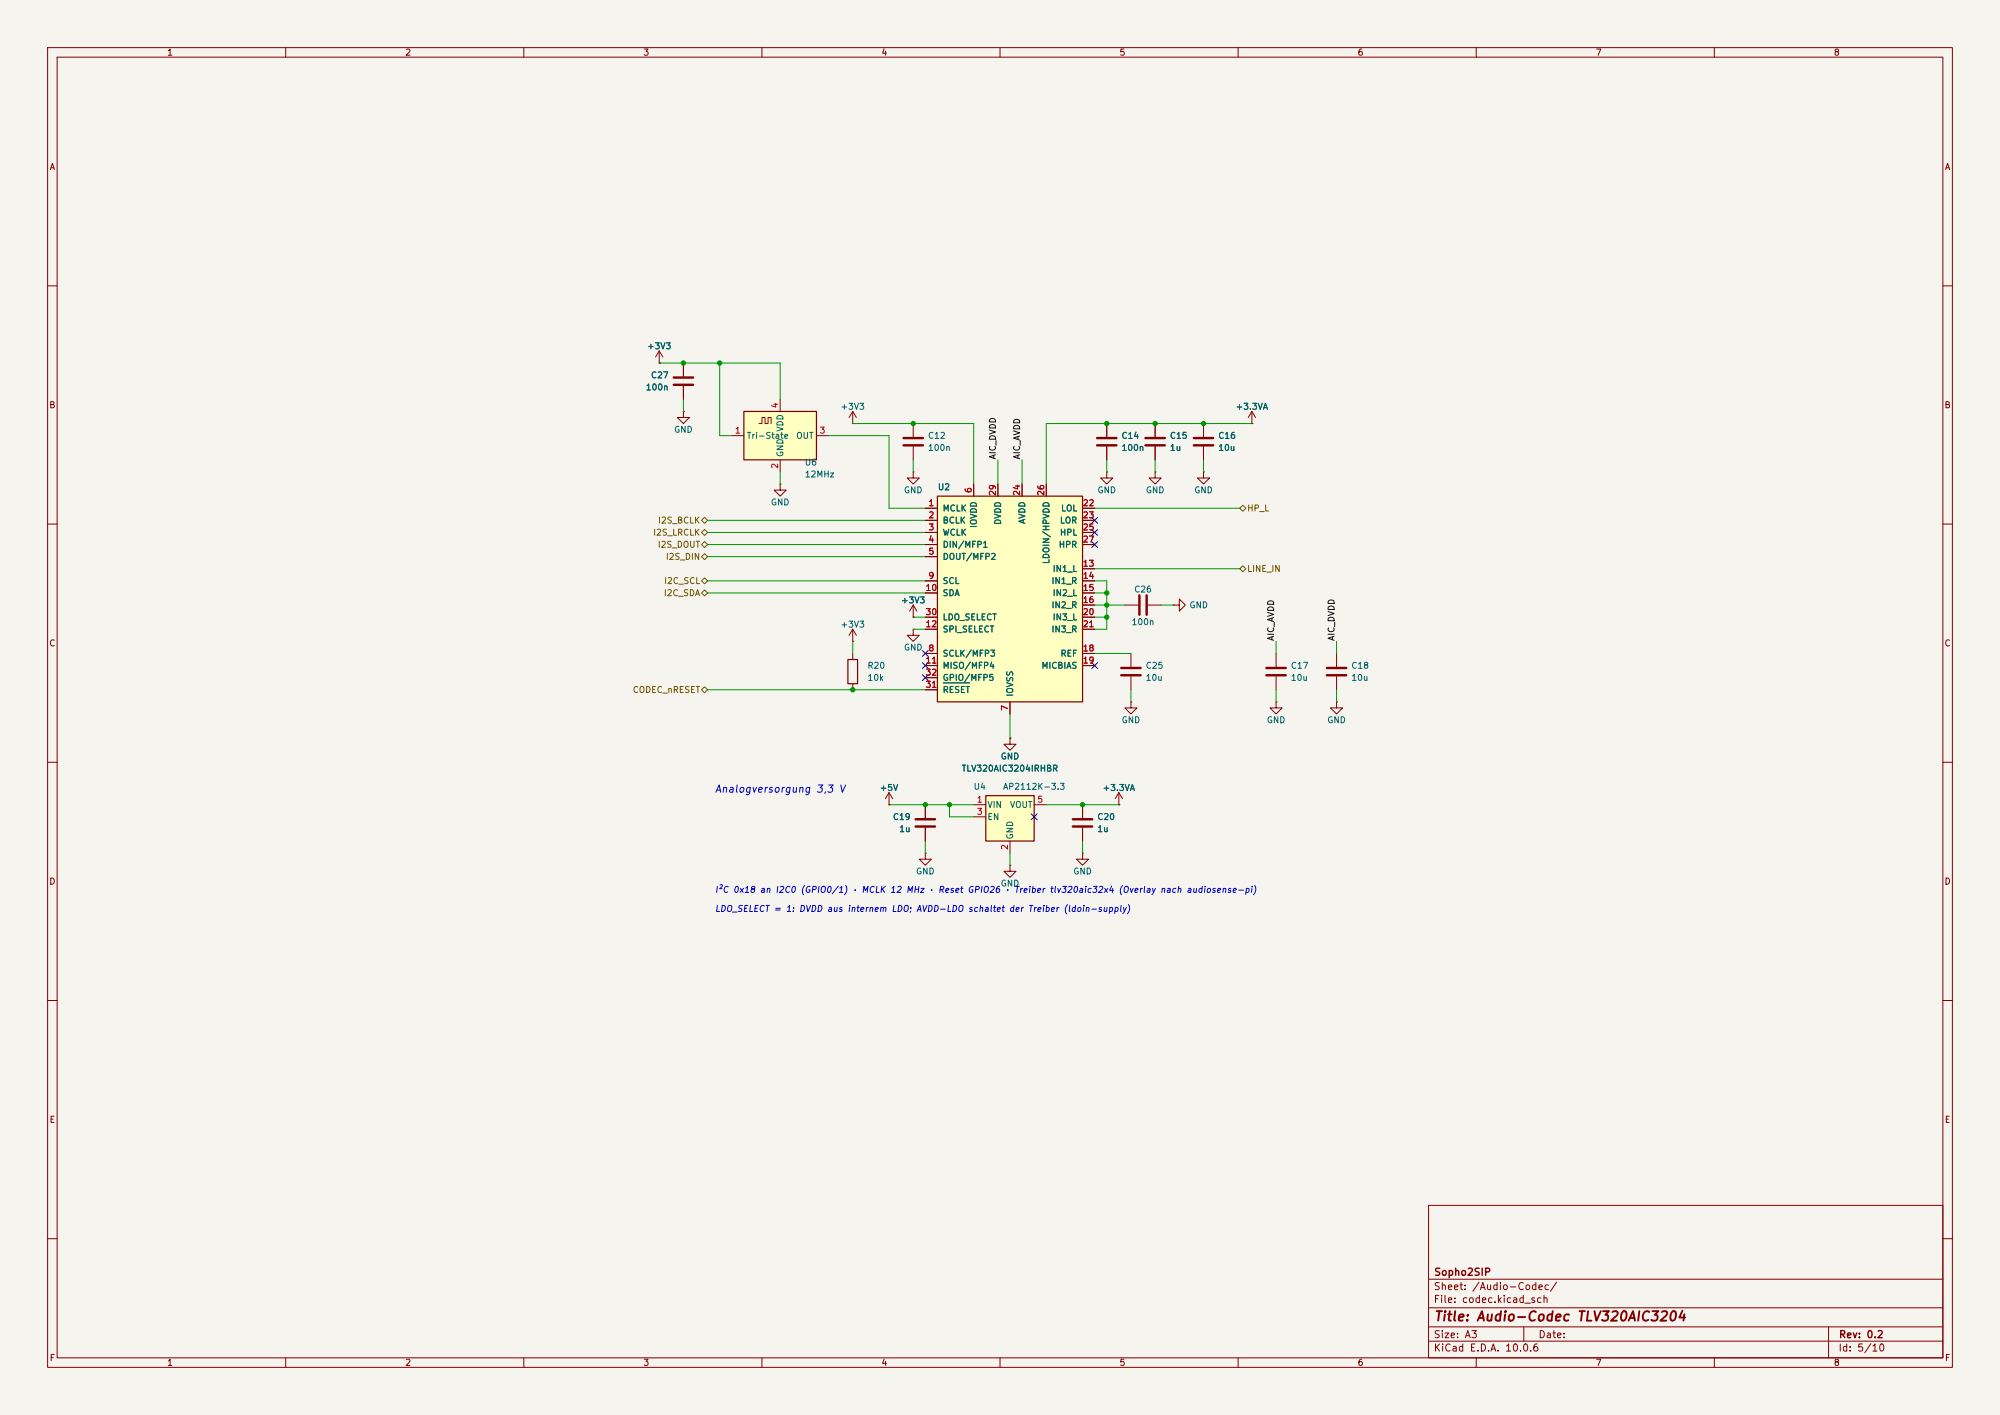
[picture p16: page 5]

I²C 0x18 an I2C0 (GPIO0/1) · MCLK 12 MHz · Reset GPIO26 · Treiber tlv320aic32x4 (Overlay nach audiosense-pi)

LDO_SELECT = 1: DVDD aus internem LDO; AVDD-LDO schaltet der Treiber (ldoin-supply)

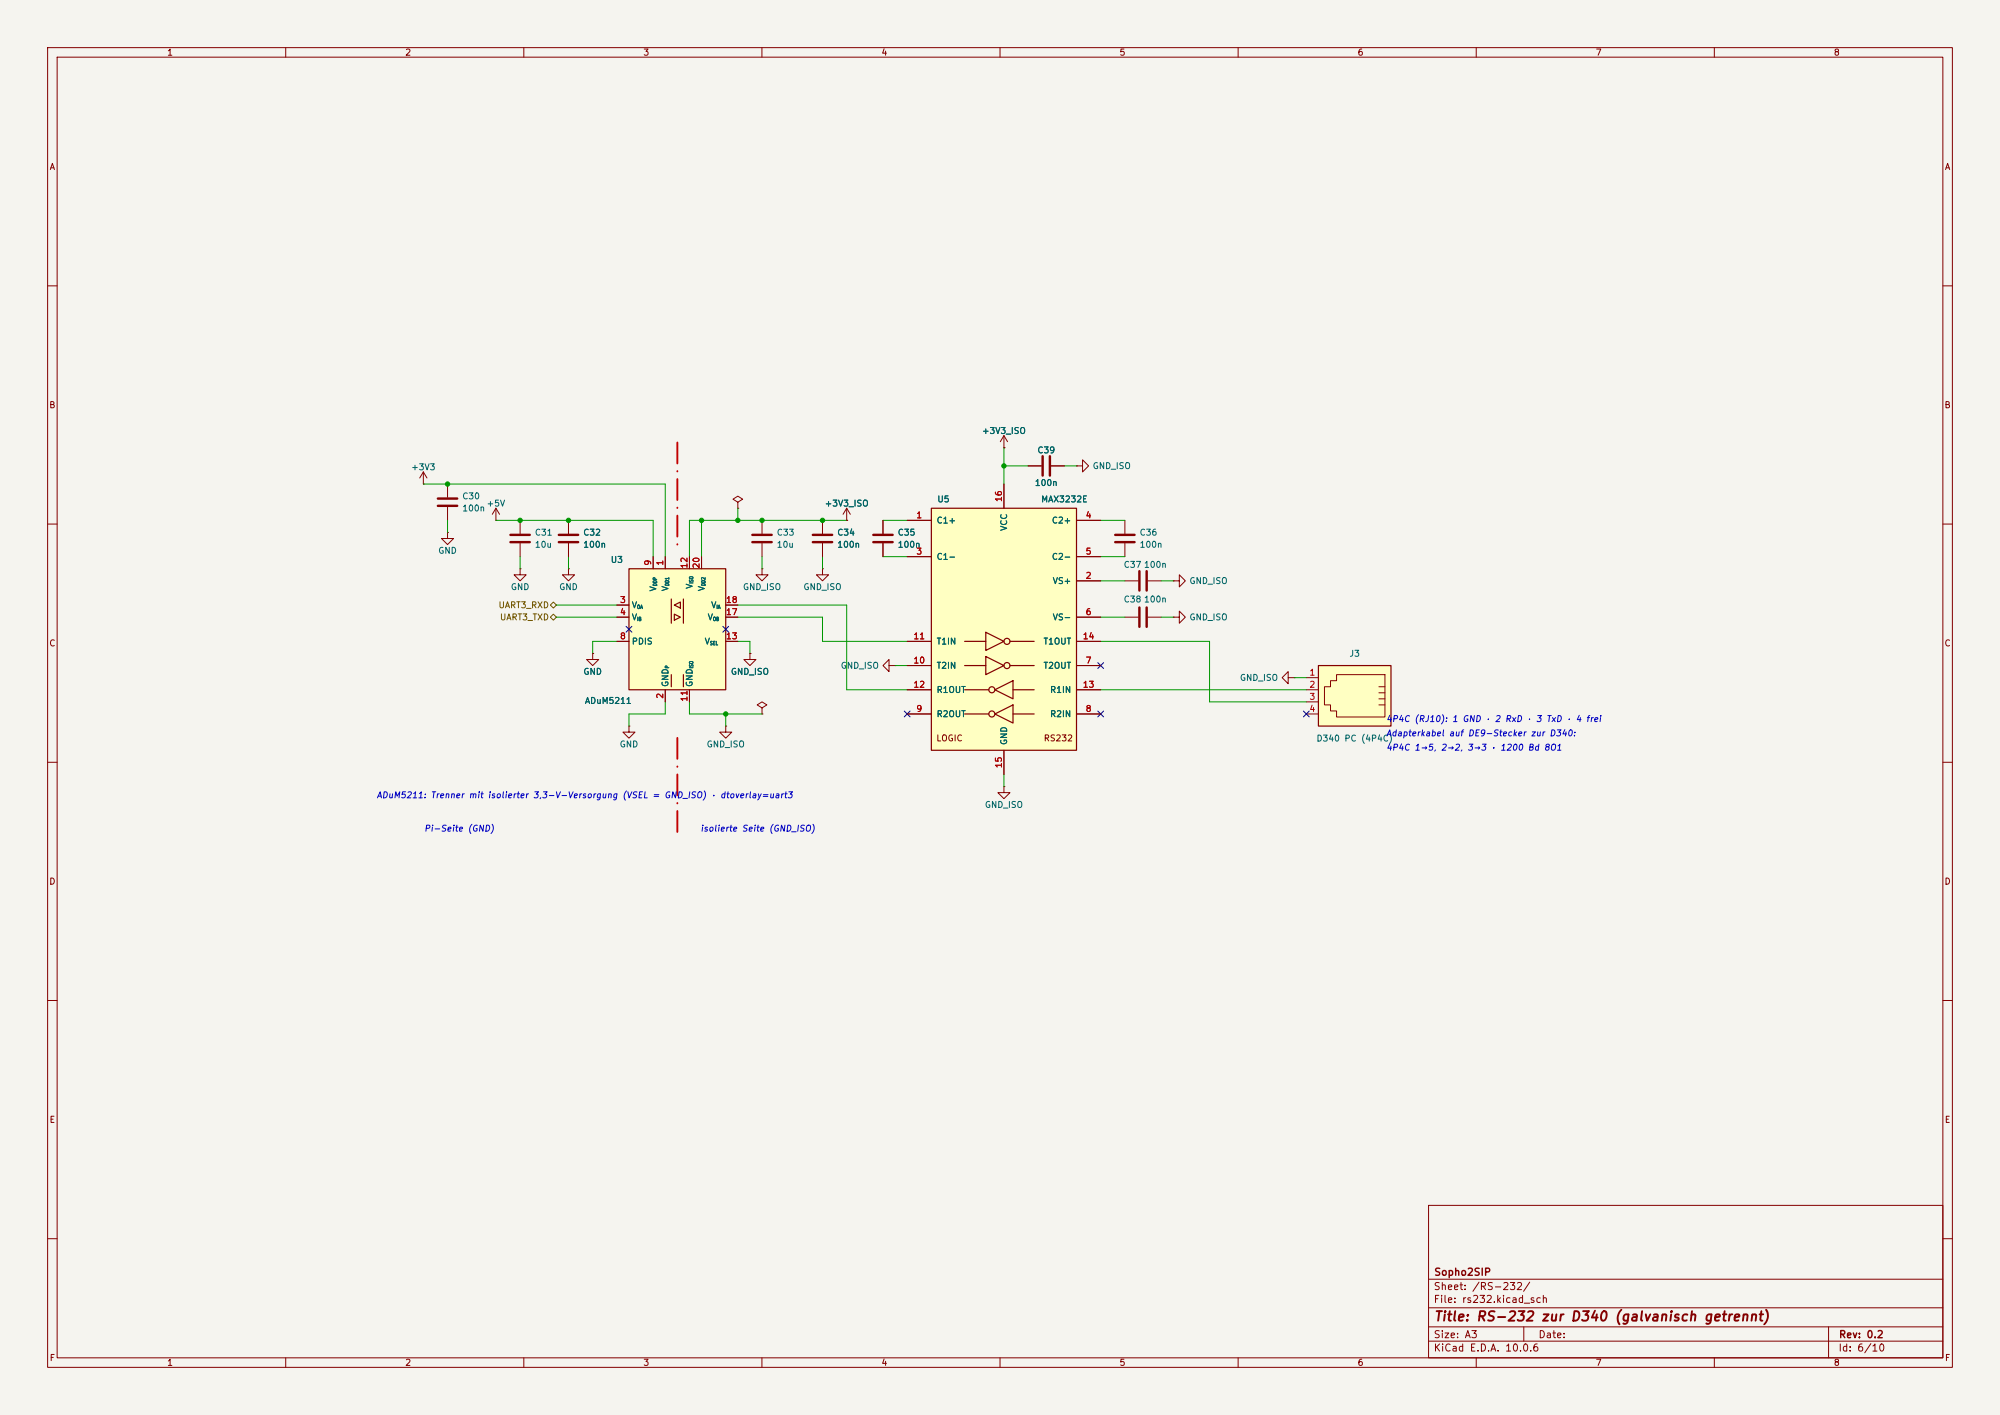
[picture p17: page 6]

Sopho2SIP
Sheet: /RS-232/
File: rs232.kicad_sch
Title: RS-232 zur D340 (galvanisch getrennt)

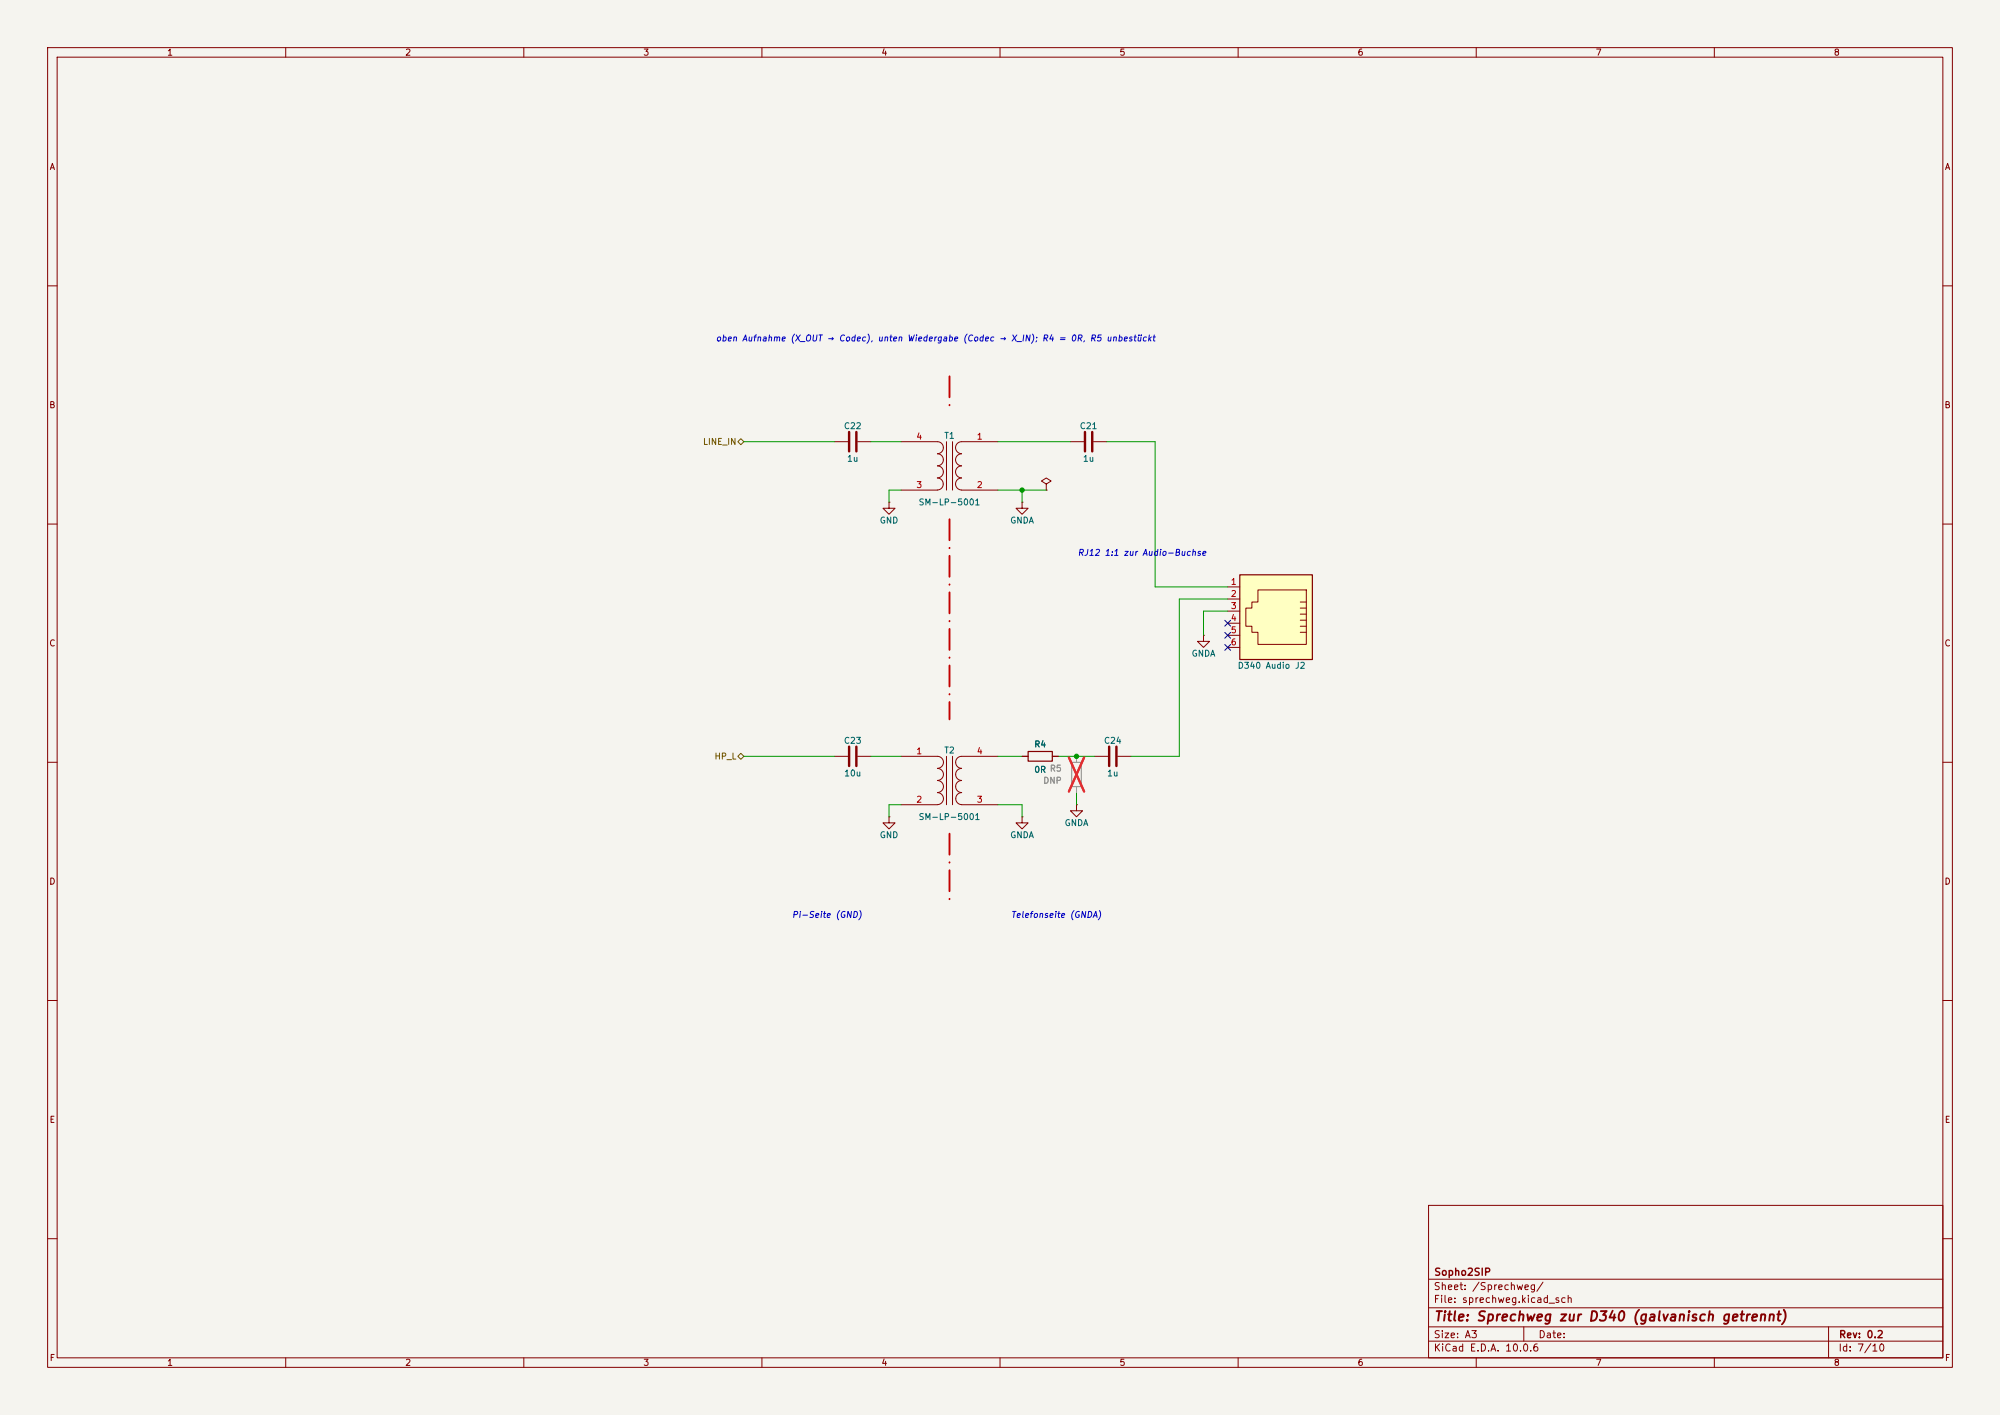
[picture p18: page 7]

oben Aufnahme (X_OUT → Codec), unten Wiedergabe (Codec → X_IN); R4 = 0R, R5 unbestückt RJ12 1:1 zur Audio-Buchse R5 DNP
1u GNDAR4

Sopho2SIP
Sheet: /Sprechweg/
File: sprechweg.kicad_sch
Title: Sprechweg zur D340 (galvanisch getrennt)

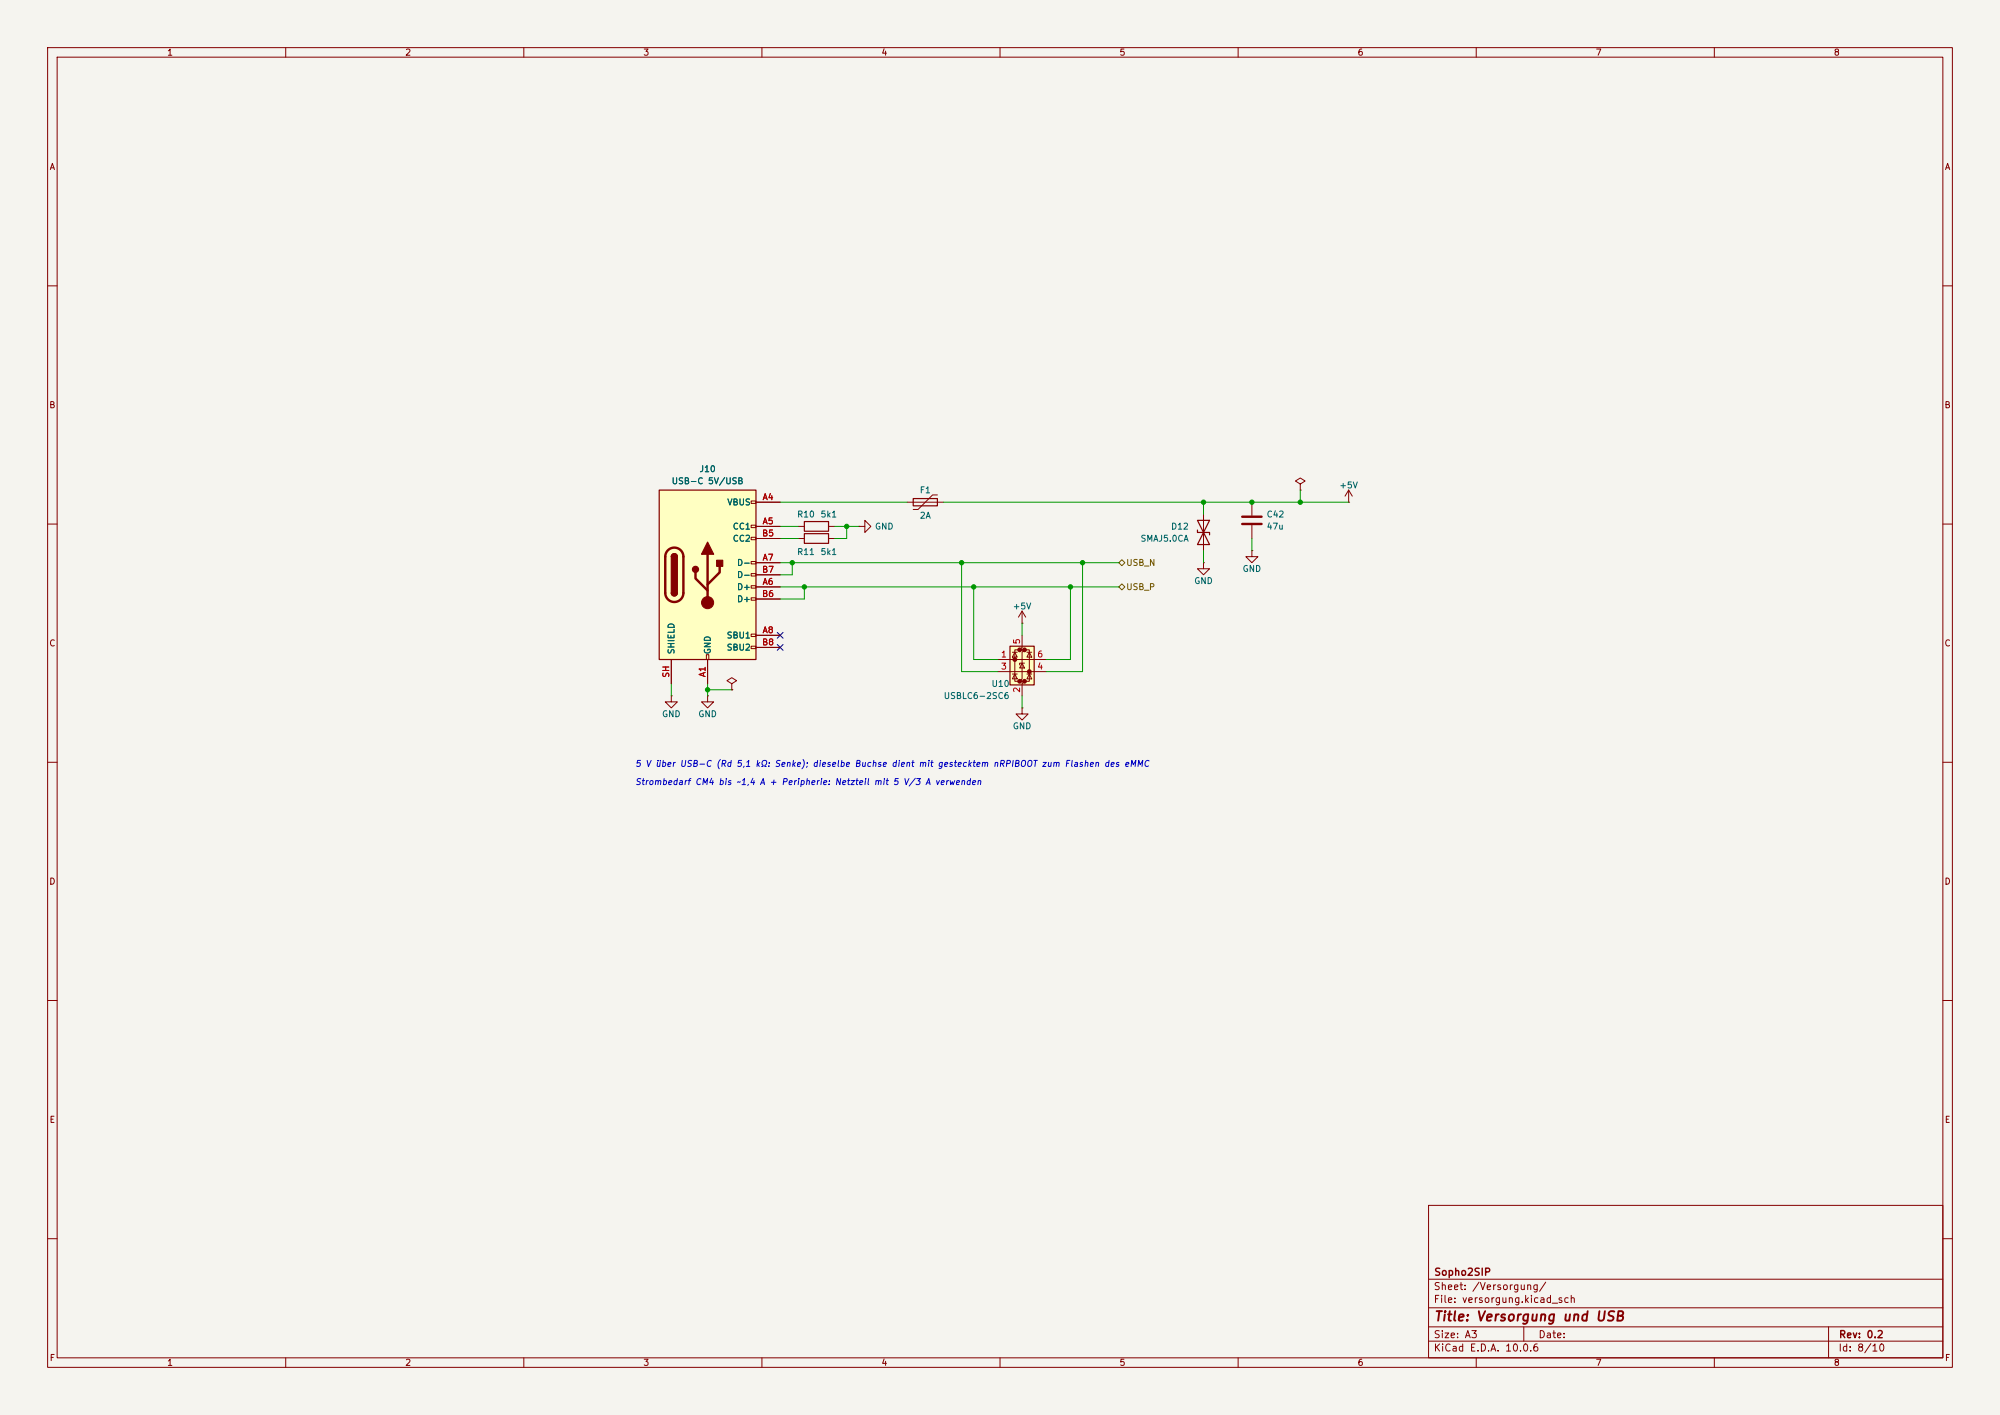
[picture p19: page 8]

5 V über USB-C (Rd 5,1 kΩ: Senke); dieselbe Buchse dient mit gestecktem nRPIBOOT zum Flashen des eMMC

Strombedarf CM4 bis ~1,4 A + Peripherie: Netzteil mit 5 V/3 A verwenden

Sopho2SIP
Sheet: /Versorgung/
File: versorgung.kicad_sch
Title: Versorgung und USB

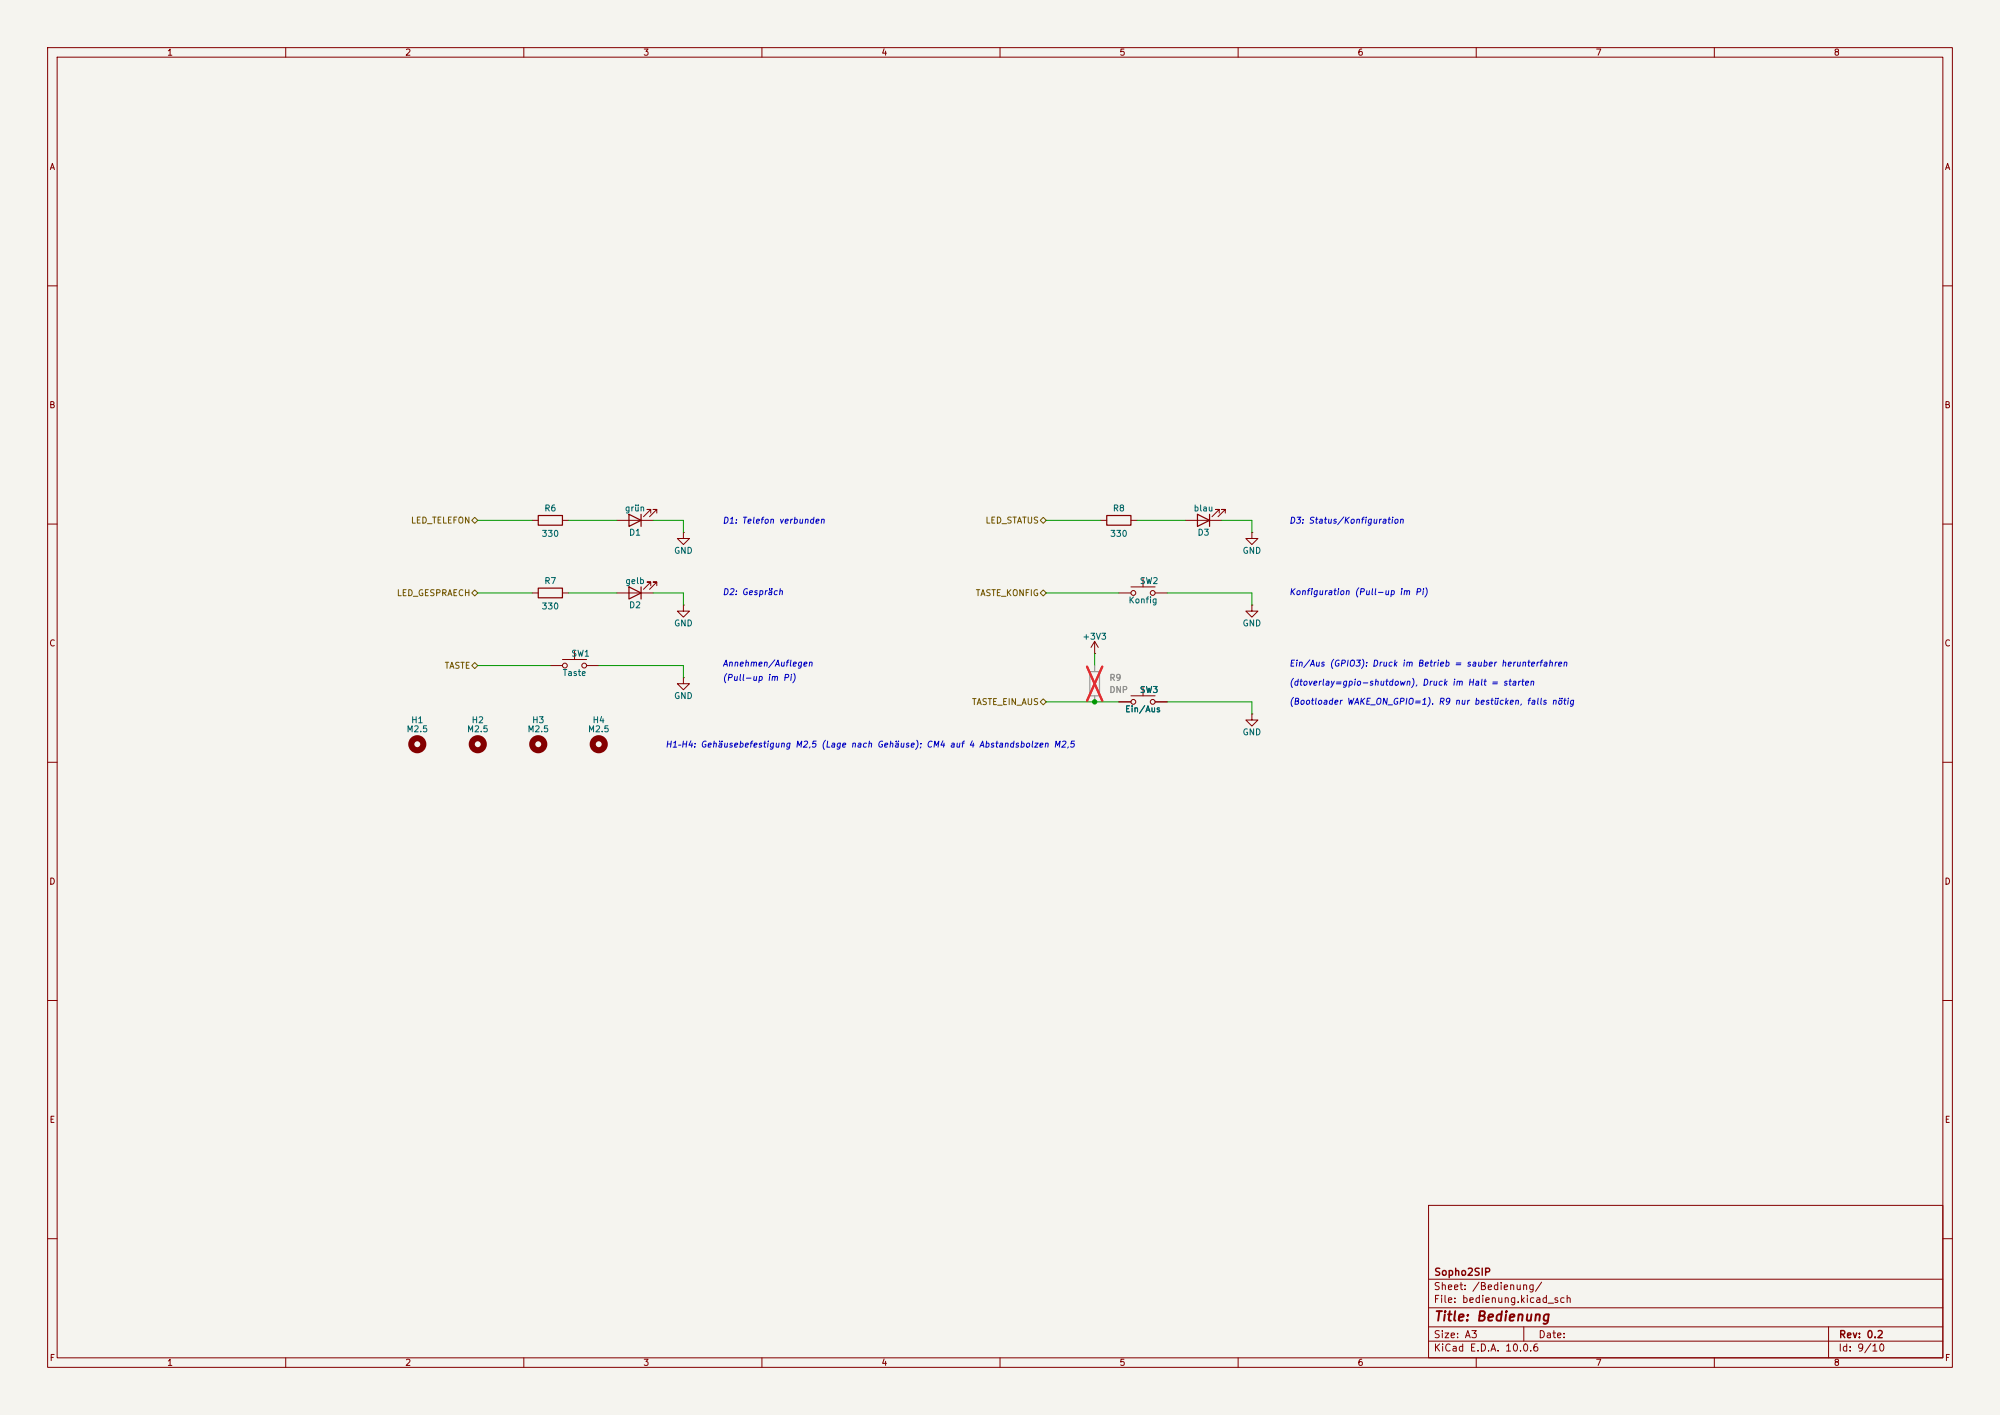
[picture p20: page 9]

Annehmen/Auflegen D2: Gespräch D1: Telefon verbunden

Ein/Aus (GPIO3): Druck im Betrieb = sauber herunterfahren Konfiguration (Pull-up im Pi) D3: Status/Konfiguration SW3

(Pull-up im Pi)

(dtoverlay=gpio-shutdown), Druck im Halt = starten

(Bootloader WAKE_ON_GPIO=1). R9 nur bestücken, falls nötig

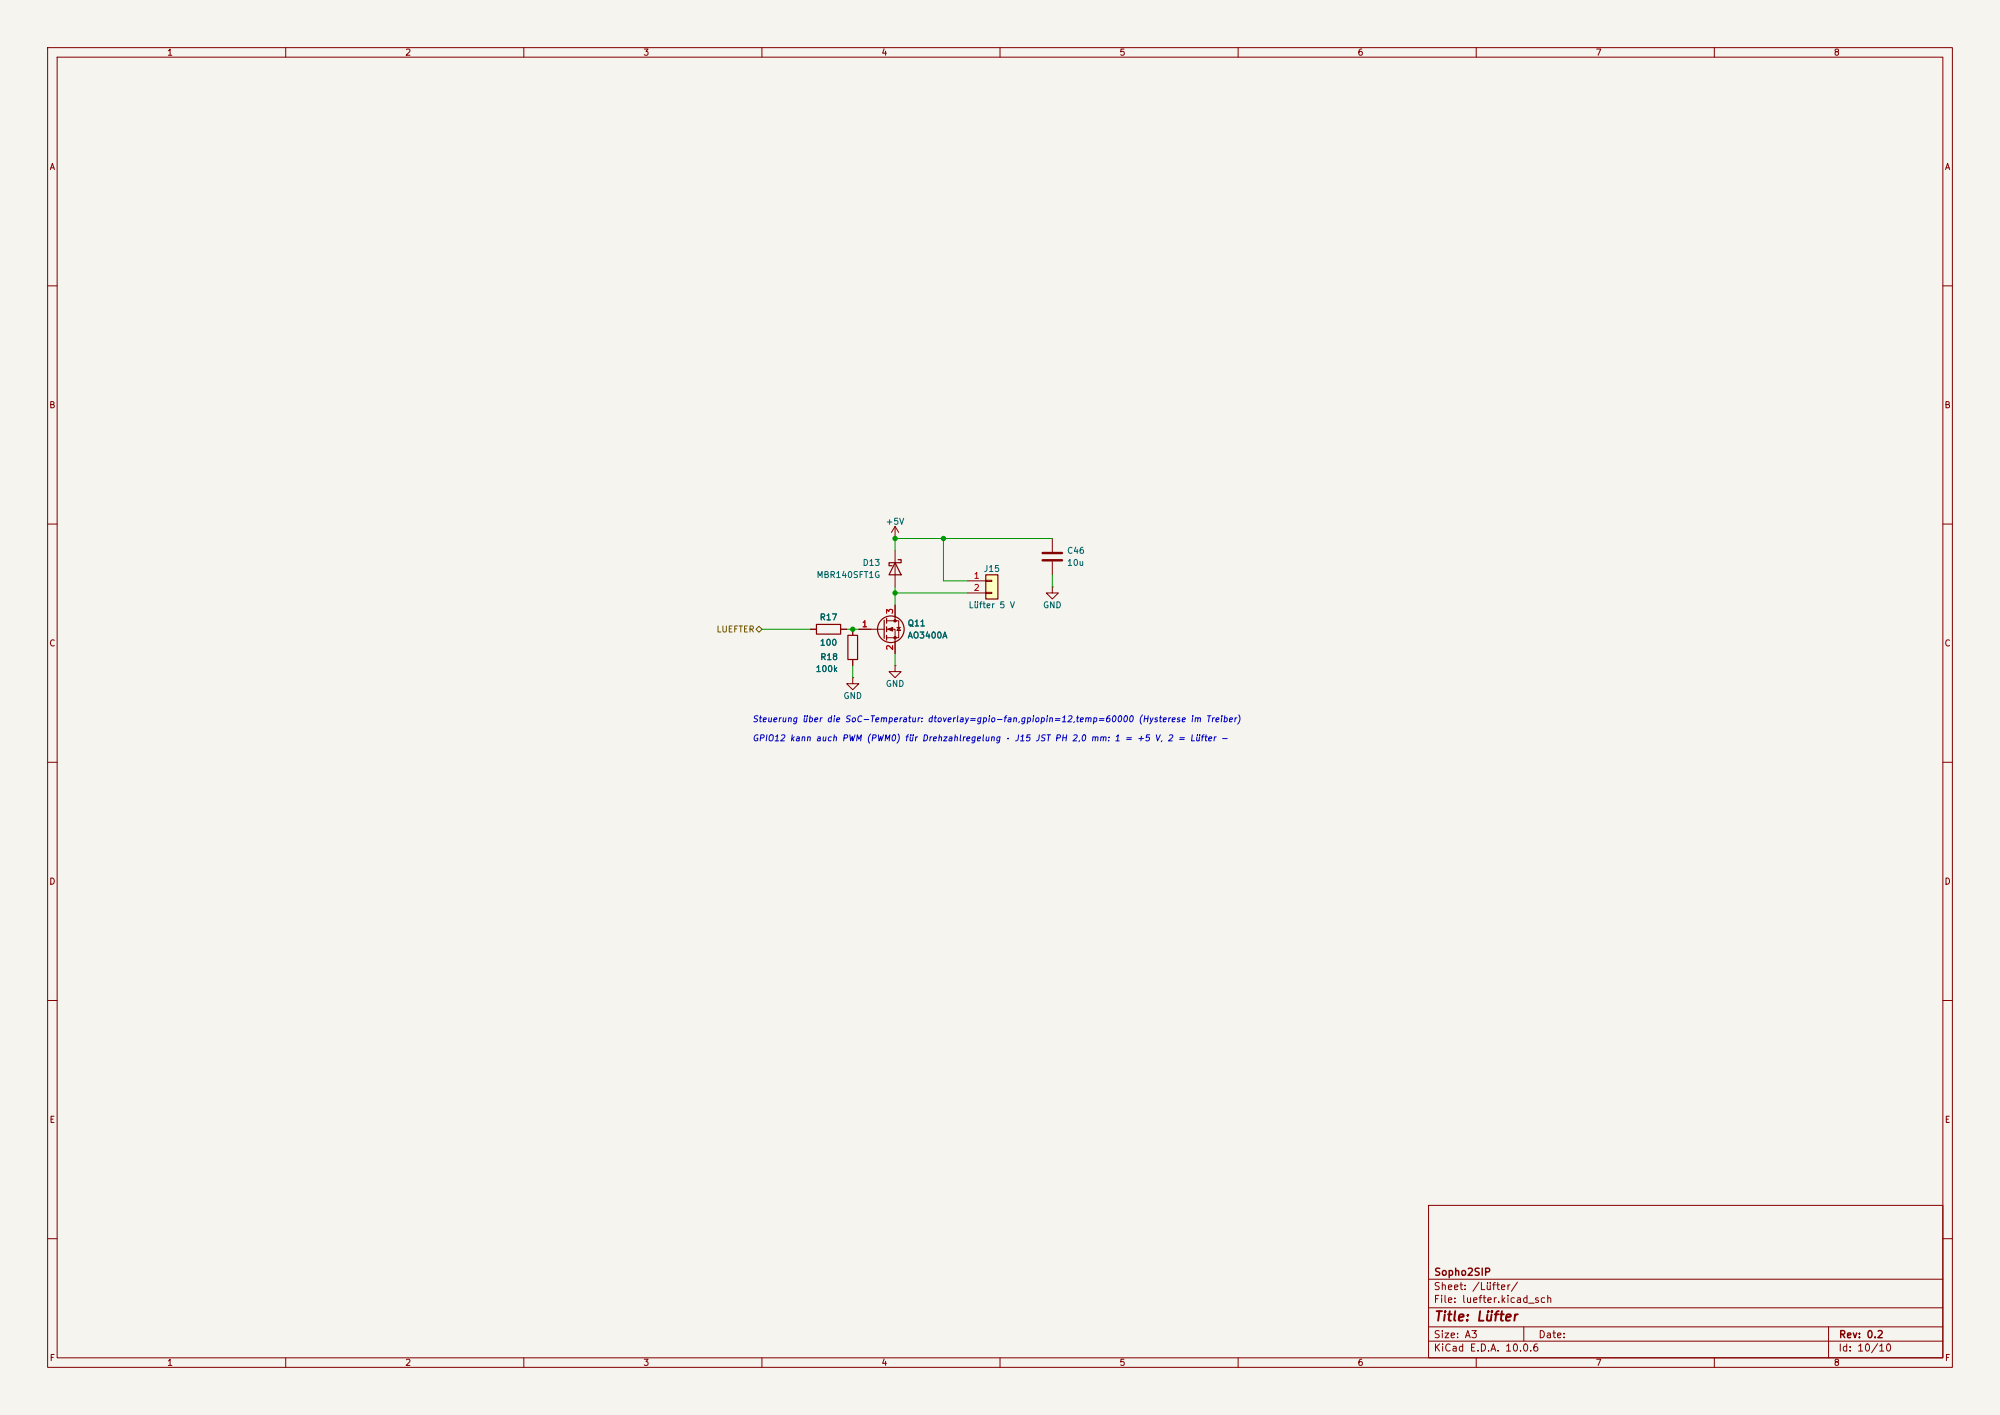
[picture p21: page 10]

Steuerung über die SoC-Temperatur: dtoverlay=gpio-fan,gpiopin=12,temp=60000 (Hysterese im Treiber) GPIO12 kann auch PWM (PWM0) für Drehzahlregelung · J15 JST PH 2,0 mm: 1 = +5 V, 2 = Lüfter −

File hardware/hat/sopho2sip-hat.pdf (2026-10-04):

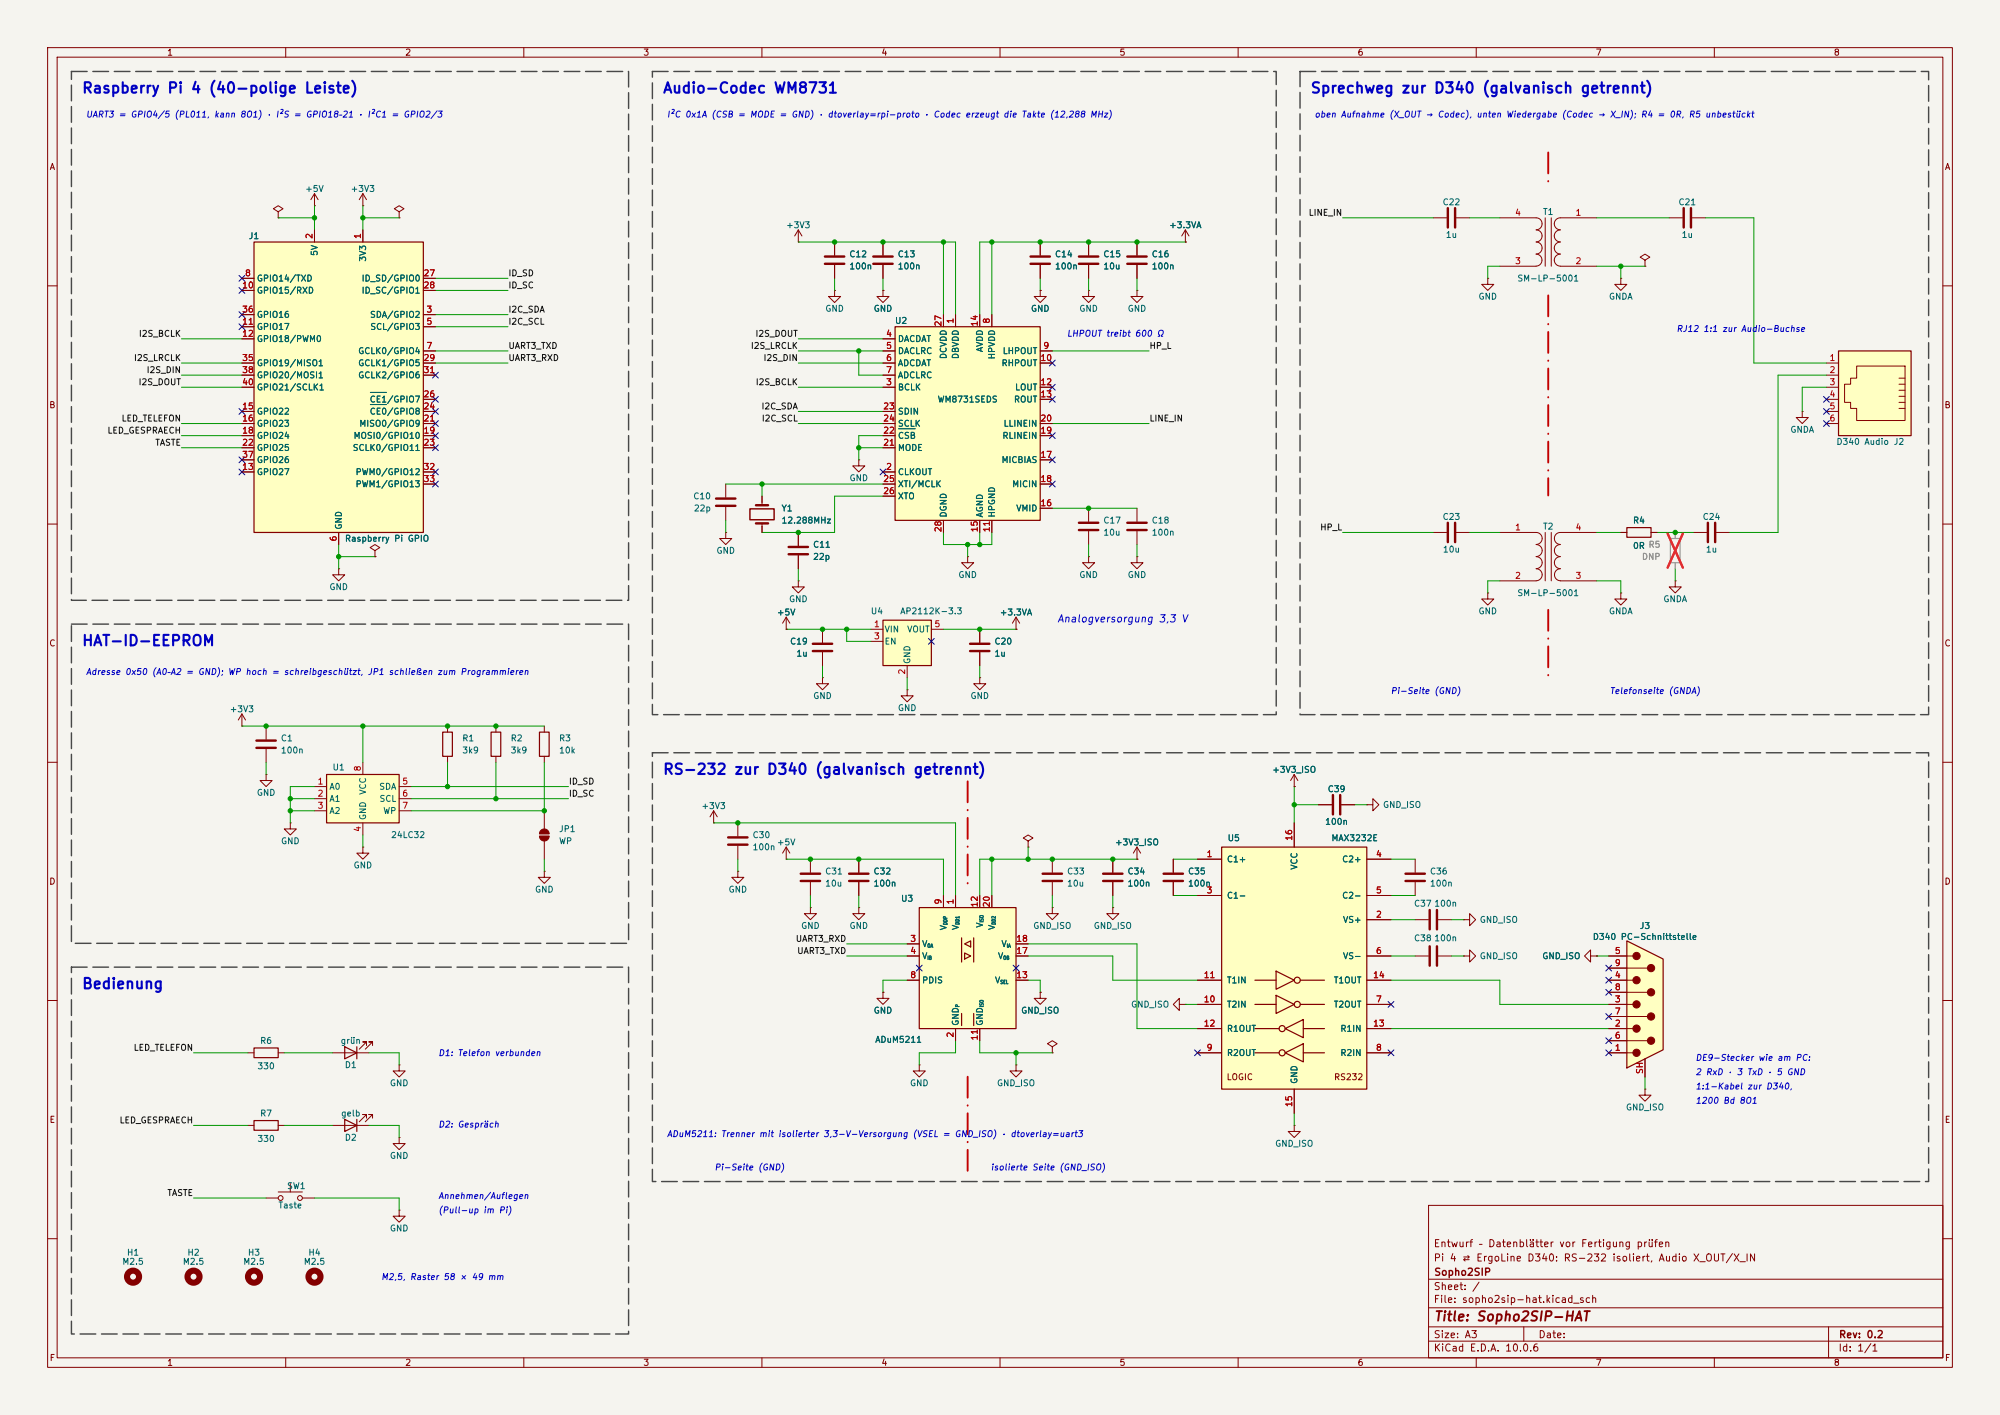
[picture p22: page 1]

Raspberry Pi 4 (40-polige Leiste)

I²C 0x1A (CSB = MODE = GND) · dtoverlay=rpi-proto · Codec erzeugt die Takte (12,288 MHz)

oben Aufnahme (X_OUT → Codec), unten Wiedergabe (Codec → X_IN); R4 = 0R, R5 unbestückt

LOUT 12 ROUT 13 AVDD 14 AGND 15

1 CLKOUT 2 BCLK 3 DACDAT 4 DACLRC 5

Telefonseite (GNDA) RJ12 1:1 zur Audio-Buchse

SDIN 23
VMID 16 MICBIAS 17 MICIN 18 RLINEIN 19 LLINEIN 20 MODE 21 CSB 22

RS-232 zur D340 (galvanisch getrennt)

Annehmen/Auflegen D1: Telefon verbunden

1:1-Kabel zur D340, Pi-Seite (GND)

ADuM5211: Trenner mit isolierter 3,3-V-Versorgung (VSEL = GND_ISO) · dtoverlay=uart3

(Pull-up im Pi)

Entwurf – Datenblätter vor Fertigung prüfen
Pi 4 ⇄ ErgoLine D340: RS-232 isoliert, Audio X_OUT/X_IN
Sopho2SIP
Sheet: /
File: sopho2sip-hat.kicad_sch
Title: Sopho2SIP-HAT

Size: A3 | Rev: 0.2 | F Date:
KiCad E.D.A. 10.0.6 | Id: 1/1

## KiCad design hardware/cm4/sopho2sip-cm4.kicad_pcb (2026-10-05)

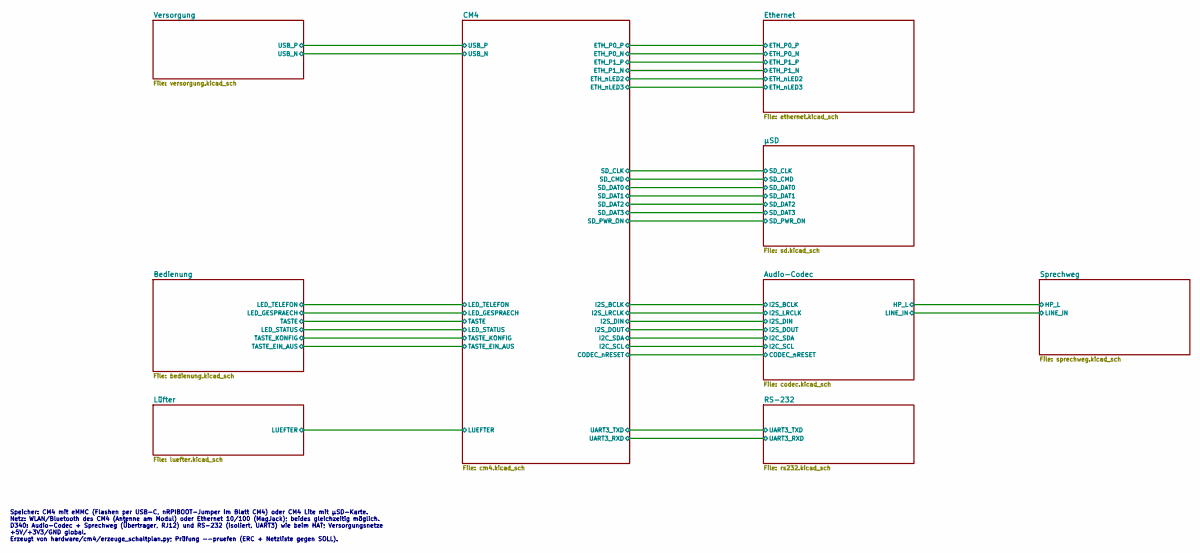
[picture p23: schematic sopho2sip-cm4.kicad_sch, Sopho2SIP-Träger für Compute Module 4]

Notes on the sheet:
Speicher: CM4 mit eMMC (Flashen per USB-C, nRPIBOOT-Jumper im Blatt CM4) oder CM4 Lite mit µSD-Karte. Netz: WLAN/Bluetooth des CM4 (Antenne am Modul) oder Ethernet 10/100 (MagJack); beides gleichzeitig möglich. D340: Audio-Codec + Sprechweg (Übertrager, RJ12) und RS-232 (isoliert, UART3) wie beim H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

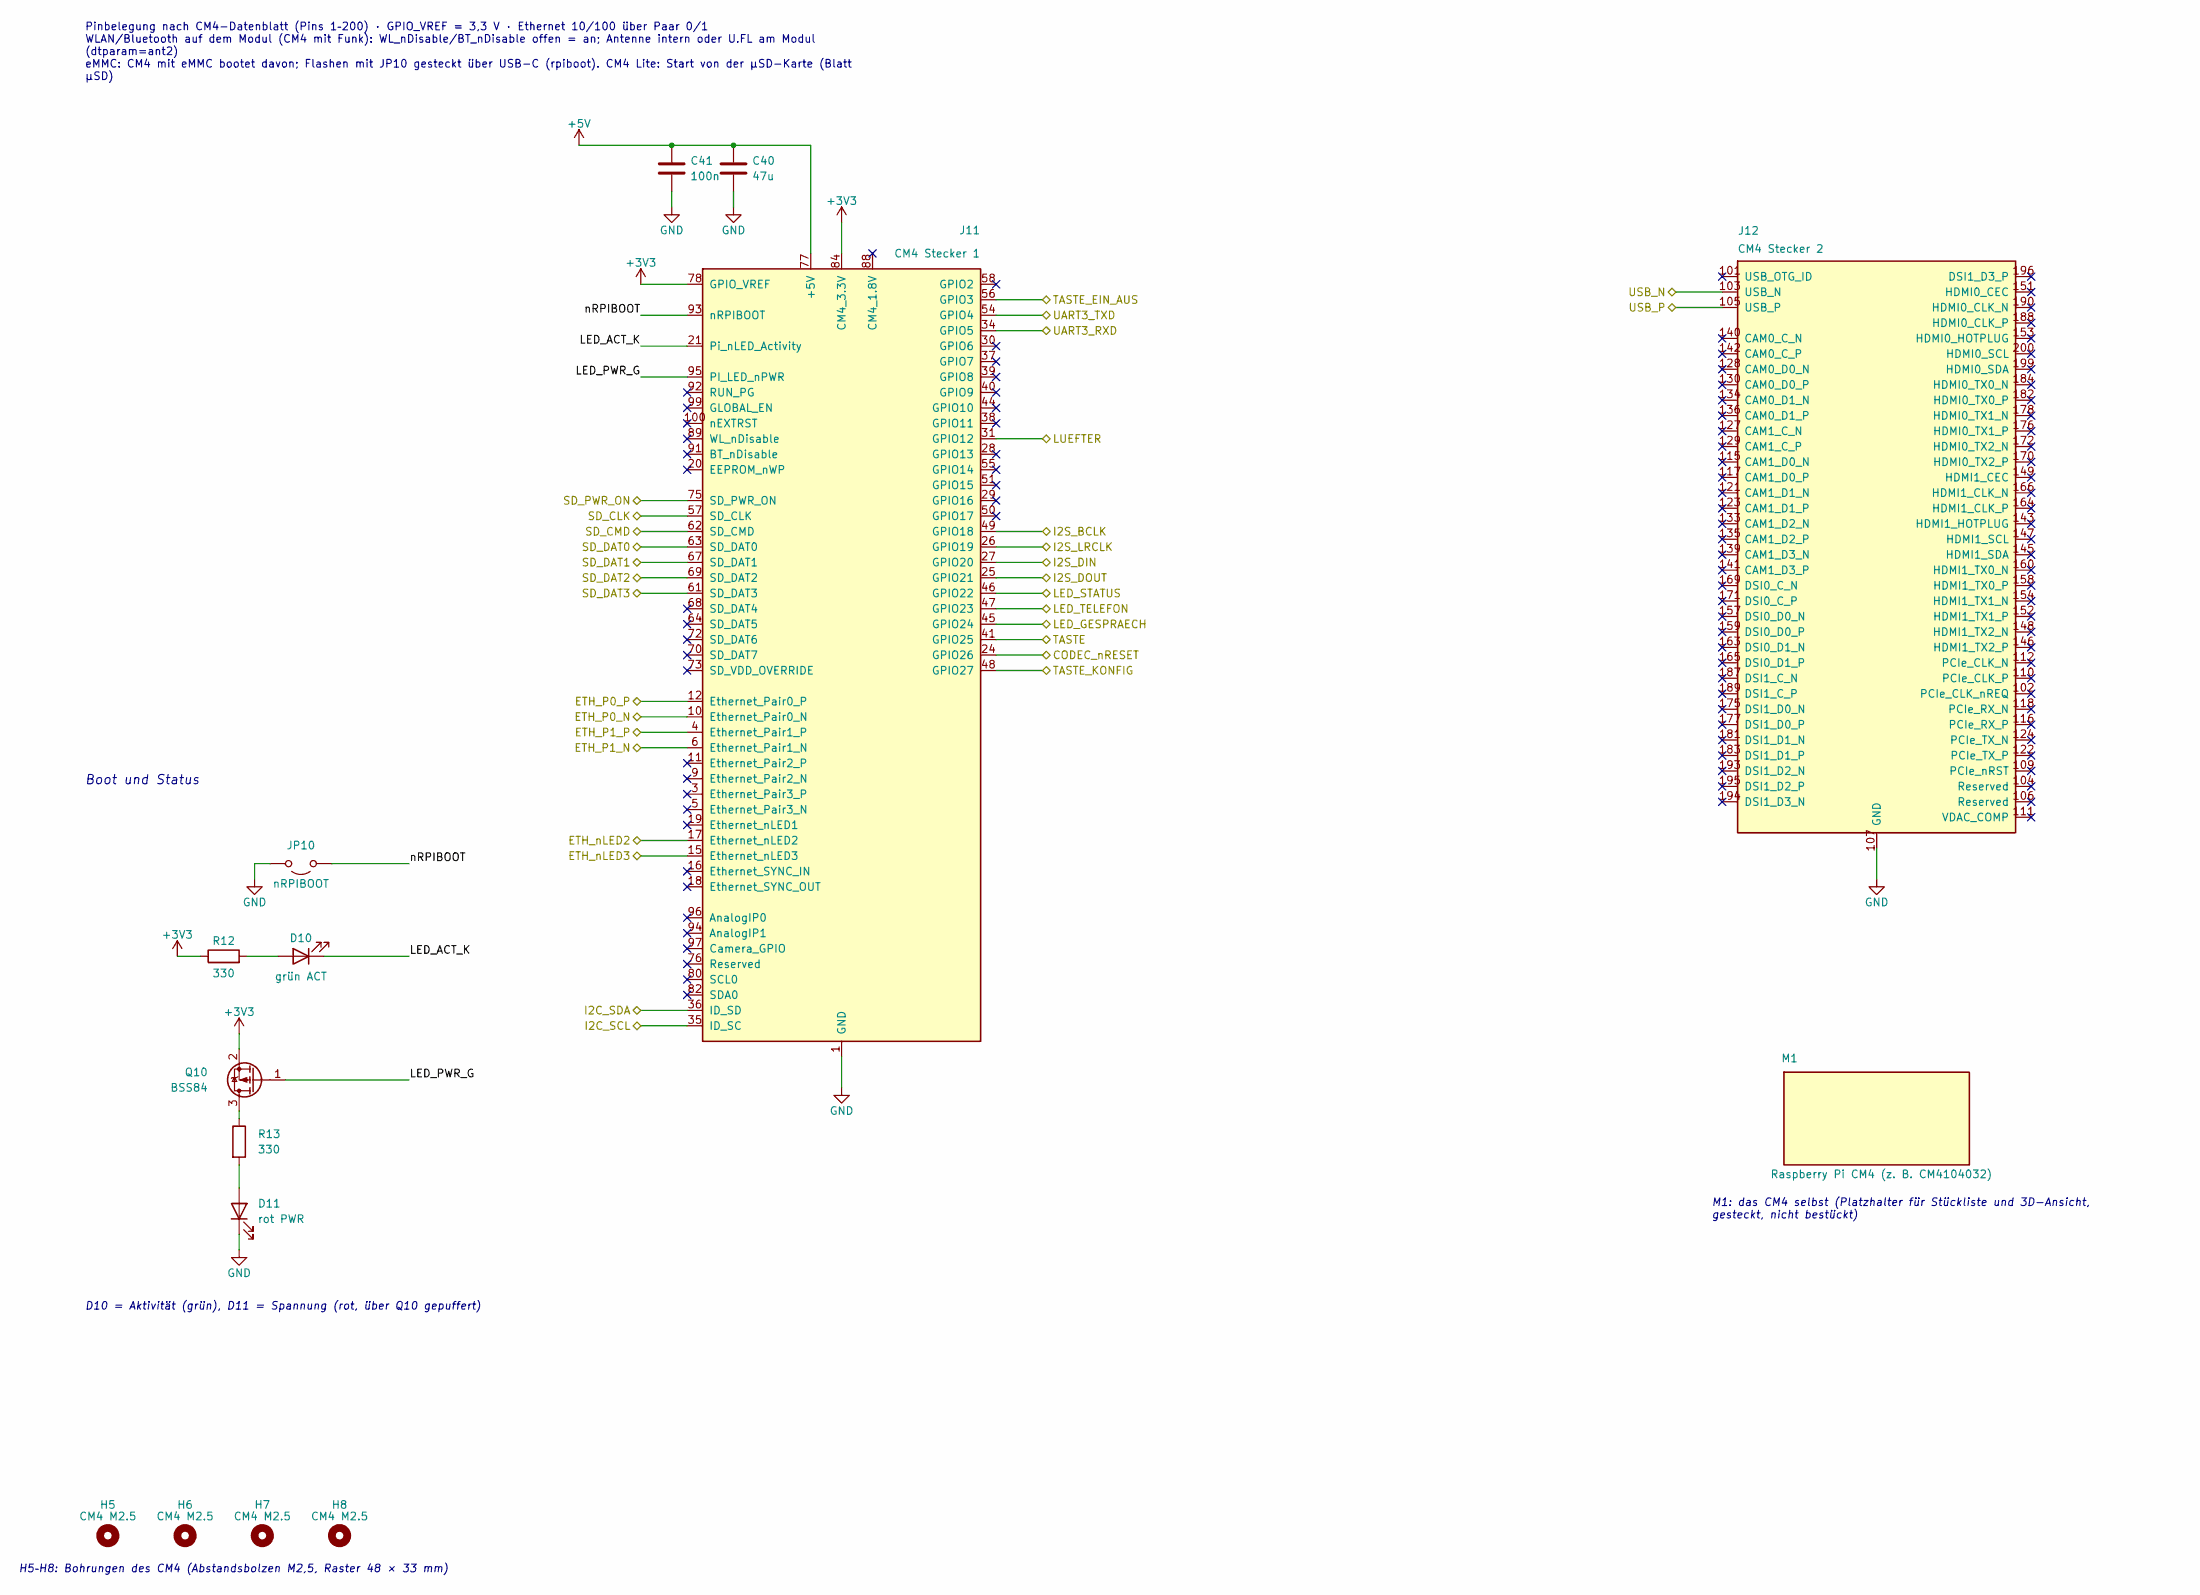
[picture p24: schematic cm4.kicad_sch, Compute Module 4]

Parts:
C40: 47u; C_1206_3216Metric
C41: 100n; C_0603_1608Metric
D10: grün ACT; LED_0603_1608Metric
D11: rot PWR; LED_0603_1608Metric
H5, H6, H7, H8: CM4 M2.5; MountingHole_2.7mm_M2.5
J11: CM4 Stecker 1; Hirose_DF40C-100DS-0.4V_2x50_P0.4mm
J12: CM4 Stecker 2; Hirose_DF40C-100DS-0.4V_2x50_P0.4mm_Pins101-200
JP10: nRPIBOOT; PinHeader_1x02_P2.54mm_Vertical
M1: Raspberry Pi CM4 (z. B. CM4104032); CM4_Modul_Platzhalter
Q10: BSS84; SOT-23
R12, R13: 330; R_0603_1608Metric

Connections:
+3V3: J11.78 (GPIO_VREF), J11.84 (CM4_3.3V), J11.86 (CM4_3.3V), Q10.2 (S), R12.1; also elsewhere on the board
+5V: C40.1, C41.1, J11.77 (+5V), J11.79 (+5V), J11.81 (+5V), J11.83 (+5V), J11.85 (+5V), J11.87 (+5V); also elsewhere on the board
/Audio-Codec/CODEC_nRESET: J11.24 (GPIO26); also elsewhere on the board
/Audio-Codec/I2C_SCL: J11.35 (ID_SC); also elsewhere on the board
/Audio-Codec/I2C_SDA: J11.36 (ID_SD); also elsewhere on the board
/Audio-Codec/I2S_BCLK: J11.49 (GPIO18); also elsewhere on the board
/Audio-Codec/I2S_DIN: J11.27 (GPIO20); also elsewhere on the board
/Audio-Codec/I2S_DOUT: J11.25 (GPIO21); also elsewhere on the board
/Audio-Codec/I2S_LRCLK: J11.26 (GPIO19); also elsewhere on the board
/Bedienung/LED_GESPRAECH: J11.45 (GPIO24); also elsewhere on the board
/Bedienung/LED_STATUS: J11.46 (GPIO22); also elsewhere on the board
/Bedienung/LED_TELEFON: J11.47 (GPIO23); also elsewhere on the board
/Bedienung/TASTE: J11.41 (GPIO25); also elsewhere on the board
/Bedienung/TASTE_EIN_AUS: J11.56 (GPIO3); also elsewhere on the board
/Bedienung/TASTE_KONFIG: J11.48 (GPIO27); also elsewhere on the board
/CM4/ETH_P0_N: J11.10 (Ethernet_Pair0_N); also elsewhere on the board
/CM4/ETH_P0_P: J11.12 (Ethernet_Pair0_P); also elsewhere on the board
/CM4/ETH_P1_N: J11.6 (Ethernet_Pair1_N); also elsewhere on the board
/CM4/ETH_P1_P: J11.4 (Ethernet_Pair1_P); also elsewhere on the board
/CM4/ETH_nLED2: J11.17 (Ethernet_nLED2); also elsewhere on the board
/CM4/ETH_nLED3: J11.15 (Ethernet_nLED3); also elsewhere on the board
/CM4/LED_ACT_K: D10.1 (K), J11.21 (Pi_nLED_Activity)
/CM4/LED_PWR_G: J11.95 (PI_LED_nPWR), Q10.1 (G)
/CM4/LUEFTER: J11.31 (GPIO12); also elsewhere on the board
/CM4/SD_CLK: J11.57 (SD_CLK); also elsewhere on the board
/CM4/SD_CMD: J11.62 (SD_CMD); also elsewhere on the board
/CM4/SD_DAT0: J11.63 (SD_DAT0); also elsewhere on the board
/CM4/SD_DAT1: J11.67 (SD_DAT1); also elsewhere on the board
/CM4/SD_DAT2: J11.69 (SD_DAT2); also elsewhere on the board
/CM4/SD_DAT3: J11.61 (SD_DAT3); also elsewhere on the board
/CM4/SD_PWR_ON: J11.75 (SD_PWR_ON); also elsewhere on the board
/CM4/UART3_RXD: J11.34 (GPIO5); also elsewhere on the board
/CM4/UART3_TXD: J11.54 (GPIO4); also elsewhere on the board
/CM4/USB_N: J12.103 (USB_N); also elsewhere on the board
/CM4/USB_P: J12.105 (USB_P); also elsewhere on the board
/CM4/nRPIBOOT: J11.93 (nRPIBOOT), JP10.1 (A)
GND: C40.2, C41.2, D11.1 (K), J11.1 (GND), J11.2 (GND), J11.7 (GND), J11.8 (GND), J11.13 (GND), J11.14 (GND), J11.22 (GND), J11.23 (GND), J11.32 (GND), J11.33 (GND), J11.42 (GND), J11.43 (GND), J11.52 (GND), J11.53 (GND), J11.59 (GND), J11.60 (GND), J11.65 (GND), J11.66 (GND), J11.71 (GND), J11.74 (GND), J11.98 (GND), J12.107 (GND), J12.108 (GND), J12.113 (GND), J12.114 (GND), J12.119 (GND), J12.120 (GND), J12.125 (GND), J12.126 (GND), J12.131 (GND), J12.132 (GND), J12.137 (GND), J12.138 (GND), J12.144 (GND), J12.150 (GND), J12.155 (GND), J12.156 (GND), J12.161 (GND), J12.162 (GND), J12.167 (GND), J12.168 (GND), J12.173 (GND), J12.174 (GND), J12.179 (GND), J12.180 (GND), J12.185 (GND), J12.186 (GND), J12.191 (GND), J12.192 (GND), J12.197 (GND), J12.198 (GND), JP10.2 (B); also elsewhere on the board
unnamed: D10.2 (A), R12.2
unnamed: D11.2 (A), R13.2
unnamed: Q10.3 (D), R13.1

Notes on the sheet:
Boot und Status
D10 = Aktivität (grün), D11 = Spannung (rot, über Q10 gepuffert)
H5–H8: Bohrungen des CM4 (Abstandsbolzen M2,5, Raster 48 × 33 mm)
M1: das CM4 selbst (Platzhalter für Stückliste und 3D-Ansicht, gesteckt, nicht bestückt)
Pinbelegung nach CM4-Datenblatt (Pins 1–200) · GPIO_VREF = 3,3 V · Ethernet 10/100 über Paar 0/1 WLAN/Bluetooth auf dem Modul (CM4 mit Funk): WL_nDisable/BT_nDisable offen = an; Antenne intern oder U.FL am Modul (dtparam=ant2) eMMC: CM4 mit eMMC bootet davon; Flashen mit JP10 gesteckt über USB-C (r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

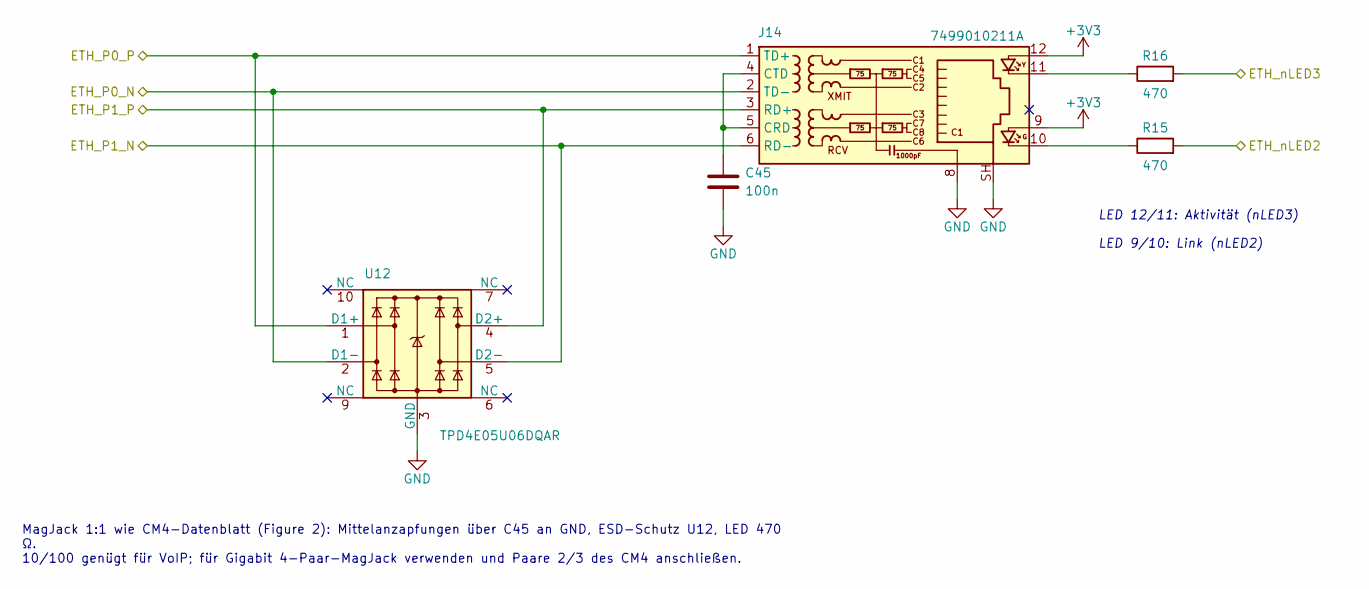
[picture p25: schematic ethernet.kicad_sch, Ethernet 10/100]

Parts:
C45: 100n; C_0603_1608Metric
J14: 7499010211A; RJ45_Wuerth_7499010211A_Horizontal
R15, R16: 470; R_0603_1608Metric
U12: TPD4E05U06DQAR; USON-10_2.5x1.0mm_P0.5mm

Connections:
+3V3: J14.9, J14.12; also elsewhere on the board
/CM4/ETH_P0_N: J14.2 (TD-), U12.2 (D1-); also elsewhere on the board
/CM4/ETH_P0_P: J14.1 (TD+), U12.1 (D1+); also elsewhere on the board
/CM4/ETH_P1_N: J14.6 (RD-), U12.5 (D2-); also elsewhere on the board
/CM4/ETH_P1_P: J14.3 (RD+), U12.4 (D2+); also elsewhere on the board
/CM4/ETH_nLED2: R15.2; also elsewhere on the board
/CM4/ETH_nLED3: R16.2; also elsewhere on the board
GND: C45.2, J14.8, J14.SH, U12.3 (GND), U12.8 (GND); also elsewhere on the board
unnamed: C45.1, J14.4 (CTD), J14.5 (CRD)
unnamed: J14.10, R15.1
unnamed: J14.11, R16.1

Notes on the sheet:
LED 12/11: Aktivität (nLED3)
LED 9/10: Link (nLED2)
MagJack 1:1 wie CM4-Datenblatt (Figure 2): Mittelanzapfungen über C45 an GND, ESD-Schutz U12, LED 470 Ω. 10/100 genügt für VoIP; für Gigabit 4-Paar-MagJack verwenden und Paare 2/3 des CM4 anschließen.

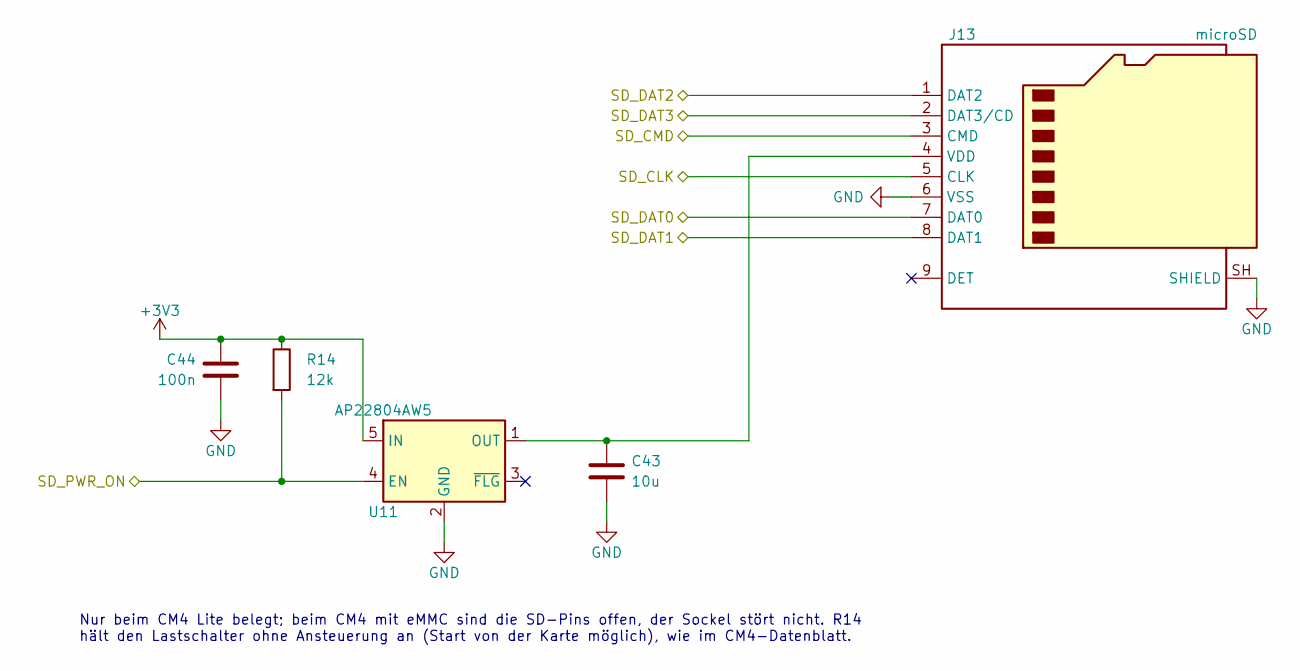
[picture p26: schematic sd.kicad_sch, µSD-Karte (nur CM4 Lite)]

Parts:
C43: 10u; C_0805_2012Metric
C44: 100n; C_0603_1608Metric
J13: microSD; microSD_HC_Hirose_DM3AT-SF-PEJM5
R14: 12k; R_0603_1608Metric
U11: AP22804AW5; SOT-23-5

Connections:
+3V3: C44.1, R14.1, U11.5 (IN); also elsewhere on the board
/CM4/SD_CLK: J13.5 (CLK); also elsewhere on the board
/CM4/SD_CMD: J13.3 (CMD); also elsewhere on the board
/CM4/SD_DAT0: J13.7 (DAT0); also elsewhere on the board
/CM4/SD_DAT1: J13.8 (DAT1); also elsewhere on the board
/CM4/SD_DAT2: J13.1 (DAT2); also elsewhere on the board
/CM4/SD_DAT3: J13.2 (DAT3/CD); also elsewhere on the board
/CM4/SD_PWR_ON: R14.2, U11.4 (EN); also elsewhere on the board
GND: C43.2, C44.2, J13.6 (VSS), J13.SH (SHIELD), U11.2 (GND); also elsewhere on the board
unnamed: C43.1, J13.4 (VDD), U11.1 (OUT)

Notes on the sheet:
Nur beim CM4 Lite belegt; beim CM4 mit eMMC sind die SD-Pins offen, der Sockel stört nicht. R14 hält den Lastschalter ohne Ansteuerung an (Start von der Karte möglich), wie im CM4-Datenblatt.

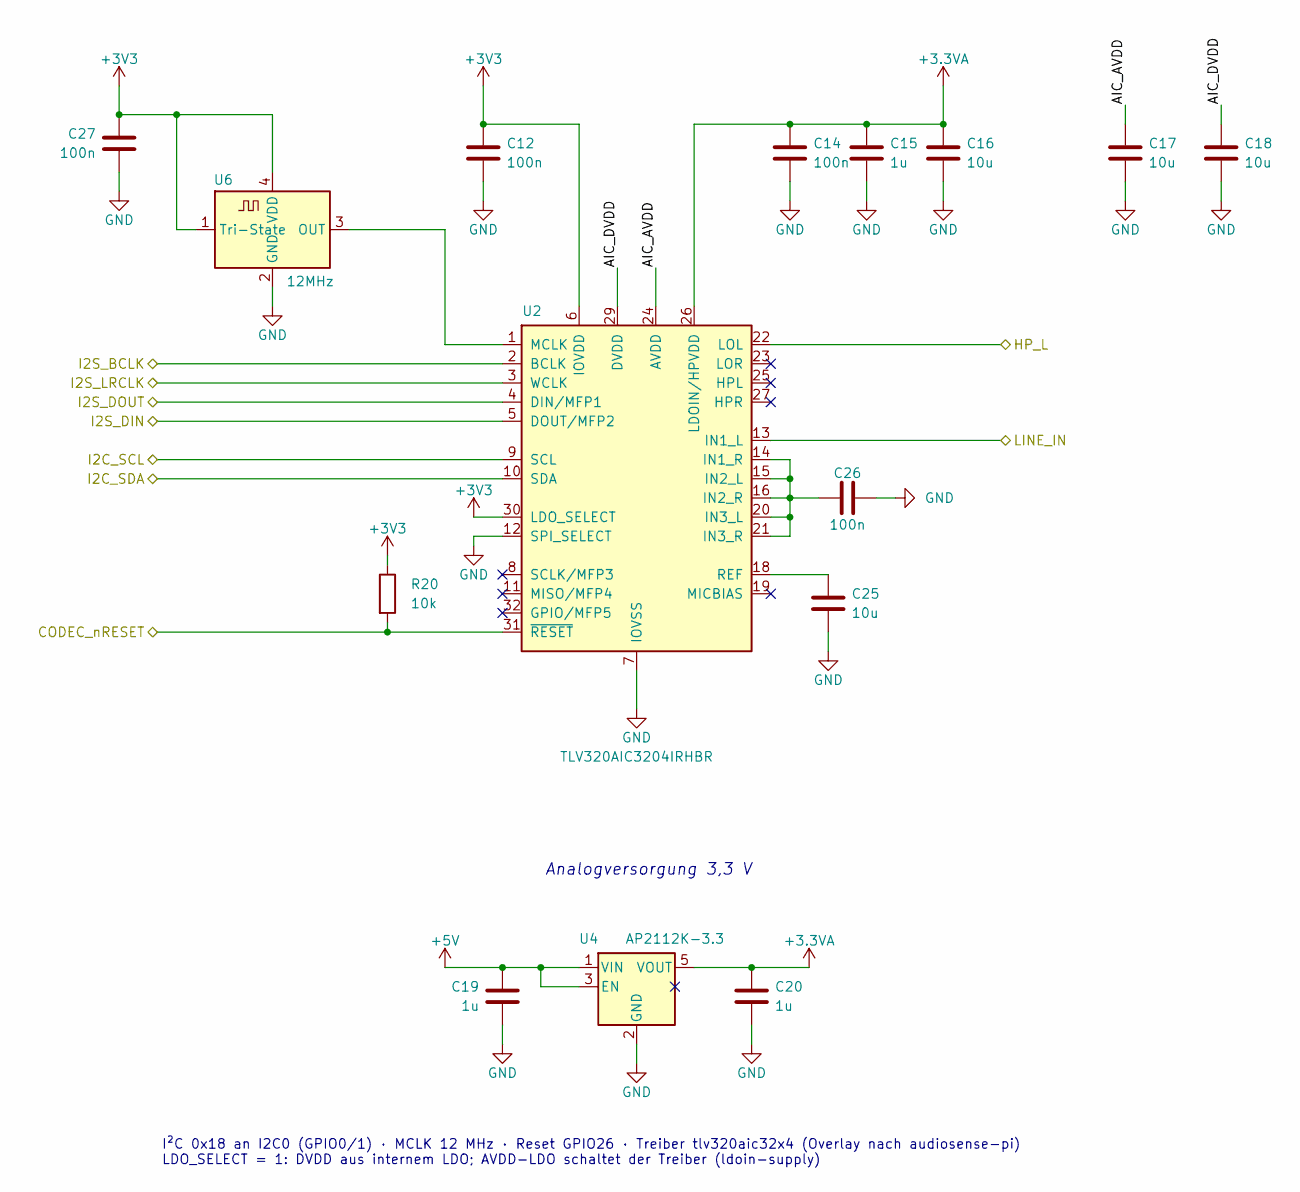
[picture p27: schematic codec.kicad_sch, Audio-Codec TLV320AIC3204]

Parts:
C12, C14, C26, C27: 100n; C_0603_1608Metric
C15, C19, C20: 1u; C_0603_1608Metric
C16, C17, C18, C25: 10u; C_0805_2012Metric
R20: 10k; R_0603_1608Metric
U2: TLV320AIC3204IRHBR; Texas_RHB0032E_VQFN-32-1EP_5x5mm_P0.5mm_EP3.45x3.45mm_Therm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
U4: AP2112K-3.3; SOT-23-5
U6: 12MHz; Oscillator_SMD_ECS_2520MV-xxx-xx-4Pin_2.5x2.0mm

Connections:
+3.3VA: C14.1, C15.1, C16.1, C20.1, U2.26 (LDOIN/HPVDD), U4.5 (VOUT)
+3V3: C12.1, C27.1, R20.1, U2.6 (IOVDD), U2.30 (LDO_SELECT), U6.1 (Tri-State), U6.4 (VDD); also elsewhere on the board
+5V: C19.1, U4.1 (VIN), U4.3 (EN); also elsewhere on the board
/Audio-Codec/AIC_AVDD: C17.1, U2.24 (AVDD)
/Audio-Codec/AIC_DVDD: C18.1, U2.29 (DVDD)
/Audio-Codec/CODEC_nRESET: R20.2, U2.31 (~RESET); also elsewhere on the board
/Audio-Codec/HP_L: U2.22 (LOL); also elsewhere on the board
/Audio-Codec/I2C_SCL: U2.9 (SCL); also elsewhere on the board
/Audio-Codec/I2C_SDA: U2.10 (SDA); also elsewhere on the board
/Audio-Codec/I2S_BCLK: U2.2 (BCLK); also elsewhere on the board
/Audio-Codec/I2S_DIN: U2.5 (DOUT/MFP2); also elsewhere on the board
/Audio-Codec/I2S_DOUT: U2.4 (DIN/MFP1); also elsewhere on the board
/Audio-Codec/I2S_LRCLK: U2.3 (WCLK); also elsewhere on the board
/Audio-Codec/LINE_IN: U2.13 (IN1_L); also elsewhere on the board
GND: C12.2, C14.2, C15.2, C16.2, C17.2, C18.2, C19.2, C20.2, C25.2, C26.2, C27.2, U2.7 (IOVSS), U2.12 (SPI_SELECT), U2.17 (AVSS), U2.28 (DVSS), U2.33 (EP), U4.2 (GND), U6.2 (GND); also elsewhere on the board
unnamed: C26.1, U2.14 (IN1_R), U2.15 (IN2_L), U2.16 (IN2_R), U2.20 (IN3_L), U2.21 (IN3_R)
unnamed: U2.1 (MCLK), U6.3 (OUT)
unnamed: C25.1, U2.18 (REF)

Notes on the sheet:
Analogversorgung 3,3 V
I²C 0x18 an I2C0 (GPIO0/1) · MCLK 12 MHz · Reset GPIO26 · Treiber tlv320aic32x4 (Overlay nach audiosense-pi) LDO_SELECT = 1: DVDD aus internem LDO; AVDD-LDO schaltet der Treiber (ldoin-supply)

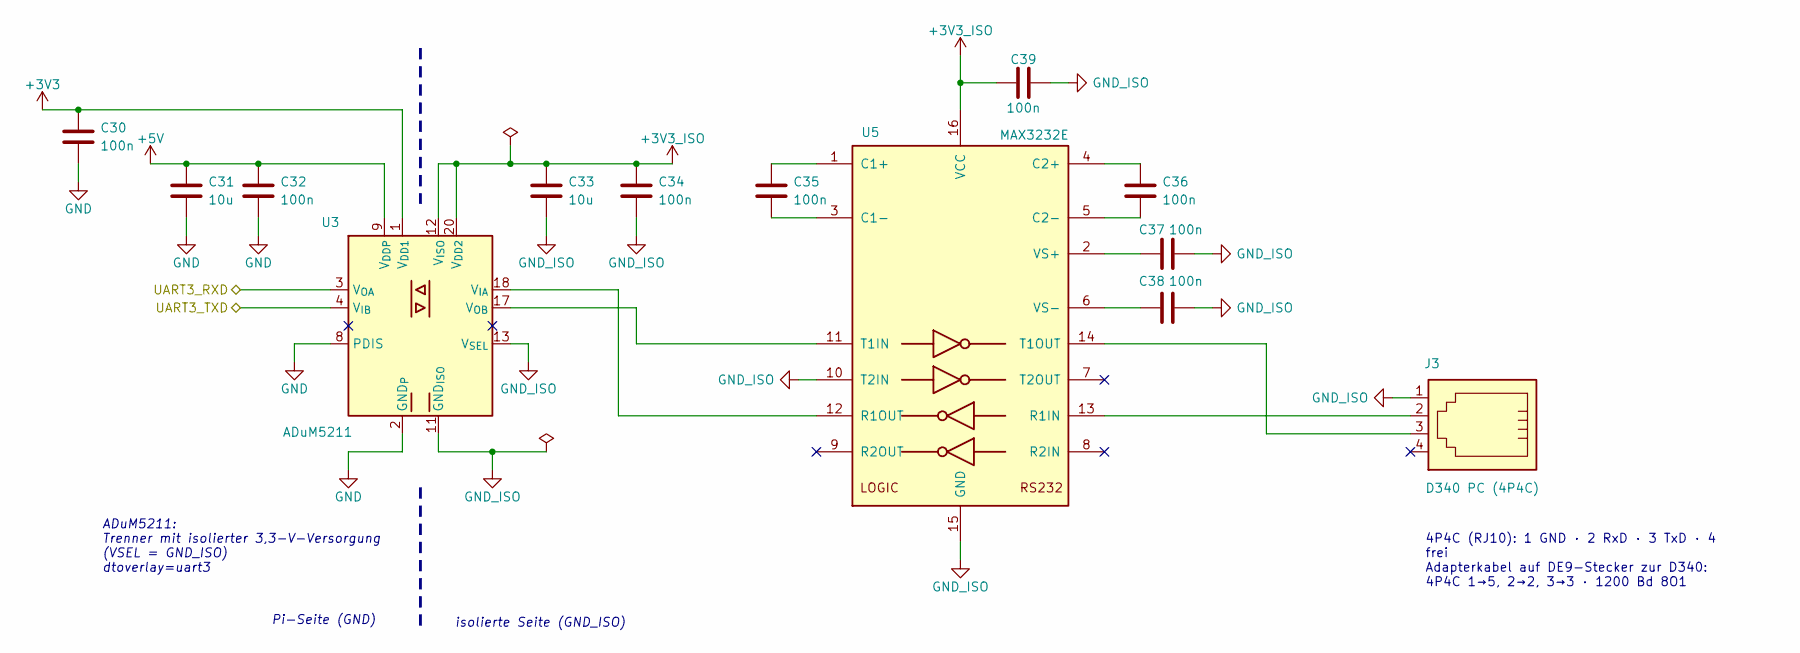
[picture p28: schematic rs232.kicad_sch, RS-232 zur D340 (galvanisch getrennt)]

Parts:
C30, C32, C34, C35, C36, C37, C38, C39: 100n; C_0603_1608Metric
C31, C33: 10u; C_0805_2012Metric
J3: D340 PC (4P4C); RJ10_Wuerth_615004143821_Horizontal
U3: ADuM5211; SSOP-20_5.3x7.2mm_P0.65mm
U5: MAX3232E; SOIC-16_3.9x9.9mm_P1.27mm

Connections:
+3V3: C30.1, U3.1 (V_{DD1}); also elsewhere on the board
+3V3_ISO: C33.1, C34.1, C39.1, U3.12 (V_{ISO}), U3.20 (V_{DD2}), U5.16 (VCC)
+5V: C31.1, C32.1, U3.9 (V_{DDP}); also elsewhere on the board
/CM4/UART3_RXD: U3.3 (V_{OA}); also elsewhere on the board
/CM4/UART3_TXD: U3.4 (V_{IB}); also elsewhere on the board
GND: C30.2, C31.2, C32.2, U3.2 (GND_{P}), U3.5 (GND_{P}), U3.6 (GND_{P}), U3.8 (PDIS), U3.10 (GND_{P}); also elsewhere on the board
GND_ISO: C33.2, C34.2, C37.2, C38.2, C39.2, J3.1, U3.11 (GND_{ISO}), U3.13 (V_{SEL}), U3.15 (GND_{ISO}), U3.16 (GND_{ISO}), U3.19 (GND_{ISO}), U5.10 (T2IN), U5.15 (GND)
unnamed: U3.18 (V_{IA}), U5.12 (R1OUT)
unnamed: U3.17 (V_{OB}), U5.11 (T1IN)
unnamed: C35.1, U5.1 (C1+)
unnamed: C35.2, U5.3 (C1-)
unnamed: C36.1, U5.4 (C2+)
unnamed: C36.2, U5.5 (C2-)
unnamed: J3.2, U5.13 (R1IN)
unnamed: J3.3, U5.14 (T1OUT)
unnamed: C37.1, U5.2 (VS+)
unnamed: C38.1, U5.6 (VS-)

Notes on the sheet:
Pi-Seite (GND)
isolierte Seite (GND_ISO)
ADuM5211: Trenner mit isolierter 3,3-V-Versorgung (VSEL = GND_ISO) dtoverlay=uart3
4P4C (RJ10): 1 GND · 2 RxD · 3 TxD · 4 frei Adapterkabel auf DE9-Stecker zur D340: 4P4C 1→5, 2→2, 3→3 · 1200 Bd 8O1

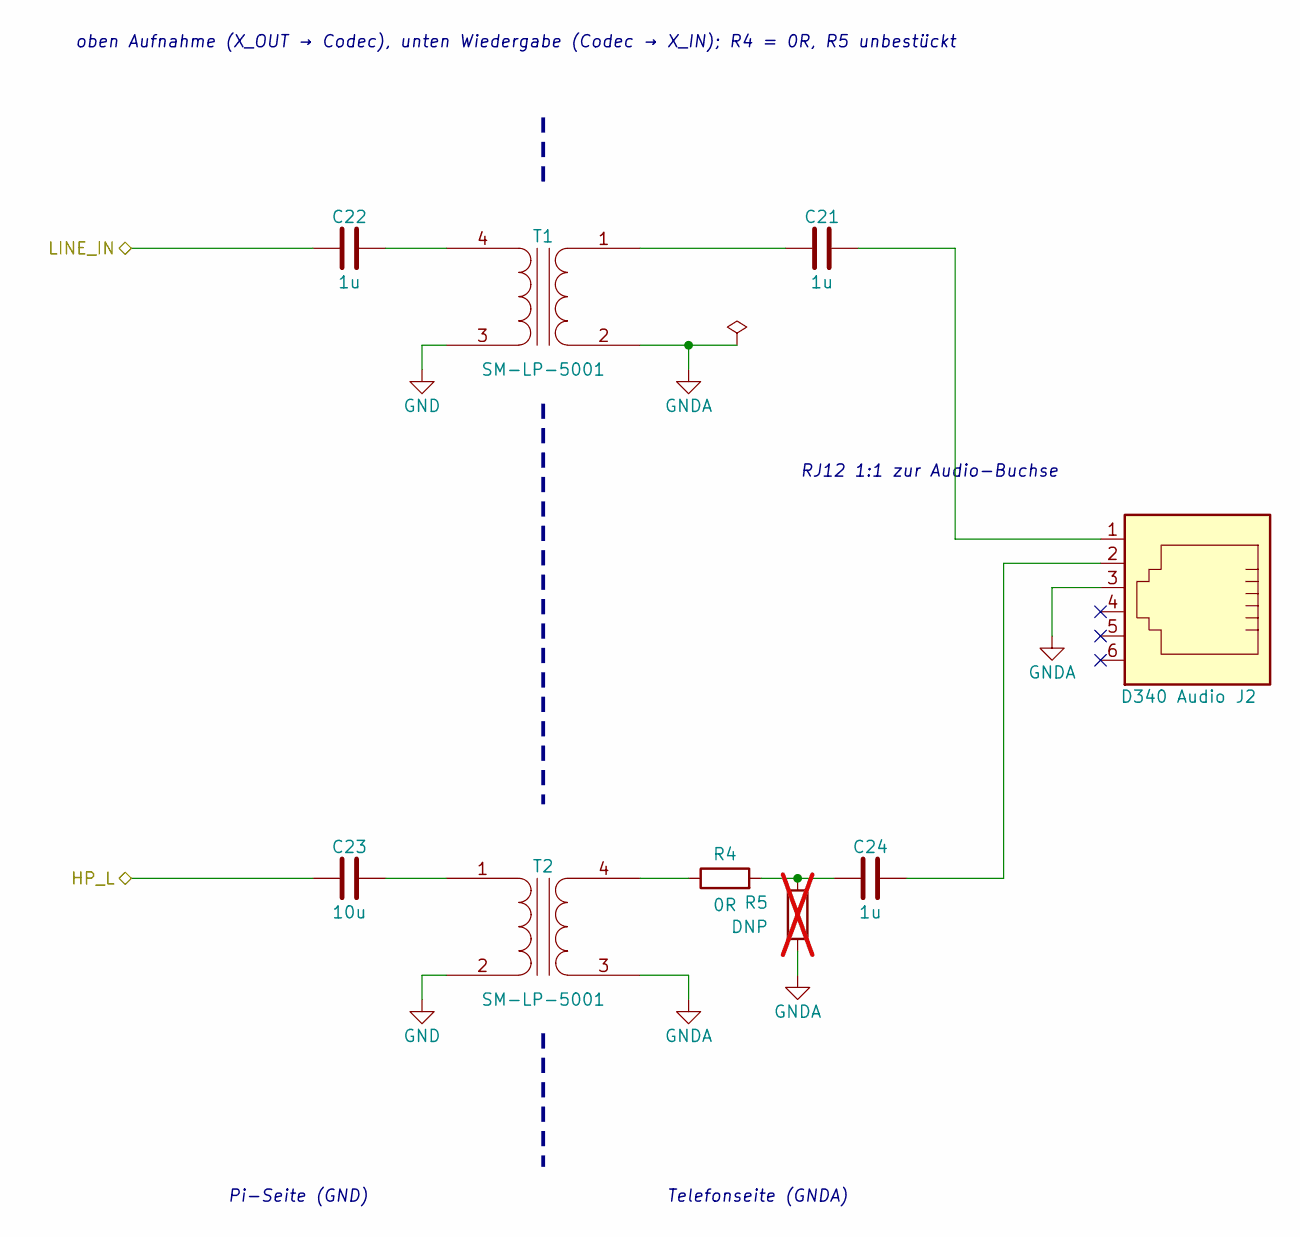
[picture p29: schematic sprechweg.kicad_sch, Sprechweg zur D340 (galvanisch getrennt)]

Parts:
C21, C24: 1u; C_0805_2012Metric
C22: 1u; C_0603_1608Metric
C23: 10u; C_0805_2012Metric
J2: D340 Audio; RJ12_Wuerth_615006138421_Horizontal
R4: 0R; R_0603_1608Metric
R5: DNP; R_0603_1608Metric; not fitted
T1, T2: SM-LP-5001; Bourns_SM-LP-5001

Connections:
/Audio-Codec/HP_L: C23.1; also elsewhere on the board
/Audio-Codec/LINE_IN: C22.2; also elsewhere on the board
GND: T1.3 (SA), T2.2 (AB); also elsewhere on the board
GNDA: J2.3, R5.2, T1.2 (AB), T2.3 (SA)
unnamed: C21.1, J2.1
unnamed: C24.1, R4.2, R5.1
unnamed: C24.2, J2.2
unnamed: C21.2, T1.1 (AA)
unnamed: C22.1, T1.4 (SB)
unnamed: C23.2, T2.1 (AA)
unnamed: R4.1, T2.4 (SB)

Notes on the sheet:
Pi-Seite (GND)
Telefonseite (GNDA)
oben Aufnahme (X_OUT → Codec), unten Wiedergabe (Codec → X_IN); R4 = 0R, R5 unbestückt
RJ12 1:1 zur Audio-Buchse

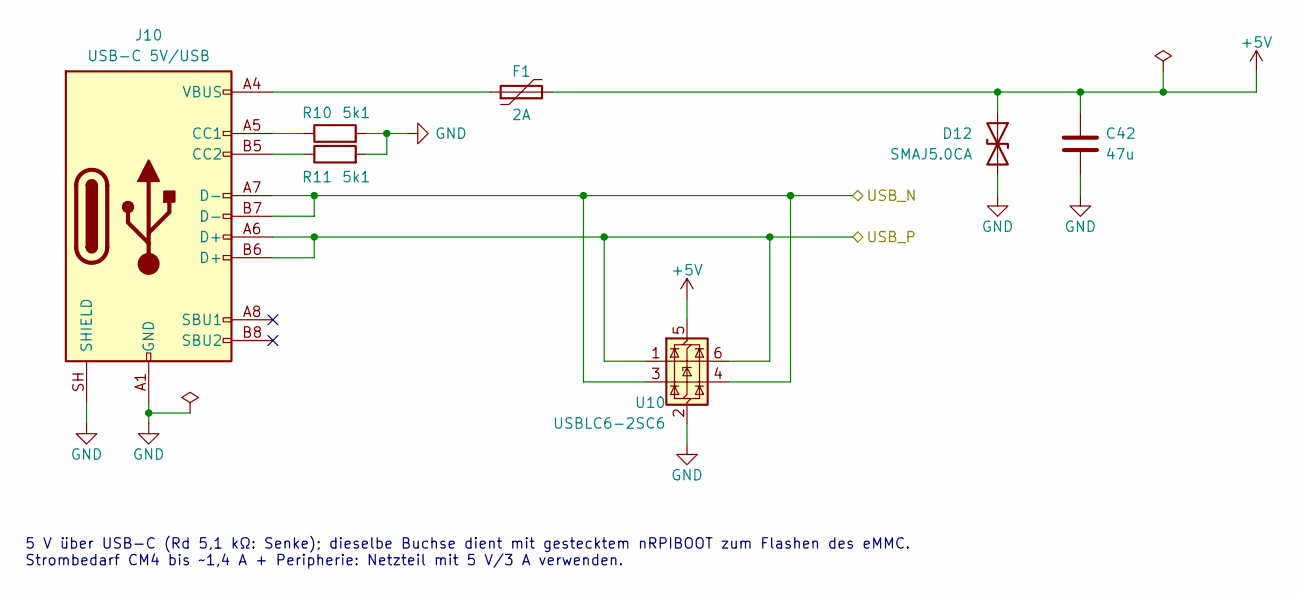
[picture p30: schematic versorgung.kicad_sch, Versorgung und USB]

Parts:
C42: 47u; C_1206_3216Metric
D12: SMAJ5.0CA; D_SMA
F1: 2A; Fuse_1812_4532Metric
J10: USB-C 5V/USB; USB_C_Receptacle_GCT_USB4105-xx-A_16P_TopMnt_Horizontal
R10, R11: 5k1; R_0603_1608Metric
U10: USBLC6-2SC6; SOT-23-6

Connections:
+5V: C42.1, D12.1 (A1), F1.2, U10.5 (VBUS); also elsewhere on the board
/CM4/USB_N: J10.A7 (D-), J10.B7 (D-), U10.3 (I/O2), U10.4 (I/O2); also elsewhere on the board
/CM4/USB_P: J10.A6 (D+), J10.B6 (D+), U10.1 (I/O1), U10.6 (I/O1); also elsewhere on the board
GND: C42.2, D12.2 (A2), J10.A1 (GND), J10.A12 (GND), J10.B1 (GND), J10.B12 (GND), J10.SH (SHIELD), R10.2, R11.2, U10.2 (GND); also elsewhere on the board
unnamed: F1.1, J10.A4 (VBUS), J10.A9 (VBUS), J10.B4 (VBUS), J10.B9 (VBUS)
unnamed: J10.A5 (CC1), R10.1
unnamed: J10.B5 (CC2), R11.1

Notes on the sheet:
5 V über USB-C (Rd 5,1 kΩ: Senke); dieselbe Buchse dient mit gestecktem nRPIBOOT zum Flashen des eMMC. Strombedarf CM4 bis ~1,4 A + Peripherie: Netzteil mit 5 V/3 A verwenden.

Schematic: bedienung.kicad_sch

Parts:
D1: grün; LED_0603_1608Metric
D2: gelb; LED_0603_1608Metric
D3: blau; LED_0603_1608Metric
H1, H2, H3, H4: M2.5; MountingHole_2.7mm_M2.5
R6, R7, R8: 330; R_0603_1608Metric
R9: DNP; R_0603_1608Metric; not fitted
SW1: Taste; SW_SPST_TL3342
SW2: Konfig; SW_SPST_TL3342
SW3: Ein/Aus; SW_SPST_TL3342

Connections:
+3V3: R9.1; also elsewhere on the board
/Bedienung/LED_GESPRAECH: R7.1; also elsewhere on the board
/Bedienung/LED_STATUS: R8.1; also elsewhere on the board
/Bedienung/LED_TELEFON: R6.1; also elsewhere on the board
/Bedienung/TASTE: SW1.1; also elsewhere on the board
/Bedienung/TASTE_EIN_AUS: R9.2, SW3.1; also elsewhere on the board
/Bedienung/TASTE_KONFIG: SW2.1; also elsewhere on the board
GND: D1.1 (K), D2.1 (K), D3.1 (K), SW1.2, SW2.2, SW3.2; also elsewhere on the board
unnamed: D1.2 (A), R6.2
unnamed: D2.2 (A), R7.2
unnamed: D3.2 (A), R8.2

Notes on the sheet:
D1: Telefon verbunden
D2: Gespräch
Annehmen/Auflegen
(Pull-up im Pi)
D3: Status/Konfiguration
Konfiguration (Pull-up im Pi)
H1–H4: Gehäusebefestigung M2,5 (Lage nach Gehäuse); CM4 auf 4 Abstandsbolzen M2,5
Ein/Aus (GPIO3): Druck im Betrieb = sauber herunterfahren (dtoverlay=gpio-shutdown), Druck im Halt = starten (Bootloader WAKE_ON_GPIO=1). R9 nur bestücken, falls nötig.

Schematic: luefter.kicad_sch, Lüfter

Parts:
C46: 10u; C_0805_2012Metric
D13: MBR140SFT1G; D_SOD-123F
J15: Lüfter 5 V; JST_PH_B2B-PH-K_1x02_P2.00mm_Vertical
Q11: AO3400A; SOT-23
R17: 100; R_0603_1608Metric
R18: 100k; R_0603_1608Metric

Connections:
+5V: C46.1, D13.1 (K), J15.1; also elsewhere on the board
/CM4/LUEFTER: R17.1; also elsewhere on the board
GND: C46.2, Q11.2 (S), R18.2; also elsewhere on the board
unnamed: D13.2 (A), J15.2, Q11.3 (D)
unnamed: Q11.1 (G), R17.2, R18.1

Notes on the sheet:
Steuerung über die SoC-Temperatur: dtoverlay=gpio-fan,gpiopin=12,temp=60000 (Hysterese im Treiber). GPIO12 kann auch PWM (PWM0) für Drehzahlregelung. J15 JST PH 2,0 mm: 1 = +5 V, 2 = Lüfter −

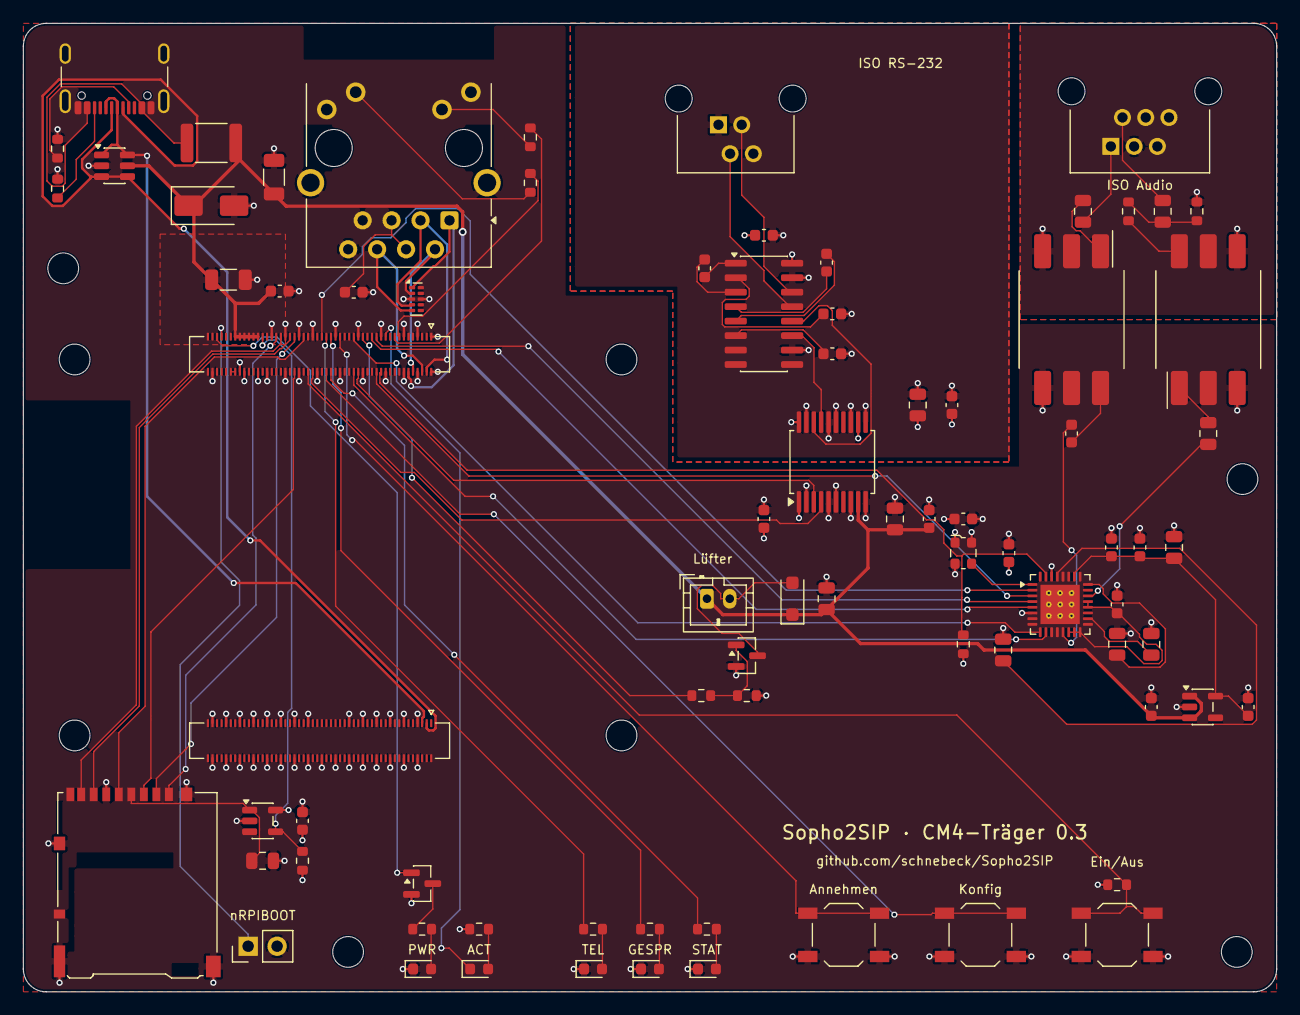
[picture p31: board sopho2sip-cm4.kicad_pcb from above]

Board: 4 copper layers, 110.0 x 85.0 mm, 89 parts (0 on the bottom side), 80 nets.

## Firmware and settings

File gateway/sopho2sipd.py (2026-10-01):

#!/usr/bin/env python3
# SPDX-License-Identifier: GPL-3.0-or-later
"""Sopho2SIP-Daemon: hält die Verbindung zur ErgoLine D340, führt den Zustandsautomaten, gibt für jeden beendeten
Anruf einen Anrufdatensatz aus (JSON-Zeile in eine Datei, optional HTTP-POST) und bedient das Webportal.

Betrieb:     gateway/sopho2sipd.py [--port …] [--anrufe DATEI] [--webhook URL] [--portal HOST:PORT]
                                   [--baresip HOST:PORT] [--steuerung]
Wiedergabe:  gateway/sopho2sipd.py --wiedergabe logs/serial_20260930_163534.log [--anrufe -]

Ohne --steuerung sendet der Daemon nur Anmelden und Keepalive; Wählen/Annehmen/Auflegen aus dem Portal sind
dann gesperrt. Die Datensätze enthalten echte Rufnummern: Standardziel ~/.local/share/sopho2sip/anrufe.jsonl.
"""
import argparse
import json
import pathlib
import queue
import sys
import threading
import time
import urllib.request

sys.path.insert(0, str(pathlib.Path(__file__).resolve().parent))
from ergoline import protocol as p  # noqa: E402
from ergoline.logdatei import rohdaten  # noqa: E402
from ergoline.zustand import AuftragNichtMoeglich, Telefon  # noqa: E402

STANDARD_ANRUFE = pathlib.Path.home() / ".local" / "share" / "sopho2sip" / "anrufe.jsonl"
KEEPALIVE_S = 15.0      # Watchdog der D340: nach 30 s ohne Rahmen vom PC legt sie PC-Gespräche auf


class Ausgabe:
    def __init__(self, datei: str, webhook: str | None, echo=print):
        self.datei, self.webhook, self.echo = datei, webhook, echo
        if datei != "-":
            pathlib.Path(datei).parent.mkdir(parents=True, exist_ok=True)

    def ereignis(self, name: str, anruf, zusatz) -> None:
        kennung = f"#{anruf.kennung}" if anruf else ""
        self.echo(f"  {name:12} {kennung:4} {zusatz if zusatz not in (None, '') else ''}")

    def datensatz(self, ds: dict) -> None:
        zeile = json.dumps(ds, ensure_ascii=False)
        if self.datei == "-":
            print(zeile, flush=True)
        else:
            with open(self.datei, "a", encoding="utf-8") as f:
                f.write(zeile + "\n")
        if self.webhook:
            try:
                req = urllib.request.Request(self.webhook, data=zeile.encode(), method="POST",
                                             headers={"Content-Type": "application/json"})
                urllib.request.urlopen(req, timeout=5).close()
            except OSError as e:
                self.echo(f"  Webhook fehlgeschlagen: {e}")


class Gateway:
    """Gemeinsamer Zustand von Empfangsschleife und Portal. Alle Zugriffe auf Telefon und Link unter self.lock."""

    def __init__(self, ausgabe: Ausgabe, amtsholung: str = p.AMTSHOLUNG, steuerung: bool = False):
        self.ausgabe, self.amtsholung, self.steuerung = ausgabe, amtsholung, steuerung
        self.lock = threading.RLock()
        self.telefon = Telefon(amtsholung)
        self.link = None
        self.zuhoerer: list = []            # f(name, anruf, zusatz), z. B. SipBruecke.bei_telefon
        self.sip = None                     # BaresipCtrl, falls --baresip
        self.rueckwaerts = None             # Rueckwaertssuche, falls --rueckwaertssuche
        self._pc_anruf = False              # Gespräch vom PC angenommen/gewählt → X-Eingang einschalten
        self._abos: list[queue.Queue] = []
        self._abo_lock = threading.Lock()

    # --- Ereignisse an Portal-Abonnenten -----------------------------------------------------------
    def abonniere(self) -> queue.Queue:
        q: queue.Queue = queue.Queue(maxsize=100)
        with self._abo_lock:
            self._abos.append(q)
        return q

    def abbestelle(self, q: queue.Queue) -> None:
        with self._abo_lock:
            if q in self._abos:
                self._abos.remove(q)

    def _sende_an_abos(self, typ: str, **daten) -> None:
        ev = {"typ": typ, "status": self.status(), **daten}
        with self._abo_lock:
            for q in self._abos:
                try:
                    q.put_nowait(ev)
                except queue.Full:
                    pass

    # --- Empfang ------------------------------------------------------------------------------------
    def verbindung(self, link) -> None:
        with self.lock:
            self.link = link
            self.telefon = Telefon(self.amtsholung)
        self._melde_zuhoerern("VERBINDUNG", None, link is not None)
        self._sende_an_abos("VERBINDUNG")

    def _melde_zuhoerern(self, name, anruf, zusatz) -> None:
        for f in self.zuhoerer:
            try:
                f(name, anruf, zusatz)
            except Exception as e:          # ein Fehler in der Brücke darf den Empfang nicht stoppen
                self.ausgabe.echo(f"  FEHLER       {f.__qualname__}: {e!r}")

    def verarbeite(self, r: p.Rahmen, zeit: float) -> None:
        with self.lock:
            ereignisse = self.telefon.verarbeite(r, zeit)
        for name, anruf, zusatz in ereignisse:
            if name == "ANRUF_ENDE":
                self.ausgabe.ereignis(name, anruf, f"{zusatz['richtung']} {zusatz['nummer'] or '–'} "
                                      f"{'angenommen ' + str(zusatz['dauer_s']) + ' s' if zusatz['angenommen'] else 'nicht angenommen'}")
                self.ausgabe.datensatz(zusatz)
            else:
                self.ausgabe.ereignis(name, anruf, zusatz)
            if name == "VERBUNDEN":
                self._x_eingang_einschalten()
            elif name == "ANRUF_ENDE":
                self._pc_anruf = False
            self._melde_zuhoerern(name, anruf, zusatz)
            self._sende_an_abos(name)
            if name in ("ANRUF_EIN", "WAHL") and self.rueckwaerts and anruf.nummer_roh and anruf.name is None:
                threading.Thread(target=self._rueckwaerts, args=(anruf,), daemon=True).start()

    def _x_eingang_einschalten(self) -> None:
        """Bei PC-geführten Gesprächen Sprache von X_IN statt der Mikrofone der D340 (Merkmal 4f).
        Gespräche am Hörer der D340 bleiben unberührt, sonst wäre dort das Mikrofon stumm."""
        with self.lock:
            if not (self._pc_anruf and self.steuerung and self.link) or self.telefon.x_eingang:
                return
            q = self.link.sende(p.x_eingang())
        self.ausgabe.echo(f"  AUFTRAG      X-Eingang statt Mikrofon: {q.beschreibung() if q else 'keine Quittung'}")

    def _rueckwaerts(self, anruf) -> None:
        ext, nummer = p.extern(anruf.nummer_roh, self.amtsholung)
        treffer = self.rueckwaerts.frage(nummer) if ext else None
        if not treffer:
            return
        with self.lock:
            anruf.name, anruf.ort = treffer["name"], treffer.get("ort")
        self.ausgabe.echo(f"  NAME         #{anruf.kennung} {treffer['name']} ({treffer.get('ort') or '–'}, {treffer['quelle']})")
        self._sende_an_abos("NAME")

    # --- Abfragen -----------------------------------------------------------------------------------
    def status(self) -> dict:
        with self.lock:
            return {"verbunden": self.link is not None, "bereit": self.telefon.bereit,
                    "hoerer_ab": self.telefon.hoerer_ab, "steuerung": self.steuerung,
                    "sip": None if self.sip is None else self.sip.verbunden,
                    "anruf": self.telefon.zustand_kurz(), "zeit": time.time()}

    def anrufliste(self, n: int = 200) -> list[dict]:
        if self.ausgabe.datei == "-":
            return []
        try:
            zeilen = pathlib.Path(self.ausgabe.datei).read_text(encoding="utf-8").splitlines()
        except FileNotFoundError:
            return []
        out = []
        for z in reversed(zeilen[-n:]):
            try:
                ds = json.loads(z)
            except json.JSONDecodeError:
                continue
            if not ds.get("name") and self.rueckwaerts and ds.get("extern"):
                treffer = self.rueckwaerts.bekannt(ds.get("nummer", ""))    # nur Zwischenspeicher, kein Netz
                if treffer:
                    ds["name"], ds["ort"] = treffer["name"], treffer.get("ort")
            out.append(ds)
        return out

    # --- Aufträge (Portal) --------------------------------------------------------------------------
    def auftrag(self, art: str, nummer: str = "") -> dict:
        if not self.steuerung:
            return {"ok": False, "fehler": "Steuerung gesperrt (Daemon ohne --steuerung gestartet)"}
        with self.lock:
            if self.link is None:
                return {"ok": False, "fehler": "keine Verbindung zum Telefon"}
            try:
                if art == "waehlen":
                    rahmen = self.telefon.auftraege_wahl_oder_ziffern(nummer)
                elif art == "annehmen":
                    rahmen = self.telefon.auftraege_annehmen()
                elif art == "auflegen":
                    rahmen = self.telefon.auftraege_auflegen()
                else:
                    return {"ok": False, "fehler": f"unbekannter Auftrag {art}"}
            except (AuftragNichtMoeglich, ValueError) as e:
                return {"ok": False, "fehler": str(e)}
            gesendet = []
            for r in rahmen:
                q = self.link.sende(r)
                gesendet.append(r.hex())
                if q is None or q.klasse != p.ACK:
                    return {"ok": False, "gesendet": gesendet,
                            "fehler": f"keine Quittung für {r.hex()}" if q is None else q.beschreibung()}
            # noch unter der Sperre: CONNECTED wird erst danach verarbeitet und findet die Markierung sicher vor
            if art == "annehmen" or (art == "waehlen" and gesendet[0] == p.belegen().hex()):
                self._pc_anruf = True
        self.ausgabe.echo(f"  AUFTRAG     {art} {' | '.join(gesendet)}")
        return {"ok": True, "gesendet": gesendet}


def wiedergabe(pfad: str, ausgabe: Ausgabe, amtsholung: str) -> int:
    gw, asm = Gateway(ausgabe, amtsholung), p.Assembler()
    for zeit, richtung, daten in rohdaten(pfad):
        if richtung != "<<":
            continue
        for r in asm.feed(daten):
            gw.verarbeite(r, zeit)
    return 0


def betrieb(a, gw: Gateway) -> int:
    from ergoline.link import PORT_STANDARD, ErgoLink
    import serial
    while True:
        try:
            with ErgoLink(a.port or PORT_STANDARD, echo=None) as link:
                gw.verbindung(link)
                with gw.lock:
                    q = link.sende(p.anmelden())
                print(f"Anmeldung: {q.beschreibung() if q else 'keine Quittung'}", flush=True)
                while True:
                    # Keepalive nach 15 s ohne SENDEN (nicht nur ohne Empfang wie im Treiber): meldet das Telefon
                    # laufend etwas, käme sonst nie ein Keepalive und der Watchdog (30 s) legt auf.
                    if time.time() - link.zuletzt_gesendet > KEEPALIVE_S:
                        with gw.lock:
                            q = link.sende(p.keepalive())
                        if q is None:
                            raise serial.SerialException("Keepalive ohne Quittung")
                    try:
                        zeit, r = link.rahmen.get(timeout=1.0)
                    except queue.Empty:
                        continue
                    gw.verarbeite(r, zeit)
        except (serial.SerialException, OSError) as e:
            gw.verbindung(None)
            print(f"Verbindung verloren ({e}); neuer Versuch in 5 s", flush=True)
            time.sleep(5)
        except KeyboardInterrupt:
            return 0


def main() -> int:
    ap = argparse.ArgumentParser(description=__doc__, formatter_class=argparse.RawDescriptionHelpFormatter)
    ap.add_argument("--port")
    ap.add_argument("--anrufe", default=str(STANDARD_ANRUFE), help="JSON-Zeilen-Datei für Anrufdatensätze, '-' = stdout")
    ap.add_argument("--webhook", help="URL, an die jeder Anrufdatensatz per HTTP-POST (JSON) geht")
    ap.add_argument("--amtsholung", default=p.AMTSHOLUNG)
    ap.add_argument("--portal", metavar="HOST:PORT", help="Webportal starten, z. B. 127.0.0.1:8080")
    ap.add_argument("--steuerung", action="store_true", help="Wählen/Annehmen/Auflegen (Portal, SIP) erlauben")
    ap.add_argument("--baresip", metavar="HOST:PORT", help="SIP-Brücke über baresip ctrl_tcp, z. B. 127.0.0.1:4444")
    ap.add_argument("--rueckwaertssuche", action="store_true",
                    help="Namen externer Anrufer online nachschlagen (11880, Das Örtliche; Nummern gehen an diese Dienste)")
    ap.add_argument("--wiedergabe", metavar="LOG", help="Mitschnitt statt Telefon verarbeiten")
    a = ap.parse_args()
    ausgabe = Ausgabe(a.anrufe, a.webhook, echo=lambda s: print(s, file=sys.stderr, flush=True))
    if a.wiedergabe:
        return wiedergabe(a.wiedergabe, ausgabe, a.amtsholung)
    gw = Gateway(ausgabe, a.amtsholung, a.steuerung)
    if a.rueckwaertssuche:
        from rueckwaerts import Rueckwaertssuche
        gw.rueckwaerts = Rueckwaertssuche(echo=ausgabe.echo)
    if a.baresip:
        from sipbruecke import BaresipCtrl, SipBruecke
        host, _, port = a.baresip.rpartition(":")
        bruecke = SipBruecke(gw, None)
        bruecke.ctrl = gw.sip = BaresipCtrl((host or "127.0.0.1", int(port)), bruecke.bei_sip, echo=ausgabe.echo)
        gw.zuhoerer.append(bruecke.bei_telefon)
        gw.sip.start()
    if a.portal:
        import portal
        srv = portal.starte(a.portal, gw)
        host, port = srv.server_address[:2]
        print(f"Portal: {'https' if srv.tls else 'http'}://{host}:{port}/ "
              f"(Steuerung {'frei' if a.steuerung else 'gesperrt'})", flush=True)
    return betrieb(a, gw)


if __name__ == "__main__":
    raise SystemExit(main())

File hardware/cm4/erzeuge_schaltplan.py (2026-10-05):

#!/usr/bin/env python3
# SPDX-License-Identifier: GPL-3.0-or-later
"""Erzeugt den hierarchischen KiCad-Schaltplan des Sopho2SIP-Trägers für das Raspberry Pi Compute Module 4.

  hardware/cm4/erzeuge_schaltplan.py            → sopho2sip-cm4.kicad_sch (Wurzel) + Blätter, .kicad_pro
  hardware/cm4/erzeuge_schaltplan.py --pruefen  → zusätzlich ERC und Abgleich der Netzliste mit SOLL (alle Blätter)

Wurzelblatt: Funktionsblöcke als hierarchische Blätter, über Blattpins verdrahtet.
  CM4            – beide 100-poligen Stecker, GPIO_VREF, Abblockung, nRPIBOOT-Jumper, Status-LEDs
  Versorgung/USB – USB-C (5 V + USB 2.0 für rpiboot/eMMC-Flashen), Polyfuse, TVS, ESD
  µSD            – Kartensockel für CM4 Lite (Lastschalter wie CM4-Datenblatt, Figure 3)
  Ethernet       – 10/100-MagJack mit LEDs, ESD (wie CM4-Datenblatt, Figure 2)
  Audio-Codec, Sprechweg, RS-232, Bedienung – dieselben Blöcke wie der HAT (hardware/hat/erzeuge_schaltplan.py)
Pinbelegung des CM4: Raspberry Pi „Compute Module 4 Datasheet“ (Tabelle der Pins 1–200), siehe CM4_PINS.
"""
from __future__ import annotations

import pathlib
import sys

HIER = pathlib.Path(__file__).resolve().parent
sys.path.insert(0, str(HIER.parent))
sys.path.insert(0, str(HIER.parent / "hat"))
import kicadgen as kg  # noqa: E402
from kicadgen import Blatt  # noqa: E402
import erzeuge_schaltplan as hat  # noqa: E402

NAME = "sopho2sip-cm4"
FP_R, FP_C, FP_C10 = hat.FP_R, hat.FP_C, hat.FP_C10
FP_C47 = "Capacitor_SMD:C_1206_3216Metric"
FP_LED = hat.FP_LED

# ------------------------------------------------------------------------------------------------------------------
# CM4-Pins (Datenblatt „Raspberry Pi Compute Module 4“, Pinout-Tabelle; Stecker 1 = 1–100, Stecker 2 = 101–200)
# ------------------------------------------------------------------------------------------------------------------
CM4_PINS = """
1 GND|2 GND|3 Ethernet_Pair3_P|4 Ethernet_Pair1_P|5 Ethernet_Pair3_N|6 Ethernet_Pair1_N|7 GND|8 GND|
9 Ethernet_Pair2_N|10 Ethernet_Pair0_N|11 Ethernet_Pair2_P|12 Ethernet_Pair0_P|13 GND|14 GND|15 Ethernet_nLED3|
16 Ethernet_SYNC_IN|17 Ethernet_nLED2|18 Ethernet_SYNC_OUT|19 Ethernet_nLED1|20 EEPROM_nWP|21 Pi_nLED_Activity|
22 GND|23 GND|24 GPIO26|25 GPIO21|26 GPIO19|27 GPIO20|28 GPIO13|29 GPIO16|30 GPIO6|31 GPIO12|32 GND|33 GND|
34 GPIO5|35 ID_SC|36 ID_SD|37 GPIO7|38 GPIO11|39 GPIO8|40 GPIO9|41 GPIO25|42 GND|43 GND|44 GPIO10|45 GPIO24|
46 GPIO22|47 GPIO23|48 GPIO27|49 GPIO18|50 GPIO17|51 GPIO15|52 GND|53 GND|54 GPIO4|55 GPIO14|56 GPIO3|57 SD_CLK|
58 GPIO2|59 GND|60 GND|61 SD_DAT3|62 SD_CMD|63 SD_DAT0|64 SD_DAT5|65 GND|66 GND|67 SD_DAT1|68 SD_DAT4|
69 SD_DAT2|70 SD_DAT7|71 GND|72 SD_DAT6|73 SD_VDD_OVERRIDE|74 GND|75 SD_PWR_ON|76 Reserved|77 +5V|78 GPIO_VREF|
79 +5V|80 SCL0|81 +5V|82 SDA0|83 +5V|84 CM4_3.3V|85 +5V|86 CM4_3.3V|87 +5V|88 CM4_1.8V|89 WL_nDisable|
90 CM4_1.8V|91 BT_nDisable|92 RUN_PG|93 nRPIBOOT|94 AnalogIP1|95 PI_LED_nPWR|96 AnalogIP0|97 Camera_GPIO|
98 GND|99 GLOBAL_EN|100 nEXTRST|101 USB_OTG_ID|102 PCIe_CLK_nREQ|103 USB_N|104 Reserved|105 USB_P|
106 Reserved|107 GND|108 GND|109 PCIe_nRST|110 PCIe_CLK_P|111 VDAC_COMP|112 PCIe_CLK_N|113 GND|114 GND|
115 CAM1_D0_N|116 PCIe_RX_P|117 CAM1_D0_P|118 PCIe_RX_N|119 GND|120 GND|121 CAM1_D1_N|122 PCIe_TX_P|
123 CAM1_D1_P|124 PCIe_TX_N|125 GND|126 GND|127 CAM1_C_N|128 CAM0_D0_N|129 CAM1_C_P|130 CAM0_D0_P|131 GND|
132 GND|133 CAM1_D2_N|134 CAM0_D1_N|135 CAM1_D2_P|136 CAM0_D1_P|137 GND|138 GND|139 CAM1_D3_N|140 CAM0_C_N|
141 CAM1_D3_P|142 CAM0_C_P|143 HDMI1_HOTPLUG|144 GND|145 HDMI1_SDA|146 HDMI1_TX2_P|147 HDMI1_SCL|148 HDMI1_TX2_N|
149 HDMI1_CEC|150 GND|151 HDMI0_CEC|152 HDMI1_TX1_P|153 HDMI0_HOTPLUG|154 HDMI1_TX1_N|155 GND|156 GND|
157 DSI0_D0_N|158 HDMI1_TX0_P|159 DSI0_D0_P|160 HDMI1_TX0_N|161 GND|162 GND|163 DSI0_D1_N|164 HDMI1_CLK_P|
165 DSI0_D1_P|166 HDMI1_CLK_N|167 GND|168 GND|169 DSI0_C_N|170 HDMI0_TX2_P|171 DSI0_C_P|172 HDMI0_TX2_N|
173 GND|174 GND|175 DSI1_D0_N|176 HDMI0_TX1_P|177 DSI1_D0_P|178 HDMI0_TX1_N|179 GND|180 GND|181 DSI1_D1_N|
182 HDMI0_TX0_P|183 DSI1_D1_P|184 HDMI0_TX0_N|185 GND|186 GND|187 DSI1_C_N|188 HDMI0_CLK_P|189 DSI1_C_P|
190 HDMI0_CLK_N|191 GND|192 GND|193 DSI1_D2_N|194 DSI1_D3_N|195 DSI1_D2_P|196 DSI1_D3_P|197 GND|198 GND|
199 HDMI0_SDA|200 HDMI0_SCL
"""
PIN = {int(e.split()[0]): e.split()[1] for e in CM4_PINS.replace("\n", "").split("|") if e.strip()}
NR = {}
for n, nm in PIN.items():
    NR.setdefault(nm, []).append(n)
assert sorted(PIN) == list(range(1, 201))


def _e(name: str, typ: str = "bidirectional") -> tuple:
    return (str(NR[name][0]), name, typ)


GPIO_RECHTS = [_e(f"GPIO{i}") for i in range(2, 28)]
J1_LINKS = [_e("GPIO_VREF", "power_in"), None, _e("nRPIBOOT", "input"), None, _e("Pi_nLED_Activity", "open_collector"),
            None, _e("PI_LED_nPWR", "output"), _e("RUN_PG"), _e("GLOBAL_EN", "input"), _e("nEXTRST", "output"),
            _e("WL_nDisable", "input"), _e("BT_nDisable", "input"), _e("EEPROM_nWP", "input"), None,
            _e("SD_PWR_ON", "output"), _e("SD_CLK", "output"), _e("SD_CMD"), _e("SD_DAT0"), _e("SD_DAT1"),
            _e("SD_DAT2"), _e("SD_DAT3"), _e("SD_DAT4"), _e("SD_DAT5"), _e("SD_DAT6"), _e("SD_DAT7"),
            _e("SD_VDD_OVERRIDE", "input"), None,
            _e("Ethernet_Pair0_P"), _e("Ethernet_Pair0_N"), _e("Ethernet_Pair1_P"), _e("Ethernet_Pair1_N"),
            _e("Ethernet_Pair2_P"), _e("Ethernet_Pair2_N"), _e("Ethernet_Pair3_P"), _e("Ethernet_Pair3_N"),
            _e("Ethernet_nLED1", "open_collector"), _e("Ethernet_nLED2", "open_collector"),
            _e("Ethernet_nLED3", "open_collector"), _e("Ethernet_SYNC_IN", "input"), _e("Ethernet_SYNC_OUT", "output"),
            None, _e("AnalogIP0", "input"), _e("AnalogIP1", "input"), _e("Camera_GPIO"), (str(76), "Reserved", "passive"),
            _e("SCL0"), _e("SDA0"), _e("ID_SD"), _e("ID_SC")]


def _gruppe(name, typ, bereich):
    return [(str(n), name, typ) for n in NR[name] if n in bereich]


J1_OBEN = [_gruppe("+5V", "power_in", range(1, 101)), _gruppe("CM4_3.3V", "power_out", range(1, 101)),
           _gruppe("CM4_1.8V", "power_out", range(1, 101))]
J1_UNTEN = [_gruppe("GND", "power_in", range(1, 101))]
_j2_signale = [(str(n), PIN[n], "bidirectional") for n in range(101, 201) if PIN[n] != "GND"]
_usb = [e for e in _j2_signale if e[1] in ("USB_OTG_ID", "USB_N", "USB_P")]
_rest = [e for e in _j2_signale if e not in _usb]
_rest.sort(key=lambda e: (e[1].split("_")[0], e[1]))
J2_LINKS = _usb + [None] + _rest[:len(_rest) // 2 - 2]
J2_RECHTS = _rest[len(_rest) // 2 - 2:]
J2_UNTEN = [_gruppe("GND", "power_in", range(101, 201))]
for teil in (J1_LINKS + GPIO_RECHTS, ):
    pass
_j1 = {e[0] for e in J1_LINKS + GPIO_RECHTS if e} | {e[0] for g in J1_OBEN + J1_UNTEN for e in g}
_j2 = {e[0] for e in J2_LINKS + J2_RECHTS if e} | {e[0] for g in J2_UNTEN for e in g}
assert _j1 == {str(n) for n in range(1, 101)}, set(map(str, range(1, 101))) ^ _j1
assert _j2 == {str(n) for n in range(101, 201)}, set(map(str, range(101, 201))) ^ _j2
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

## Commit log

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2026-10-03 HAT-Entwurf 0.1: KiCad-Schaltplan (isolierte RS-232 auf UART3, WM8731 mit Übertragern)
    - erzeuge_schaltplan.py baut den Plan aus KiCad-Standardsymbolen, Verbindungen über Netznamen
    - Prüfung: ERC 0 Verstöße, KiCad-Netzliste identisch mit Soll-Netzliste (45 Netze)
    - ADuM5211 (Trennung + isolierte 3,3 V) + MAX3232 + DE9; WM8731 + 2 × 600:600 + RJ12; 24LC32 HAT-ID
    - README: Begründungen, config.txt, offene Prüfpunkte vor der Fertigung
    [sopho2sip-hat.kicad_sch, stueckliste.csv]
2026-10-03 HAT-Schaltplan 0.2: von Hand lesbar gezeichnet (Blöcke, Leitungen, Signalfluss)
    - Generator getrennt in SOLL (Verbindungen) und zeichne() (Anordnung, Leitungen, Labels zwischen Blöcken)
    - Rahmen je Funktionsblock, Abblockkondensatoren an Versorgungsschienen, Trennlinien, eigene Massesymbole
    - Drehung/Spiegelung und relative Textwinkel von KiCad am Testplan bestimmt
    - --pruefen: ERC 0/0, KiCad-Netzliste nach Pin-Gruppen identisch mit SOLL (45 Netze)
    [sopho2sip-hat.kicad_sch, stueckliste.csv]
2026-10-03 HAT-Schaltplan: Blöcke innerhalb des Blattrahmens, Bauteiltexte neben statt über den Bauteilen
    - Rahmen auf 15…405 × 15…282 mm, Sprechweg um 5,08 mm nach links (RJ12 im Rahmen)
    - senkrechte R/C: Name und Wert linksbündig daneben (an Engstellen links), Abstände 10,16 mm
    - JP1 senkrecht unter R3, Labels ID_SD/ID_SC frei; C33/C34/C35 entzerrt
    - Prüfung unverändert: ERC 0/0, Netzliste identisch mit SOLL
    [sopho2sip-hat.kicad_sch]
2026-10-03 CM4-Träger: hierarchischer KiCad-Schaltplan; gemeinsamer Generator kicadgen
    - hardware/kicadgen.py: Symbole, Leitungen, hierarchische Blätter mit Blattpins,
    Projektbibliothek für eigene Symbole, Prüfung (ERC + Pin-Gruppen gegen SOLL)
    - HAT in Blockfunktionen zerlegt (pi_leiste, hat_eeprom, codec, sprechweg, rs232,
    bedienung); Netzliste unverändert, Masse-Symbol an T2IN ohne Textüberdeckung
    - hardware/cm4: Wurzelblatt mit 8 Funktionsblöcken; CM4 (DF40, GPIO_VREF, nRPIBOOT,
    Status-LEDs), USB-C-Versorgung mit rpiboot, µSD für CM4 Lite, Ethernet 10/100
    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
    [bedienung.kicad_sch, cm4.kicad_sch, codec.kicad_sch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]
2026-10-03 CM4-Schaltplan: Einzelblock-Blätter ohne Rahmen, Inhalt zentriert
    kicadgen: Steht nur ein Block auf einem Blatt, entfällt der Rahmen (sein Titel wird
    Blatttitel) und der Inhalt wird auf dem Blatt zentriert (über dem Schriftfeld, auf dem
    1,27-mm-Raster). Hinweistexte der CM4-Blätter an die Schaltungen gerückt.
    [bedienung.kicad_sch, cm4.kicad_sch, codec.kicad_sch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]
2026-10-04 CM4-Träger 0.3: Leiterplatte (4 Lagen, JLCPCB), Ein/Aus-Taster, Lüfter, lieferbare Teile
    Schaltplan
    - Codec TI TLV320AIC3204 statt WM8731 (abgekündigt); MCLK 12 MHz, Reset GPIO26, I²C an GPIO0/1
    - Ein/Aus-Taster an GPIO3 (gpio-shutdown im Betrieb, Bootloader-Wecken im Halt)
    - Lüfterblatt: AO3400A an GPIO12, Freilaufdiode, JST-PH-Anschluss; gpio-fan über SoC-Temperatur
    - Konfig-Taster SW2 und Status-LED D3; Würth RJ45/RJ12, Bourns SM-LP-5001, TPD4E05U06
    - reproduzierbare UUIDs (Schaltplan ↔ Platine bleiben verknüpft), eigene Footprints in hardware/bibliothek
    Leiterplatte (erzeuge_layout.py)
    - 110 × 85 mm, F.Cu / In1 GND / In2 +3V3 / B.Cu, JLC04161H-7628, JLCPCB-Regeln (.kicad_dru)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
    [bedienung.kicad_sch, cm4.kicad_sch, codec.kicad_sch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]
2026-10-04 CM4-Platine: Lage auf dem Blatt frei vom Schriftfeld, alle Bauteiltexte waagerecht
    [sopho2sip-cm4.kicad_pcb]
2026-10-04 CM4-Träger: 4P4C statt DE9, CM4-Platzhalter, ausgerichtete 3D-Modelle
    - Serielle Buchse J3: Würth 615004143821 (4P4C), Adapterkabel auf DE9; HAT behält DE9
    - M1: CM4 als Platzhalter (Stückliste ja, Bestückungsdaten nein), offizielles STEP 1,5 mm über J11/J12
    - 3D-Modelle (Würth RJ45/RJ12/RJ10, Hirose DF40, Bourns SM-LP-5001, ECS-Oszillator) als
    Modellparameter, jede Lage im Rendering geprüft; Herstellermodelle nur lokal (QUELLEN.md)
    - richte_3d_aus.py: CM4-Modell laden/verschieben, Lagedatei für die Footprints
    - Neu geroutet (0,127 mm Standard), DRC ohne Verstöße, 0 offene Verbindungen
    [cm4.kicad_sch, rs232.kicad_sch, sopho2sip-cm4.kicad_pcb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]
2026-10-04 Gehäuse für den CM4-Träger (FreeCAD, FDM-Druck): Biegezungen für die Taster, Lichtleiter, Lüfter, Kollisionsprüfung
    [deckel.stl, gehaeuse.FCStd, gehaeuse.step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]
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2026-10-05 Schaltplan: Hinweise als Textkästen (KiCad bricht um); Texte werden in den Generator zurückgeführt
    [bedienung.kicad_sch, cm4.kicad_sch, codec.kicad_sch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]
2026-10-05 Schaltplan-Generator: geänderte Texte aus KiCad in den Quelltext zurückführen; H1–H4-Hinweis als Literal
    [bedienung.kicad_sch]
2026-10-05 CM4-Schaltplan: Handänderungen übernommen (Handlage für 8 Blätter, 2 Texte zurückgeführt); Kastenhöhen aus gemessenen Zeichenbreiten
    [bedienung.kicad_sch, cm4.kicad_sch, codec.kicad_sch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]
2026-10-05 Schaltplan: Hinweis-Textkästen ohne Rahmen und Hintergrund
    [bedienung.kicad_sch, cm4.kicad_sch, codec.kicad_sch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]
2026-10-05 Platine: Beschriftung als Daten (beschriftung.json) mit Rückführung von Änderungen aus KiCad; feste UUIDs
    [sopho2sip-cm4.kicad_pcb]
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2026-10-05 Gehäuse: Buchsenbeschriftung mittig unter den Ausschnitten (Mitte des Buchsengehäuses statt Footprint-Ursprung)
    [gehaeuse.FCStd, gehaeuse.step, unterschale.stl]
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
